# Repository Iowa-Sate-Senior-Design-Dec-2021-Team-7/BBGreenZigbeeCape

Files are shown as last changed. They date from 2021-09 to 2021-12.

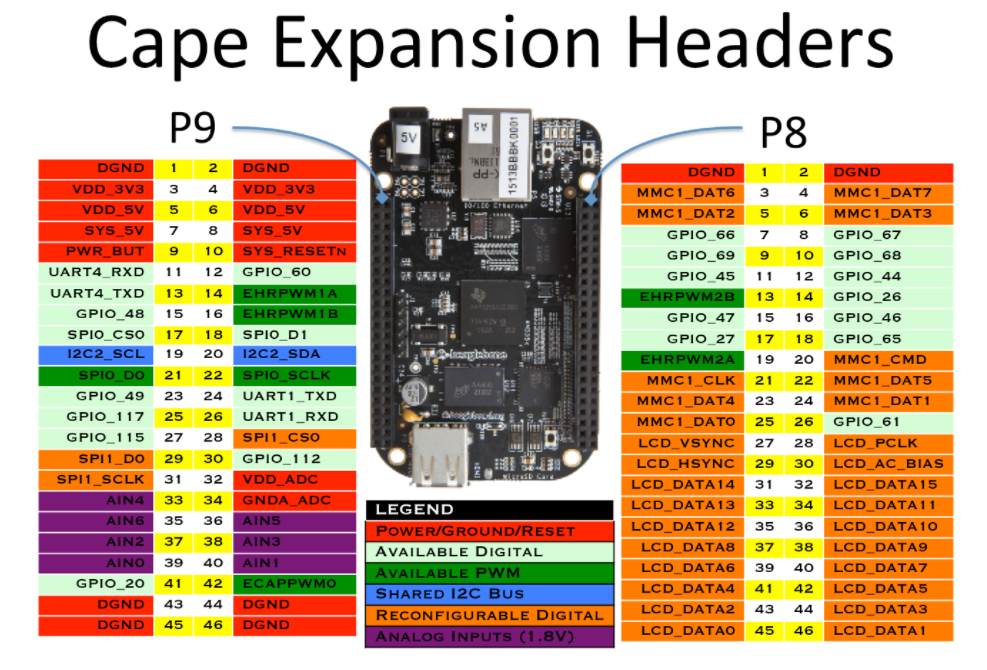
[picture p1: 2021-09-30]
hardware/datasheets/Pictures/Cape_Headers.PNG

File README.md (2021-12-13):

# Iowa State Senior Design December 2021 -- BeagleBone Green Gateway IoT Hub

---

## Website
[Iowa State Senior Design December 2021: Group 7](https://sddec21-07.sd.ece.iastate.edu)

## Hackster.io page
[Hackster.io: BeagleBone Green Wireless Zigbee Cape](https://www.hackster.io/iowa-state-senior-design-dec-2021-proj7/BeagleBone-green-wireless-zigbee-cape-c2da61)

## Project email
sddec21-07@iastate.edu

## Devs:
	- Parker Larsen (pjlarsen)
	- Taylor Weil (tcweil)
	- Sean Griffen (griffens)
	- Sterling Hulling (shulling)

---

See CHANGELOG.md for official release updates/changes

---

### For a description of devices and code used, go to the Wiki:
[Wiki: Home](https://github.com/iowa-state-senior-design-dec-2021-proj7/BBGreenZigbeeCape/wiki)

### To get started, go to the `Getting Started` Wiki:
[Wiki: Getting Started](https://github.com/iowa-state-senior-design-dec-2021-proj7/BBGreenZigbeeCape/wiki/Getting-Started)

---

### Directory Roles:
	- `hardware/`: for pcb designs created and other hardware-specific resources
	- `firmware/`: for code being deployed on the BeagleBone Green Gateway, IoT cape, or other created daughter boards
	- `software/`: for code not being deployed on a hardware module. i.e. web-servers, apps, and other non-controller code
	- `docs/`: for project documents

---

### Scope:
	Research a new or existing wireless technology and add it to the BeagleBone Green and build an IoT network to demonstrate its new capabilities.

### Stretch scope:
	1. Create a system of printed circuit boards to connect to the Zigbee network to show the capabilities and use cases of the Zigbee network.
	2. Program and debug the CC1352 microcontroller Using UART.
	3. Create a data-collection demo to demonstrate basic interactions between the Cape's Zigbee network and the BeagleBone's capabilities
	4. Extend the demo to demonstrate the BeagleBone controlling/commanding Zigbee network devices
	5. Extend the demo to demonstrate devices on the Zigbee network controlling/commanding other Zigbee network devices

---

### Requirements:
	1. Create printed circuit board to allow the BeagleBone to connect to a Zigbee network.
	2. Establish communication between the Cape and the BeagleBone using UART
	3. Create a data-collection demo to demonstrate basic interactions between the Cape's Zigbee network and the BeagleBone's capabilities

### Stretch Requirements:
	1. Create a system of printed circuit boards to connect to the Zigbee network to show the capabilities and use cases of the Zigbee network.
	2. Program and the CC1352 microcontroller using UART.
	3. Extend the communication between the Cape and the BeagleBone to SPI and I2C
	4. Create a demo to show the uses of the BeagleBone's new capabilities
		1. Show that data can be collected from devices on the Cape's Zigbee network
		2. Show that the BeagleBone can see devices on the Cape's Zigbee network and what each device does
		3. Show that the BeagleBone can send commands to devices on the Cape's Zigbee network
		4. Show that devices on the Cape's Zigbee network can send commands to other devices on the same network
	5. Build in support for IFTT using the BeagleBone as an interface for devices on the Cape's Zigbee network
	6. Build in support for MQTT using the BeagleBone as an interface for devices on the Cape's Zigbee network
	7. Build in support for home automation software (HomeAssistant and/or OpenHAB) using the BeagleBone as an interface for devices on the Cape's Zigbee network

---

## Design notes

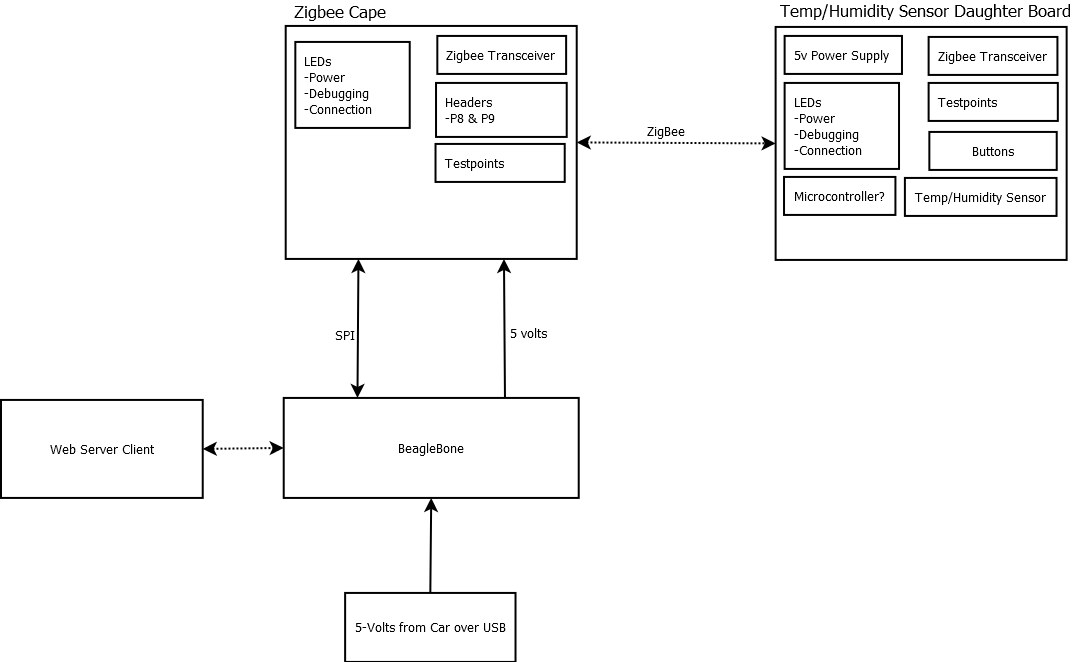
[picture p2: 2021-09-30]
docs/concepts/BlockDiagram.png

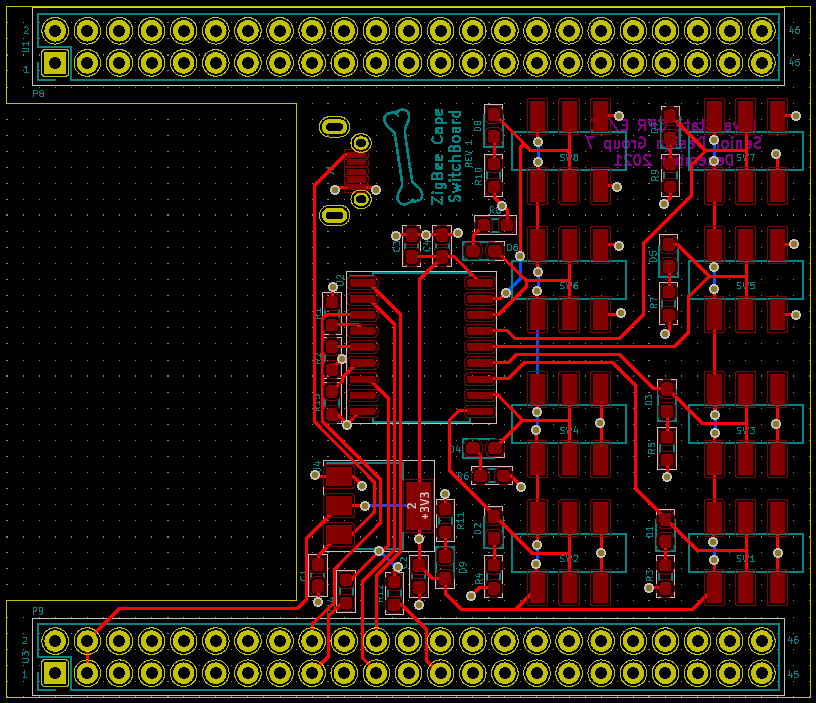
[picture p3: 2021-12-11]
hardware/datasheets/Pictures/SwitchBoard Layout.PNG

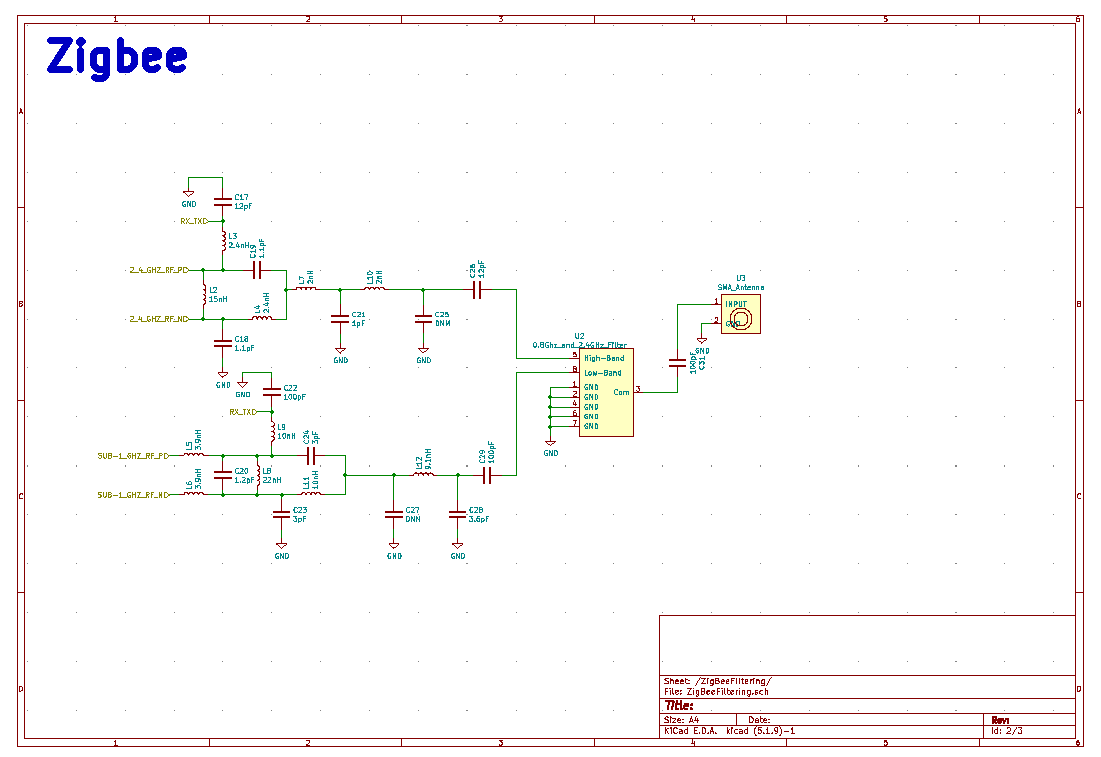
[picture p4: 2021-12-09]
hardware/datasheets/Pictures/SchematicZigBee.PNG

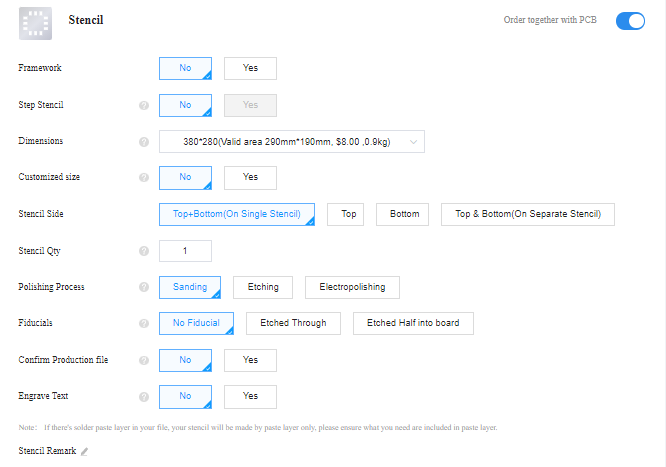
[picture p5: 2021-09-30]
hardware/datasheets/Pictures/JLCStencil.PNG

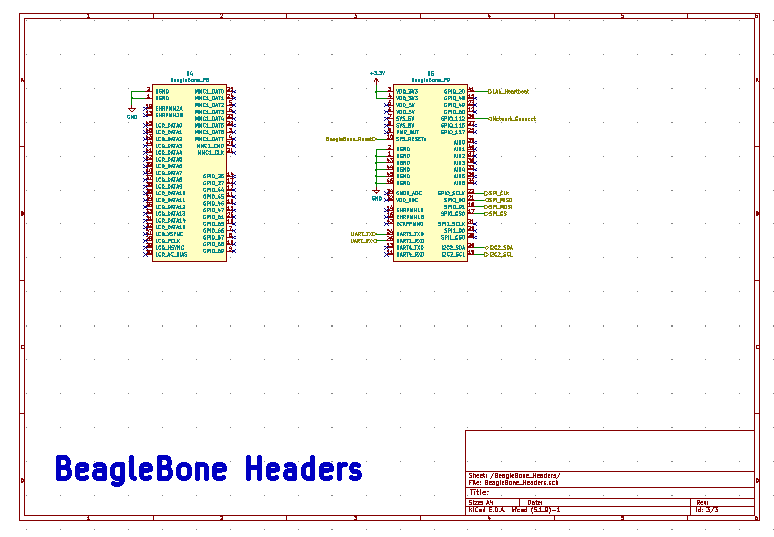
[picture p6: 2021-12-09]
hardware/datasheets/Pictures/SchematicBeagleBoneHeaders.PNG

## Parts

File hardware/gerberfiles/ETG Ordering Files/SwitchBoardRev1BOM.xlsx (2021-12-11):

REF | Value | Footpring |  | Digikey Part number | Quantity per board | Total Quantity
> C1, C2, C4 | 10uF | Capacitor_SMD:C_0603_1608Metric_Pad1.08x0.95mm_HandSolder | ~ | 1276-1038-1-ND | 3 | 7
C3 | 1uF | Capacitor_SMD:C_0603_1608Metric_Pad1.08x0.95mm_HandSolder | ~ | 311-1372-1-ND | 1 | 3
> D1-D9 | RED | Diode_SMD:D_0603_1608Metric_Pad1.05x0.95mm_HandSolder | ~ | 732-4978-1-ND | 9 | 19
J1 | USB_B_Micro | microusb:UJ2-MIBH2-4-SMT-TR | ~ | 102-4007-1-ND | 1 | 3
> R1, R2, R15 | 10k | Resistor_SMD:R_0603_1608Metric_Pad0.98x0.95mm_HandSolder | ~ | RMCF0603FT10K0CT-ND | 3 | 7
> R3-R11 | 100 | Resistor_SMD:R_0603_1608Metric_Pad0.98x0.95mm_HandSolder | ~ | 118-CR0603AFX-1000ELFCT-ND | 9 | 19
R12 | DNP | Resistor_SMD:R_0603_1608Metric_Pad0.98x0.95mm_HandSolder | ~ |  | 1 | 3
R14 | 0 | Resistor_SMD:R_0603_1608Metric_Pad0.98x0.95mm_HandSolder | ~ | 541-0.0GCT-ND | 1 | 3
> SW1-SW8 | SW_SPDT | DPDT_Switch:DPDT | ~ | 401-2002-1-ND | 8 | 17
U1 | BeagleBone_P8 | Connector_PinHeader_2.54mm:PinHeader_2x23_P2.54mm_Vertical |  | 1528-1365-ND | 1 | 3
U2 | MCP23S08 | Package_SO:SOIC-18W_7.5x11.6mm_P1.27mm |  | MCP23S08-E/SO-ND | 1 | 3
U3 | BeagleBone_P9 | Connector_PinHeader_2.54mm:PinHeader_2x23_P2.54mm_Vertical |  | NA | 1 | 3
U4 | NCP1117-3.3_SOT223 | Package_TO_SOT_SMD:SOT-223-3_TabPin2 | http://www.onsemi.com/pub_link/Collateral/NCP1117-D.PDF | NCP1117ST33T3GOSCT-ND | 1 | 3

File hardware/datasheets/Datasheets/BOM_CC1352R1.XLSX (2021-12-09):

Design Modify Date = Tuesday, November 06, 2018
RevCode = B
Title = LAUNCHXL-CC1352R1
Part Number | Quantity | Part Reference | Value | Description | Vendor | Vendor Part Number
02-07617 | 8 | C1 C9 C11 C15 C81 C88 C89 C91 | 12pF | CAPACITOR, CERAMIC C0G/NP0, 12pF, 50V, -5%/+5%, -55DEGC/+125DEGC, 0402, SMD | MURATA | GRM1555C1H120JA01D
02-07775 | 8 | C2 C3 C4 C7 C50 C109 C166 C484 | 10nF | CAPACITOR, CERAMIC X7R, 10nF, 25V, -10%/+10%, -55DEGC/+125DEGC, 0402, SMD | MURATA | GRM155R71E103KA01D
02-06085 | 7 | C6 C78 C79 C80 C83 C84 C87 | 100nF | CAPACITOR, CERAMIC X5R, 100nF, 10V, -10%/+10%, -55DEGC/+85DEGC, 0201, SMD | MURATA | GRM033R61A104KE84D
02-07861 | 40 | C8 C30 C38 C39 C43 C46 C70 C71 C72 C73 C74 C75 C110 C114 C115 C116 C118 C119 C120 C125 C126 C127 C139 C140 C141 C152 C154 C158 C161 C162 C164 C175 C220 C221 C342 C351 C441 C451 C481 C485 | 0.1uF | CAPACITOR, CERAMIC X7R, 0.1uF, 25V, -10%/+10%, -55DEGC/+125DEGC, 0402, SMD | MURATA | GRM155R71E104KE14D
02-07926 | 2 | C12 C21 | 1.1pF | CAPACITOR, CERAMIC C0G/NP0, 1.1pF, 50V, -0.1pF/+0.1pF, -55DEGC/+125DEGC, 0402, SMD | MURATA | GRM1555C1H1R1BA01D
02-07927 | 1 | C13 | 1pF | CAPACITOR, CERAMIC C0G/NP0, 1pF, 50V, -0.1pF/+0.1pF, -55DEGC/+125DEGC, 0402, SMD | MURATA | GRM1555C1H1R0BA01D
DNM | 0 | C14 | DNM | DNM | DNM | DNM
DNM | 0 | C24 | DNM | DNM | DNM | DNM
02-07940 | 1 | C31 | 1.2pF | CAPACITOR, CERAMIC C0G/NP0, 1.2pF, 50V, -0.1pF/ +0.1pF, -55DEGC/+125DEGC, 0402, SMD | MURATA | GRM1555C1H1R2BA01D
02-07619 | 3 | C32 C36 C482 | 100pF | CAPACITOR, CERAMIC C0G/NP0, 100pF, 50V, -5%/+5%, -55DEGC/+125DEGC, 0402, SMD | MURATA | GRM1555C1H101JA01D
02-07625 | 2 | C33 C41 | 3pF | CAPACITOR, CERAMIC C0G/NP0, 3pF, 50V, -0.25pF/+0.25pF, -55DEGC/+125DEGC, 0402, SMD | MURATA | GRM1555C1H3R0CA01D
DNM | 0 | C34 | DNM | DNM | DNM | DNM
02-07631 | 1 | C35 | 3.6pF | CAPACITOR, CERAMIC C0G/NP0, 3.6pF, 50V, -0.25pF/+0.25pF, -55DEGC/+125DEGC, 0402, SMD | MURATA | GRM1555C1H3R6CA01D
DNM | 0 | C37 C483 | DNM | DNM | DNM | DNM
02-07863 | 10 | C40 C42 C44 C128 C133 C136 C137 C138 C145 C231 | 1uF | CAPACITOR, CERAMIC X5R, 1uF, 16V, -10%/+10%, -55DEGC/+85DEGC, 0402, SMD | MURATA | GRM155R61C105KA12D
02-06058 | 12 | C45 C48 C49 C143 C144 C149 C151 C155 C157 C159 C160 C163 | 2.2uF | CAPACITOR, CERAMIC X5R, 2.2uF, 25V, -10%/+10%, -55DEGC/+85DEGC, 0402, SMD | MURATA | GRM155R61E225KE11D
02-07776 | 3 | C47 C153 C172 | 15pF | CAPACITOR, CERAMIC C0G/NP0, 15pF, 50V, -5%/+5%, -55DEGC/+125DEGC, 0402, SMD | MURATA | GRM1555C1H150JA01D
02-07629 | 2 | C85 C86 | 4.7uF | CAPACITOR, CERAMIC X5R, 4.7uF, 6.3V, -20%/+20%, -55DEGC/+85DEGC, 0402, SMD | MURATA | GRM155R60J475ME87D
02-04479 | 1 | C108 | 33nF | CAPACITOR, CERAMIC X7R, 33nF, 25V, -10%/+10%, -55DEGC/+125DEGC, 0402, SMD | MURATA | GRM155R71E333KA88D
02-05897 | 1 | C111 | 3.3uF | CAPACITOR, CERAMIC X5R, 3.3uF, 10V, -10%/+10%, -55DEGC/+85DEGC, 0603, SMD | MURATA | GRM188R61A335KE15D
02-04936 | 1 | C112 | 220uF | CAPACITOR, TANTALUM, 220uF, 10V, -10%/+10%, -55DEGC/+125DEGC, 7343-20, SMD | AVX | TPSY227K010R0100
02-07053 | 7 | C113 C156 C165 C171 C174 C331 C341 | 22uF | CAPACITOR, CERAMIC, X5R, 22uF, 6.3V, -20%/+20%, -55DEGC/+85DEGC, 0603, SMD | MURATA | GRM188R60J226MEA0D
02-05775 | 6 | C117 C121 C122 C142 C147 C168 | 10uF | CAPACITOR, CERAMIC X7R, 10uF, 16V, -10%/+10%, -55DEGC/+125DEGC, 0805, SMD | SAMSUNG ELECTRO-MECHANICS | CL21B106KOQNNNE
02-08708 | 2 | C123 C135 | 270pF | CAPACITOR, CERAMIC C0G/NP0, 270pF, 50V, -1%/+1%, -55DEGC/+125DEGC, 0402, SMD | MURATA | GRM1555C1H271FA01D
DNM | 0 | C124 C132 C134 C170 | DNM | DNM | DNM | DNM
02-00613 | 1 | C129 | 470pF | CAPACITOR, CERAMIC X7R, 470pF, 50V, -10%/+10%, -55DEGC/+125DEGC, 0402, SMD | MURATA | GRM155R71H471KA01D
02-02070 | 1 | C130 | 1nF | CAPACITOR, CERAMIC X7R, 1nF, 50V, -10%/+10%, -55DEGC/+125DEGC, 0402, SMD | MURATA | GRM155R71H102KA01D
02-05294 | 1 | C131 | 22nF | CAPACITOR, CERAMIC X7R, 22nF, 25V, -10%/+10%, -55DEGC/+125DEGC, 0402, SMD | MURATA | GRM155R71E223KA61D
02-07728 | 1 | C146 | 47uF | CAPACITOR, CERAMIC X5R, 47uF, 10V, -20%/+20%, -55DEGC/+85DEGC, 0805, SMD | MURATA | GRM21BR61A476ME15L
DNM | 0 | C169 | DNM | DNM | DNM | DNM
02-08923 | 1 | C486 | 220uF | CAPACITOR, CERAMIC X5R, 220uF, 6.3V, -20%/+20%, -55DEGC/+85DEGC, 1210, SMD | MURATA | GRM32ER60J227ME05L
15-01023 | 2 | CR1 CR5 | LPL296-J2L2-25 | OPTO, LED, GREEN COLOR, 562nm, 0.02A, 0.08W, 0603, SMD | OSRAM | LP L296-J2L2-25
15-01169 | 2 | CR2 CR4 | LS L296-P2Q2-1 | OPTO, LED, SUPER RED COLOR, 630nm, 1.8V TO 2.3V, 0.06A, 0603, SMD | OSRAM | LS L296-P2Q2-1
14-06172 | 1 | CR6 | TPD4E004DRY | DIODE, PROTECTION, ESD ARRAY, 4 CHANNEL, 6V TO 8V, -40DEGC/+85DEGC, SON6, SMD | TEXAS INSTRUMENTS | TPD4E004DRYR
14-05493 | 2 | CR7 CR8 | TPD6E004RSER | DIODE, PROTECTION, ESD ARRAY - 6 CHANNELS, 7V, -40DEGC/+85DEGC, QFN8, SMD | TEXAS INSTRUMENTS | TPD6E004RSER
DNM | 0 | CR14 | DNM | DNM | DNM | DNM
14-03076 | 1 | CR15 | MBR130T1 | DIODE, SCHOTTKY, 1A, 30V, -65DEGC/+125DEGC, SOD-123, SMD | ON SEMICONDUCTOR | MBR130T1G
04-00470 | 4 | FL1 FL2 FL4 FL5 | BLM18HE152SN1 | FILTER, EMI, 1500@100MHz, -55DEGC/+125DEGC, 0603, SMD | MURATA | BLM18HE152SN1D
04-00869 | 1 | FL3 | LFD21829MDKED859 | FILTER, OTHER, 698MHz TO 960MHz / 1710MHz TO 2690MHz, -40DEGC/+85DEGC, SMD | MURATA | LFD21829MDKED859
06-04997 | 2 | J1 J2 | SSQ-110-23-L-D | CONNECTOR, HEADER, FEMALE, STRAIGHT, 2 ROWS, 20 ROWS, 2.54mm, PTH | SAMTEC | SSQ-110-23-L-D
06-04998 | 1 | J6 | 105164-0001 | CONNECTOR, USB, FEMALE, RIGHT ANGLE, 1 ROW, 5 PINS, PITCH 0.65mm, SMD | MOLEX | 105164-0001
06-02188 | 1 | J7 | SMA-10V21-TGG | CONNECTOR, COAX, RF, FEMALE, STRAIGHT, 1 PIN, SMD | HUS-TSAN | SMA-10V21-TGG
03-06637 | 1 | L11 | 15nH | INDUCTOR, RF, CHIP, NON-MAGNETIC CORE, 15nH, -5%/+5%, 0.3A, -55DEGC/+125DEGC, 0402, SMD | MURATA | LQG15HS15NJ02D
03-07526 | 2 | L12 L21 | 2.4nH | INDUCTOR, RF, CHIP, NON-MAGNETIC CORE, 2.4nH, -0.3nH/+0.3nH, 0.3A, -55DEGC/+125DEGC, 0402, SMD | MURATA | LQG15HS2N4S02D
03-07527 | 2 | L13 L14 | 2nH | INDUCTOR, RF, CHIP, NON-MAGNETIC CORE, 2nH, -0.3nH/+0.3nH, 0.3A, -55DEGC/+125DEGC, 0402, SMD | MURATA | LQG15HS2N0S02D
03-06630 | 2 | L31 L41 | 3.9nH | INDUCTOR, RF, CHIP, NON-MAGNETIC CORE, 3.9nH, -0.3nH/+0.3nH, 0.3A, -55DEGC/+125DEGC, 0402, SMD | MURATA | LQG15HS3N9S02D
03-07529 | 1 | L32 | 22nH | INDUCTOR, RF, CHIP, NON-MAGNETIC CORE, 22nH, -5%/+5%, 0.3A, -55DEGC/+125DEGC, 0402, SMD | MURATA | LQG15HS22NJ02D
03-06635 | 2 | L33 L42 | 10nH | INDUCTOR, RF, CHIP, NON-MAGNETIC CORE, 10nH, -5%/+5%, 0.3A, -55DEGC/+125DEGC, 0402, SMD | MURATA | LQG15HS10NJ02D
03-07976 | 1 | L34 | 9.1nH | INDUCTOR, RF, CHIP, 0402, NON-MAGNETIC CORE, 9.1nH, -5%/+5%, 0.5A, -55DEGC/+125DEGC, 0402, SMD | MURATA | LQG15HS9N1J02D
03-07266 | 1 | L331 | 6.8uH | INDUCTOR, STANDARD, CHIP, FERRITE CORE, SHIELDED, 6.8uH, -20%/+20%, 1.1A, -55DEGC/+125DEGC, 0805, SMD | TDK | MLZ2012N6R8LT000
04-00050 | 3 | L332 L333 L334 | BLM21PG221SN1 | FILTER, EMI, FERRITE BEAD, 220@100MHz, -25%/+25%, -55DEGC/+125DEGC, 0805, SMD | MURATA | BLM21PG221SN1D
19-00498 | 11 | M1 M2 M3 M4 M5 M6 M7 M8 M9 M10 M14 | SNT-100-BK-G | MECHANIC, SHUNT, CURRENT RATING 4.3A PER PIN, 2.54 X 5.08 X 6.1mm, BLACK | SAMTEC | SNT-100-BK-G
DNM | 0 | M11 M12 M13 | DNM | DNM | DNM | DNM
13-04664 | 4 | M15 M16 M17 M18 | DCB-10 | MECHANIC, ACCESSORY, SPACER SUPPORT, PCB DIA. 3mm, NYLON 66, PTH | SUZHOU SOLY ELECTRICIAN | DCB-10
06-05038 | 3 | P1 P2 P10 | BB02-HC031-KB1-603000 | CONNECTOR, HEADER, MALE, STRAIGHT, 1 ROW, 3 PINS, PITCH 2.54mm, PTH | GRADCONN | BB02-HC031-KB1-603000
06-05049 | 1 | P4 | BB02-HJ221-KB1-603000 | CONNECTOR, HEADER, MALE, STRAIGHT, 2 ROWS, 22 PINS, PITCH 2.54mm, PTH | GRADCONN | BB02-HJ221-KB1-603000
06-00166 | 2 | P5 P7 | FTSH-105-01-F-DV-K | CONNECTOR, HEADER, MALE, STRAIGHT, 2 ROWS, 10 PINS, PITCH 1.27mm, SMD | SAMTEC | FTSH-105-01-F-DV-K
06-04999 | 1 | P6 | BB02-HJ041-KB1-603000 | CONNECTOR, HEADER, MALE, STRAIGHT, 2 ROWS, 4 PINS, PITCH 2.54mm, PTH | GRADCONN | BB02-HJ041-KB1-603000
DNM | 0 | P8 | DNM | DNM | DNM | DNM
06-05051 | 2 | P11 P12 | MM5829-2700 | CONNECTOR, COAX, MALE, UP TO 12GHz, 30V, SMD | MURATA | MM5829-2700RJ4
19-00925 | 1 | PCB1 | WCS038 | NON COMPONENT, PCB, TEXAS INSTRUMENTS | TEXAS INSTRUMENTS | PCB
01-20043 | 4 | R1 R48 R49 R51 | 0 | RESISTOR, THICK FILM, 0, 0R/+0.02R, 0.1W, 75V, -55DEGC/+155DEGC, 0603, SMD | VISHAY | CRCW06030000Z0EC
01-22488 | 3 | R2 R3 R58 | 3.3k | RESISTOR, THICK FILM, 3.3k, -5%/+5%, 0.063W, 50V, -55DEGC/+155DEGC, 0402, SMD | VISHAY | CRCW04023K30JNED
01-22487 | 1 | R11 | 2.2k | RESISTOR, THICK FILM, 2.2k, -5%/+5%, 0.063W, 50V, -55DEGC/+155DEGC, 0402, SMD | VISHAY | CRCW04022K20JNED
01-22345 | 2 | R14 R23 | 180 | RESISTOR, THICK FILM, 180, -5%/+5%, 0.063W, 50V, -55DEGC/+155DEGC, 0402, SMD | VISHAY | CRCW0402180RJNED
01-22346 | 2 | R15 R25 | 220 | RESISTOR, THICK FILM, 220, -5%/+5%, 0.063W, 50V, -55DEGC/+155DEGC, 0402, SMD | VISHAY | CRCW0402220RJNED
01-22353 | 1 | R17 | 10k | RESISTOR, THICK FILM, 10k, -5%/+5%, 0.063W, 50V, -55DEGC/+155DEGC, 0402, SMD | VISHAY | CRCW040210K0JNED
01-22489 | 3 | R18 R126 R353 | 4.7k | RESISTOR, THICK FILM, 4.7k, -5%/+5%, 0.063W, 50V, -55DEGC/+155DEGC, 0402, SMD | VISHAY | CRCW04024K70JNED
01-22482 | 4 | R20 R55 R56 R57 | 100 | RESISTOR, THICK FILM, 100, -5%/+5%, 0.063W, 50V, -55DEGC/+155DEGC, 0402, SMD | VISHAY | CRCW0402100RJNED
DNM | 0 | R21 | DNM | DNM | DNM | DNM
01-22486 | 4 | R27 R29 R30 R39 | 1k | RESISTOR, THICK FILM, 1k, -5%/+5%, 0.063W, 50V, -55DEGC/+155DEGC, 0402, SMD | VISHAY | CRCW04021K00JNED
01-22494 | 1 | R28 | 4.87k | RESISTOR, THICK FILM, 4.87k, -1%/+1%, 0.063W, 50V, -55DEGC/+155DEGC, 0402, SMD | VISHAY | CRCW04024K87FKED
01-22481 | 1 | R31 | 51 | RESISTOR, THICK FILM, 51, -5%/+5%, 0.063W, 50V, -55DEGC/+155DEGC, 0402, SMD | VISHAY | CRCW040251R0JNED
01-22477 | 1 | R32 | 33k | RESISTOR, THICK FILM, 33k, -1%/+1%, 0.063W, 50V, -55DEGC/+155DEGC, 0402, SMD | VISHAY | CRCW040233K0FKED
01-22491 | 3 | R33 R132 R151 | 51k | RESISTOR, THICK FILM, 51k, -5%/+5%, 0.063W, 50V, -55DEGC/+155DEGC, 0402, SMD | VISHAY | CRCW040251K0JNED
01-22490 | 4 | R34 R133 R135 R152 | 30k | RESISTOR, THICK FILM, 30k, -5%/+5%, 0.063W, 50V, -55DEGC/+155DEGC, 0402, SMD | VISHAY | CRCW040230K0JNED
DNM | 0 | R46 R47 R52 | DNM | DNM | DNM | DNM
DNM | 0 | R59 R60 | DNM | DNM | DNM | DNM
01-22536 | 5 | R61 R62 R63 R65 R114 | 100k | RESISTOR, THICK FILM, 100k, -1%/+1%, 0.063W, 50V, -55DEGC/+155DEGC, 0402, SMD | TT ELECTRONICS | WCR0402-100KFA
01-04196 | 3 | R82 R83 R92 | 10k | RESISTOR, THICK FILM, 10k, -5%/+5%, 0.05W, 30V, -55DEGC/+155DEGC, 0201, SMD | VISHAY | CRCW020110K0JNED
01-04087 | 1 | R84 | 12k | RESISTOR, THICK FILM, 12k, -1%/+1%, 0.05W, 30V, -55DEGC/+155DEGC, 0201, SMD | VISHAY | CRCW020112K0FKED
01-22476 | 1 | R87 | 1Meg | RESISTOR, THICK FILM, 1M, -1%/+1%, 0.063W, 50V, -55DEGC/+155DEGC, 0402, SMD | VISHAY | CRCW04021M00FKED
01-04172 | 2 | R90 R91 | 1k | RESISTOR, THICK FILM, 1k, -5%/+5%, 0.05W, 30V, -55DEGC/+155DEGC, 0201, SMD | VISHAY | CRCW02011K00JNED
01-04203 | 1 | R93 | 20k | RESISTOR, THICK FILM, 20k, -5%/+5%, 0.05W, 30V, -55DEGC/+155DEGC, 0201, SMD | VISHAY | CRCW020120K0JNED
01-01183 | 1 | R94 | 22 | RESISTOR, THICK FILM, 22, -5%/+5%, 0.063W, 50V, -55DEGC/+155DEGC, 0402, SMD | VISHAY | CRCW040222R0JNED
01-00128 | 4 | R95 R101 R109 R120 | 1.2k | RESISTOR, THICK FILM, 1.2k, -1%/+1%, 0.063W, 50V, -55DEGC/+155DEGC, 0402, SMD | VISHAY | CRCW04021K20FKED
01-22492 | 9 | R96 R97 R98 R105 R117 R118 R119 R136 R351 | 100k | RESISTOR, THICK FILM, 100k, -5%/+5%, 0.063W, 50V, -55DEGC/+155DEGC, 0402, SMD | VISHAY | CRCW0402100KJNED
01-22495 | 4 | R99 R100 R108 R131 | 0 | RESISTOR, THICK FILM, 0, 0.063W, 50V, -55DEGC/+155DEGC, 0402, SMD | VISHAY | CRCW04020000Z0ED
01-00195 | 2 | R102 R110 | 330 | RESISTOR, THICK FILM, 330, -1%/+1%, 0.063W, 50V, -55DEGC/+155DEGC, 0402, SMD | VISHAY | CRCW0402330RFKED
01-04307 | 2 | R103 R112 | 4.99 | RESISTOR, THICK FILM, 4.99, -1%/+1%, 0.063W, 50V, -55DEGC/+155DEGC, 0402, SMD | VISHAY | CRCW04024R99FKED
01-00234 | 3 | R104 R113 R354 | 10 | RESISTOR, THICK FILM, 10, -1%/+1%, 0.063W, 50V, -55DEGC/+155DEGC, 0402, SMD | VISHAY | CRCW040210R0FKED
DNM | 0 | R106 R111 | DNM | DNM | DNM | DNM
01-03527 | 1 | R107 | 1 | RESISTOR, THICK FILM, 1, -1%/+1%, 1W, 200V, -55DEGC/+155DEGC, 1218, SMD | VISHAY | CRCW12181R00FNEK
DNM | 0 | R115 | DNM | DNM | DNM | DNM
01-04658 | 2 | R116 R134 | 60.4k | RESISTOR, THICK FILM, 60.4k, -1%/+1%, 0.063W, 50V, -55DEGC/+155DEGC, 0402, SMD | VISHAY | CRCW040260K4FKED
01-01252 | 1 | R121 | 22k | RESISTOR, THICK FILM, 22k, -5%/+5%, 0.063W, 50V, -55DEGC/+155DEGC, 0402, SMD | VISHAY | CRCW040222K0JNED
01-20687 | 1 | R122 | 0.22 | RESISTOR, THICK FILM, 0.22, -1%/+1%, 0.125W, -55DEGC/+155DEGC, 0402, SMD | VISHAY | RCWE0402R220FKEA
01-06917 | 1 | R123 | 82 | RESISTOR, THICK FILM, 82, -1%/+1%, 0.25W, 200V, -55DEGC/+155DEGC, 1206, SMD | VISHAY | CRCW120682R0FKEA
01-07315 | 1 | R125 | 36.5 | RESISTOR, THICK FILM, 36.5, -1%/+1%, 0.5W, 200V, -55DEGC/+155DEGC, 1210, SMD | VISHAY | CRCW121036R5FKEA
01-01260 | 3 | R127 R128 R129 | 47k | RESISTOR, THICK FILM, 47k, -5%/+5%, 0.063W, 50V, -55DEGC/+155DEGC, 0402, SMD | VISHAY | CRCW040247K0JNED
01-00239 | 1 | R130 | 2.2k | RESISTOR, THICK FILM, 2.2k, -1%/+1%, 0.063W, 50V, -55DEGC/+155DEGC, 0402, SMD | VISHAY | CRCW04022K20FKED
01-04542 | 1 | R137 | 2.61k | RESISTOR, THICK FILM, 2.61k, -1%/+1%, 0.063W, 50V, -55DEGC/+155DEGC, 0402, SMD | VISHAY | CRCW04022K61FKED
DNM | 0 | R138 | DNM | DNM | DNM | DNM
01-04141 | 9 | R140 R141 R142 R143 R144 R145 R146 R147 R148 | 51 | RESISTOR, THICK FILM, 51, -5%/+5%, 0.05W, 30V, -55DEGC/+155DEGC, 0201, SMD | VISHAY | CRCW020151R0JNED
08-00293 | 3 | SW1 SW2 SW3 | 1188E-1K2-V | SWITCH, TACT, 0.05A@250VAC, 0.05A@12VDC, 0.05A, 250V, SMD | DIPTRONICS | 1188E-1K2-V-TR
18-33499 | 1 | U1 | CC1352R1F3RGZ | IC, DIGITAL, WIRELESS, QFN48, SMD | TEXAS INSTRUMENTS | CC1352R1F3RGZT
18-31726 | 1 | U4 | MX25R8035FZUIL0 | IC, MEMORY, FLASH, SERIAL, 8Mbit, 1.65V TO 3.6V, USON8, SMD | MACRONIX | MX25R8035FZUIL0
18-29558 | 1 | U6 | LM4040B25IDCK | IC, ANALOG, PRECISION MICROPOWER SHUNT VOLTAGE REFERENCE, 2.5V, SC70-5, SMD | TEXAS INSTRUMENTS | LM4040B25IDCKR
18-29530 | 3 | U7 U42 U46 | TPS79601DR | IC, ANALOG, ULTRALOW-NOISE, HIGH PSRR, FAST, RF, 1A LOW-DROPOUT LINEAR REGULATORS, VIN:2.7V TO 5.5V, VOUT:1.2V TO 5.5V, SON8, SMD | TEXAS INSTRUMENTS | TPS79601DRBR
18-29288 | 3 | U8 U9 U10 | SN74AVC4T245RSV | IC, DIGITAL, LOGIC, 4bit DUAL-SUPPLY BUS TRANSCEIVER 3 STATE OUTPUT, 1.2V TO 3.6V, UQFN16, SMD | TEXAS INSTRUMENTS | SN74AVC4T245RSVR
18-26311 | 1 | U15 | USB3300-EZK | IC, DIGITAL, INTERFACE, HI-SPEED USB HOST, 3.3V, QFN32-EP, SMD | MICROCHIP | USB3300-EZK
18-30805 | 2 | U33 U38 | TS3A24159DRC | IC, ANALOG, 0.3R DUAL SPDT ANALOG SWITCH DUAL-CHANNEL 2:1 MULTIPLEXER/DEMULTIPLEXER, 1.65V TO 3.6V, SON10-EP, SMD | TEXAS INSTRUMENTS | TS3A24159DRCR
18-27150 | 1 | U34 | SN74LVC2G74DCU | IC, DIGITAL, LOGIC, D-TYPE FLIP-FLOP WITH CLEAR AND PRESET, 1.65V TO 5.5V, VSSOP8, SMD | TEXAS INSTRUMENTS | SN74LVC2G74DCUR
18-33431 | 1 | U35 | ADS127L01IPBS | IC, MIXED, 24-BIT WIDE-BANDWIDTH ANALOG TO DIGITAL CONVERTER, 2.7V TO 3.6V/1.7V TO 3.6V, TQFP32, SMD | TEXAS INSTRUMENTS | ADS127L01IPBS
18-34413 | 1 | U36 | INA118UB | IC, ANALOG, INSTRUMENTATION AMPLIFIER, -/+15V, SO8, SMD | TEXAS INSTRUMENTS | INA118UB
18-34391 | 1 | U37 | THS4551IRUN | IC, ANALOG, LOW NOISE, PRECISION, 150MHz, FULLY DIFFERENTIAL AMPLIFIER, 2.7V TO 5.4V, QFN10-EP, SMD | TEXAS INSTRUMENTS | THS4551IRUNR
18-30809 | 1 | U39 | TS3A4751RUCR | IC, ANALOG, 0.9R LOW-VOLTAGE SINGLE-SUPPLY QUAD SPST ANALOG SWITCH, 1.6V TO 3.6V, QFN14, SMD | TEXAS INSTRUMENTS | TS3A4751RUCR
18-34390 | 1 | U40 | REF6025IDGK | IC, ANALOG, HIGH PRECISION VOLTAGE REFERENCE, VIN:3V TO 5.5V, VOUT:2.5V, VSSOP8, SMD | TEXAS INSTRUMENTS | REF6025IDGKR
18-32984 | 1 | U41 | OPA320AIDBV | IC, ANALOG, RAIL-TO-RAIL I/O CMOS OPERATIONAL AMPLIFIER, -/+0.9V TO 5.5V, SOT23-5, SMD | TEXAS INSTRUMENTS | OPA320AIDBVT
18-32950 | 1 | U43 | LP5907MFX-1.8 | IC, ANALOG, 0.25A LINEAR REGULATOR FOR RF AND ANALOG CIRCUITS-REQUIRES NO BYPASS CAPACITOR, VIN:2.2V TO 5.5V, VOUT: 1.8V, SOT23-5, SMD | TEXAS INSTRUMENTS | LP5907MFX-1.8/NOPB
18-33642 | 1 | U44 | TPS73101DBV | IC, ANALOG, 0.15A LOW DROPOUT REGULATOR WITH REVERSE CURRENT PROTECTION, VIN:1.7V TO 5.5V, VOUT:1.2V TO 5.5V, SOT23-5, SMD | TEXAS INSTRUMENTS | TPS73101DBVR
DNM | 0 | U45 | DNM | DNM | DNM | DNM
18-34886 | 1 | U47 | TPS259530DSG | IC, ANALOG, EFUSE WITH FAST OVERVOLTAGE PROTECTION, 2.7V TO 18V, WSON8-EP, SMD | TEXAS INSTRUMENTS | TPS259530DSGR
18-29511 | 1 | U5 | TM4C1294NCPDTT3R | IC, MICROCONTROLLER, TIVA C SERIES, ARM CRTEX-M4, 2.97V TO 3.63V, TQFP128, SMD | TEXAS INSTRUMENTS | TM4C1294NCPDTT3R
12-00546 | 1 | Y1 | 32.768kHz | CRYSTAL, RESONATOR, 32.768kHz, -20PPM/+20PPM, -40DEGC/+85DEGC, SMD | EPSON | FC-135 32.7680KA-AG0
12-01233 | 1 | Y2 | 48MHz | CRYSTAL, RESONATOR, 48MHz, -20PPM/+20PPM, -40DEGC/+85DEGC, SMD | KYOCERA | CX2016DB48000C0FPLC1
12-00745 | 1 | Y3 | 16MHz | CRYSTAL, RESONATOR, 16MHz, -30PPM/+30PPM, -40DEGC/+85DEGC, SMD | NIHON DEMPA KOGYO | NX3225GA-16.000M-STD-CRG-1
12-00730 | 1 | Y4 | 24MHz | CRYSTAL, RESONATOR, 24MHz, -50PPM/+50PPM, -40DEGC/+85DEGC, SMD | EPSON | FA-238 24.0000MB50X-W0
12-01320 | 1 | Y5 | 16.384MHz | CRYSTAL, OSCILLATOR, XO, 16.384MHz, -50PPM/+50PPM, 3.3V, -20DEGC/+70DEGC, SMD | CTS COMPONENTS | 636L3C016M38400
03-07708 | 1 | Z60 | 3.3nH | INDUCTOR, RF, CHIP, 0402, NON-MAGNETIC CORE, 3.3nH, -0.5nH/+0.5nH, 0.9A, -55DEGC/+125DEGC, 0402, SMD | MURATA | LQW15AN3N3D10D
DNM | 0 | Z61 | DNM | DNM | DNM | DNM
DNM | 0 | Z62 | DNM | DNM | DNM | DNM
02-07850 | 1 | Z63 | 5.6pF | CAPACITOR, CERAMIC C0G, 5.6pF, 50V, -0.25pF/+0.25pF, -55DEGC/+125DEGC, 0402, SMD | MURATA | GRM1555C1H5R6CA01D

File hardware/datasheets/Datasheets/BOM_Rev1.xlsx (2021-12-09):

Reference | Quantity | Value | Footprint | Datasheet | Description | Manufacturer | Digi-Key Part Number | Digi-Key Listing
AE1 | 1 | Antenna |  |  | PCB printed antenna
C1 C2 C3 | 3 | DNM_1uF | 0603 | http://www.calchipelectronics.com/pdf/gmc_series.pdf | ±10% 16V Ceramic Capacitor X5R 0603 (1608 Metric | Cal-Chip Electronics | 2571-GMC10X5R105K16NTTR-ND | GMC10X5R105K16NT CAL-CHIP ELECTRONICS, INC. | Capacitors | DigiKey Marketplace (https://www.digikey.com/en/products/detail/cal-chip-electronics-inc/GMC10X5R105K16NT/13909090)
C10 C11 | 2 | 22uF | 0603 | http://www.calchipelectronics.com/pdf/gmc_series.pdf | ±20% 6.3V Ceramic Capacitor X5R 0603 (1608 Metric) | Cal-Chip Electronics | 2571-GMC10X5R226M6R3NTTR-ND | GMC10X5R226M6R3NT CAL-CHIP ELECTRONICS, INC. | Capacitors | DigiKey Marketplace (https://www.digikey.com/en/products/detail/cal-chip-electronics-inc/GMC10X5R226M6R3NT/13909373)
C12 C14 C17 C26 | 4 | 12pF | 0603 | https://www.murata.com/~/media/webrenewal/support/library/catalog/products/capacitor/mlcc/c02e.ashx?la=en-us | ±5% 50V Ceramic Capacitor C0G, NP0 0603 (1608 Metric) | Murata Electronics | 490-1405-1-ND | GRM1885C1H120JA01D Murata Electronics | Capacitors | DigiKey
C15 | 1 | 1uF | 0603 | https://ds.yuden.co.jp/TYCOMPAS/ut/detail?pn=EMK107BJ105KAHT%20%20&u=M | ±10% 16V Ceramic Capacitor X5R 0603 (1608 Metric) | Taiyo Yuden | 587-3309-1-ND | EMK107BJ105KAHT Taiyo Yuden | Capacitors | DigiKey (https://www.digikey.com/en/products/detail/taiyo-yuden/EMK107BJ105KAHT/4157319)
C18 C19 | 2 | 1.1pF | 0603 | https://api.kemet.com/component-edge/download/datasheet/CBR06C119B5GAC.pdf | ±0.1pF 50V Ceramic Capacitor C0G, NP0 0603 (1608 Metric) | KEMET | 399-16141-1-ND | CBR06C119B5GAC KEMET | Capacitors | DigiKey (https://www.digikey.com/en/products/detail/kemet/CBR06C119B5GAC/7649447)
C20 | 1 | 1.2pF | 0805 | https://www.yageo.com/upload/media/product/productsearch/datasheet/mlcc/UPY-GP_NP0_16V-to-50V_18.pdf | ±0.1pF 50V Ceramic Capacitor C0G, NP0 0805 (2012 Metric) | Yageo | 311-4125-1-ND | CC0805BRNPO9BN1R2 Yageo | Capacitors | DigiKey (https://www.digikey.com/en/products/detail/yageo/CC0805BRNPO9BN1R2/5883872)
C21 | 1 | 1pF | 0603 | http://www.samsungsem.com/kr/support/product-search/mlcc/CL10C010BB8NNNC.jsp | ±0.1pF 50V Ceramic Capacitor C0G, NP0 0603 (1608 Metric) | Samsung Electro-Mechanics | 1276-1095-2-ND | CL10C010BB8NNNC Samsung Electro-Mechanics | Capacitors | DigiKey (https://www.digikey.com/en/products/detail/samsung-electro-mechanics/CL10C010BB8NNNC/3886753)
C22 C29 C31 | 3 | 100pF | 0603 | https://www.murata.com/-/media/webrenewal/support/library/catalog/products/capacitor/ceramiccapacitor/c02e.ashx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 | ±5% 50V Ceramic Capacitor C0G, NP0 0603 (1608 Metric) | Murata Electronics | 490-1427-1-ND | GRM1885C1H101JA01D Murata Electronics | Capacitors | DigiKey (https://www.digikey.com/en/products/detail/murata-electronics/GRM1885C1H101JA01D/586921)
C23 C24 | 2 | 3pF | 0603 | https://www.yageo.com/upload/media/product/productsearch/datasheet/mlcc/UPY-GP_NP0_16V-to-50V_18.pdf | ±0.25pF 50V Ceramic Capacitor C0G, NP0 0603 (1608 Metric) | Yageo | 311-1052-1-ND | CC0603CRNPO9BN3R0 Yageo | Capacitors | DigiKey (https://www.digikey.com/en/products/detail/yageo/CC0603CRNPO9BN3R0/302786)
L14 C25 C27 C30 C32 | 5 | DNM | 0603 | ~ | Parts not mounted
C28 | 1 | 3.6pF | 0603 | https://datasheets.avx.com/C0GNP0-Dielectric.pdf | ±0.25pF 50V Ceramic Capacitor C0G, NP0 0603 (1608 Metric) | AVX Corporation | 478-10318-1-ND | 06035A3R6CAT2A AVX Corporation | Capacitors | DigiKey (https://www.digikey.com/en/products/detail/avx-corporation/06035A3R6CAT2A/1599842)
C33 | 1 | 5.6pF | 0603 | http://www.seielect.com/Catalog/SEI-CML.PDF | ±0.25pF 50V Ceramic Capacitor C0G, NP0 0603 (1608 Metric) | Stackpole Electronics Inc | 738-CML0603C0G5R6CT50VCT-ND | CML0603C0G5R6CT50V Stackpole Electronics Inc | Capacitors | DigiKey (https://www.digikey.com/en/products/detail/stackpole-electronics-inc/CML0603C0G5R6CT50V/10660015)
C4 | 1 | DNM_2.2uF | 0603 | https://search.murata.co.jp/Ceramy/image/img/A01X/G101/ENG/GRM188R61E225KA12-01.pdf | ±10% 25V Ceramic Capacitor X5R 0603 (1608 Metric) | Murata Electronics | 490-GRM188R61E225KA12JCT-ND | GRM188R61E225KA12J Murata Electronics | Capacitors | DigiKey (https://www.digikey.com/en/products/detail/murata-electronics/GRM188R61E225KA12J/4905350)
C7 | 1 | 2.2uF | 0603 | https://search.murata.co.jp/Ceramy/image/img/A01X/G101/ENG/GRM188R61E225KA12-01.pdf | ±10% 25V Ceramic Capacitor X5R 0603 (1608 Metric) | Murata Electronics | 490-GRM188R61E225KA12JCT-ND | GRM188R61E225KA12J Murata Electronics | Capacitors | DigiKey (https://www.digikey.com/en/products/detail/murata-electronics/GRM188R61E225KA12J/4905350)
C5 C6 C8 C9 C13 C16 | 6 | 0.1uF | 0603 | https://katalog.we-online.de/pbs/datasheet/885012206071.pdf | ±10% 25V Ceramic Capacitor X7R 0603 (1608 Metric) | Würth Elektronik | 732-7989-1-ND | 885012206071 Würth Elektronik | Capacitors | DigiKey (https://www.digikey.com/en/products/detail/w%C3%BCrth-elektronik/885012206071/5453844)
D1 D2 D3 D4 D5 | 5 | Blue | 0603 | N/A on Digikey | Blue 470nm LED Indication - Discrete 2.85V 0603 (1608 Metric) | OSRAM | LB Q39E-N1OO-35-1 | LB Q39E-N1OO-35-1 OSRAM Opto Semiconductors Inc. | Optoelectronics | DigiKey (https://www.digikey.com/en/products/detail/osram-opto-semiconductors-inc/LB-Q39E-N1OO-35-1/2176321)
D6 | 1 | Green | 0603 | LP L296_EN.pdf | OPTO, LED, GREEN COLOR, 562nm, 0.02A, 0.08W, 0603, SMD | OSRAM | LP L296-J2L2-25 | LP L296-J2L2-25-0-20-R18-Z OSRAM Opto Semiconductors Inc. | Optoelectronics | DigiKey (https://www.digikey.com/en/products/detail/osram-opto-semiconductors-inc/LP-L296-J2L2-25-0-20-R18-Z/2205580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)
J1 | 1 | Conn_ARM_JTAG_SWD_10 |  | http://infocenter.arm.com/help/topic/com.arm.doc.ddi0314h/DDI0314H_coresight_components_trm.pdf
 | 1 | JTAG | 10pin | http://suddendocs.samtec.com/catalog_english/ftsh_smt.pdf | CONNECTOR, HEADER, MALE, STRAIGHT, 2 ROWS, 10 PINS, PITCH 1.27mm, SMD | SAMTEC | FTSH-105-01-F-DV-K | FTSH-105-01-F-DV-K Samtec Inc. | Connectors, Interconnects | DigiKey (https://www.digikey.com/en/products/detail/samtec-inc/FTSH-105-01-F-DV-K/2649974)
L1 | 1 | 6.8uH | 0805 | https://product.tdk.com/info/en/catalog/datasheets/inductor_commercial_decoupling_mlz2012_en.pdf | FIXED IND 6.8UH 350MA 400MOHM SM | TDK Corporation | 445-6402-1-ND | MLZ2012M6R8WT000 TDK Corporation | Inductors, Coils, Chokes | DigiKey (https://www.digikey.com/en/products/detail/tdk-corporation/MLZ2012M6R8WT000/2465159)
L12 | 1 | 9.1nH | 0603 | https://www.coilcraft.com/getmedia/f3d98f97-cbe2-41fa-b3a9-518f674e881e/0603dc.pdf | 9.1 nH Unshielded Wirewound Inductor 2.26 A 60mOhm Max 0603 (1608 Metric) - | COILCRAFT | 2457-0603DC-9N1XJRW-ND | 0603DC-9N1XJRW COILCRAFT | Inductors, Coils, Chokes | DigiKey Marketplace (https://www.digikey.com/en/products/detail/coilcraft/0603DC-9N1XJRW/12714823)
L13 | 1 | 3.3nH | 0402 | https://search.murata.co.jp/Ceramy/image/img/P02/JELF243A-9138.pdf | 3.3 nH Unshielded Wirewound Inductor 2 A 30mOhm Max 0402 (1005 Metric) | Murata Electronics | 490-15421-1-ND | LQW15AN3N3D8ZD Murata Electronics | Inductors, Coils, Chokes | DigiKey (https://www.digikey.com/en/products/detail/murata-electronics/LQW15AN3N3D8ZD/6798846)
L2 | 1 | 15nH | 0805 | https://abracon.com/Magnetics/new/AIMC-0805.pdf | Unshielded Multilayer Inductor 400mOhm Max 0805 (2012 Metric) | Abracon LLC | 535-11556-1-ND | AIMC-0805-15NJ-T Abracon LLC | Inductors, Coils, Chokes | DigiKey (https://www.digikey.com/en/products/detail/abracon-llc/AIMC-0805-15NJ-T/2662926)
L3 L4 | 2 | 2.4nH | 0402 | https://search.murata.co.jp/Ceramy/image/img/P02/JELF243B-0010.pdf | INDUCTOR, RF, CHIP, NON-MAGNETIC CORE, 2.4nH, -0.3nH/+0.3nH, 0.3A, -55DEGC/+125DEGC, 0402, SMD | MURATA | LQG15HS2N4S02D | LQG15HS2N4S02D Murata Electronics | Inductors, Coils, Chokes | DigiKey (https://www.digikey.com/en/products/detail/murata-electronics/LQG15HS2N4S02D/2594219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)
L5 L6 | 2 | 3.9nH | 0603 | https://abracon.com/Magnetics/new/AIMC-0603.pdf | 3.9 nH Unshielded Multilayer Inductor 500 mA 140mOhm Max 0603 (1608 Metric) | Abracon LLC | 535-11540-1-ND | AIMC-0603-3N9S-T Abracon LLC | Inductors, Coils, Chokes | DigiKey (https://www.digikey.com/en/products/detail/abracon-llc/AIMC-0603-3N9S-T/2662892)
L7 L10 | 2 | 2nH | 0402 | https://search.murata.co.jp/Ceramy/image/img/P02/JELF243B-0010.pdf | INDUCTOR, RF, CHIP, NON-MAGNETIC CORE, 2nH, -0.3nH/+0.3nH, 0.3A, -55DEGC/+125DEGC, 0402, SMD | MURATA | LQG15HS2N0S02D | LQG15HS2N0S02D Murata Electronics | Inductors, Coils, Chokes | DigiKey (https://www.digikey.com/en/products/detail/murata-electronics/LQG15HS2N0S02D/1795312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)
L8 | 1 | 22nH | 0603 | https://www.we-online.com/catalog/datasheet/7447860122.pdf | 22 nH Unshielded Multilayer Inductor 300 mA 400mOhm Max 0603 (1608 Metric) - | Würth Elektronik | 732-7447860122CT-ND | 7447860122 Würth Elektronik | Inductors, Coils, Chokes | DigiKey (https://www.digikey.com/en/products/detail/w%C3%BCrth-elektronik/7447860122/12726579)
L9 L11 | 2 | 10nH | 0603 | ~ | 10 nH Unshielded Multilayer Inductor 300 mA 260mOhm Max 0603 (1608 Metric) - | Würth Elektronik | 732-7447860110CT-ND | 7447860110 Würth Elektronik | Inductors, Coils, Chokes | DigiKey (https://www.digikey.com/en/products/detail/w%C3%BCrth-elektronik/7447860110/12726561)
R17 R19 | 2 | 4.7k | 0603 | https://www.nteinc.com/resistor_web/pdf/0625W.pdf | 4.7 kOhms ±5% 0.063W, 1/16W Chip Resistor 0603 (1608 Metric) - Thick Film | NTE Electronics, Inc | 2368-SR1-0603-247-ND | SR1-0603-247 NTE Electronics, Inc | Resistors | DigiKey Marketplace (https://www.digikey.com/en/products/detail/nte-electronics-inc/SR1-0603-247/11649452)
R2 R4 R5 R7 | 4 | 10K | 0603 | https://www.nteinc.com/resistor_web/pdf/0625W.pdf | 10 kOhms ±5% 0.063W, 1/16W Chip Resistor 0603 (1608 Metric) - Thick Film | NTE Electronics, Inc | 2368-SR1-0603-610-ND | SR1-0603-610 NTE Electronics, Inc | Resistors | DigiKey Marketplace (https://www.digikey.com/en/products/detail/nte-electronics-inc/SR1-0603-610/11655708)
R1 R3 | 1 | DNM_10K | 0603 | https://www.nteinc.com/resistor_web/pdf/0625W.pdf | 10 kOhms ±5% 0.063W, 1/16W Chip Resistor 0603 (1608 Metric) - Thick Film | NTE Electronics, Inc | 2368-SR1-0603-610-ND | SR1-0603-610 NTE Electronics, Inc | Resistors | DigiKey Marketplace (https://www.digikey.com/en/products/detail/nte-electronics-inc/SR1-0603-610/11655708)
R6 R8 R9 R10 R11 R12 | 6 | 1k | 0603 | https://www.nteinc.com/resistor_web/pdf/0625W.pdf | 1 kOhms ±5% 0.063W, 1/16W Chip Resistor 0603 (1608 Metric) - Thick Film | NTE Electronics, Inc | 2368-SR1-0603-210-ND | SR1-0603-210 NTE Electronics, Inc | Resistors | DigiKey Marketplace (https://www.digikey.com/en/products/detail/nte-electronics-inc/SR1-0603-210/11648254)
SW1 SW2 SW3 SW4 SW5 | 5 | SW_MEC_5E |  | https://media.digikey.com/pdf/Data%20Sheets/APEM%20Components%20PDFs/MJTP%20Series-6MM.pdf | Tactile Switch SPST-NO Top Actuated Through Hole | APEM Inc. | 679-2428-ND | MJTP1230 APEM Inc. | Switches | DigiKey (https://www.digikey.com/en/products/detail/apem-inc/MJTP1230/1798037)
U1 | 1 | CC1352R
U2 | 1 | 0.8Ghz_and_2.4GHz_Filter |  | https://product.tdk.com/info/en/documents/data_sheet/rf_dpx_dpx252690dt-5032b1_en.pdf | RF Diplexor pval (183) 699MHz ~ 960MHz / 1.71GHz ~ 2.69GHz 0402 (1005 Metric), 8 PC Pad | TDK Corporation | 445-174204-1-ND | DPX252690DT-5032B1 TDK Corporation | RF/IF and RFID | DigiKey (https://www.digikey.com/en/products/detail/tdk-corporation/DPX252690DT-5032B1/5819342)
U3 | 1 | SMA_Antenna |  | https://s3-us-west-2.amazonaws.com/catsy.582/C132134.pdf | SMA Connector Jack, Female Socket 50Ohm Through Hole Solder | Amphenol RF | ACX1230-ND | 132134 Amphenol RF | Connectors, Interconnects | DigiKey (https://www.digikey.com/en/products/detail/amphenol-rf/132134/1011907)
U4 | 1 | BeagleBone_P8 |  | https://cdn-shop.adafruit.com/datasheets/20218.pdf | HEADER STACK BEAGLE BONE 1=2PC | Adafruit Industries LLC | 1528-1365-ND | 706 Adafruit Industries LLC | Development Boards, Kits, Programmers | DigiKey (https://www.digikey.com/en/products/detail/adafruit-industries-llc/706/5629413)
U5 | 1 | BeagleBone_P9 |  | https://cdn-shop.adafruit.com/datasheets/20218.pdf | HEADER STACK BEAGLE BONE 1=2PC | Adafruit Industries LLC | 1528-1365-ND | 706 Adafruit Industries LLC | Development Boards, Kits, Programmers | DigiKey (https://www.digikey.com/en/products/detail/adafruit-industries-llc/706/5629413)
Y1 | 1 | 32.768kHz |  | https://support.epson.biz/td/api/doc_check.php?dl=brief_FC-135&lang=en | 32.768 kHz ±20ppm Crystal 7pF 70 kOhms 2-SMD, No Lead | EPSON | SER4089CT-ND | FC-135 32.768KA-AG0 EPSON | Crystals, Oscillators, Resonators | DigiKey (https://www.digikey.com/en/products/detail/epson/FC-135-32-768KA-AG0/3829773)
Y2 | 1 | 48MHz |  | https://suntsu.com/wp-content/uploads/2020/07/SXT324-Series-1.pdf | 48 MHz ±10ppm Crystal 18pF 40 Ohms 4-SMD, No Lead | Suntsu Electronics, Inc. | 2388-SXT32418FD16-48.000M-ND | SXT32418FD16-48.000MT Suntsu Electronics, Inc. | Crystals, Oscillators, Resonators | DigiKey Marketplace (https://www.digikey.com/en/products/detail/suntsu-electronics-inc/SXT32418FD16-48-000MT/12249197)
Parker's SPST Switch |  |  |  | http://www.apem.com/int/index.php?controller=attachment&id_attachment=1371
 |  |  |  | https://www.digikey.com/en/products/detail/e-switch/TL3305CF160QG/5816183

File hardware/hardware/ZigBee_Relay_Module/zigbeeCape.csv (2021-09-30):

Reference | Quantity | Value | Footprint | Datasheet
C1 C2 C3 | 3 | DNM_1uF | Capacitor_SMD:C_0603_1608Metric_Pad1.08x0.95mm_HandSolder | https://www.digikey.com/en/products/detail/samsung-electro-mechanics/CL10B105KA8NNNC/3886842
C10 C11 | 2 | 22uF | Capacitor_SMD:C_0603_1608Metric_Pad1.08x0.95mm_HandSolder | https://www.digikey.com/en/products/detail/murata-electronics/GRM188R60J226MEA0D/4280542
C12 C14 C17 C26 | 4 | 12pF | Capacitor_SMD:C_0402_1005Metric_Pad0.74x0.62mm_HandSolder | https://www.digikey.com/en/products/detail/murata-electronics/GRM1555C1H120JA01D/3693831
C15 | 1 | 1uF | Capacitor_SMD:C_0603_1608Metric_Pad1.08x0.95mm_HandSolder | https://www.digikey.com/en/products/detail/samsung-electro-mechanics/CL10B105KA8NNNC/3886842
C18 C19 | 2 | 1.1pF | Capacitor_SMD:C_0402_1005Metric_Pad0.74x0.62mm_HandSolder | https://www.digikey.com/en/products/detail/murata-electronics/GRM1555C1H1R1BA01D/3693932
C20 | 1 | 1.2pF | Capacitor_SMD:C_0402_1005Metric_Pad0.74x0.62mm_HandSolder | https://www.digikey.com/en/products/detail/murata-electronics/GRM1555C1H1R2BA01D/3693934
C21 | 1 | 1pF | Capacitor_SMD:C_0402_1005Metric_Pad0.74x0.62mm_HandSolder | https://www.digikey.com/en/products/detail/avx-corporation/04025A1R0BAT2A/1116357
C22 C29 C31 | 3 | 100pF | Capacitor_SMD:C_0402_1005Metric_Pad0.74x0.62mm_HandSolder | https://www.digikey.com/en/products/detail/murata-electronics/GRM1555C1H101JA01D/3693829
C23 C24 | 2 | 3pF | Capacitor_SMD:C_0402_1005Metric_Pad0.74x0.62mm_HandSolder | https://www.digikey.com/en/products/detail/murata-electronics/GRM1555C1H3R0CA01D/3175191
C25 C27 | 2 | DNM | Capacitor_SMD:C_0402_1005Metric_Pad0.74x0.62mm_HandSolder | ~
C28 | 1 | 3.6pF | Capacitor_SMD:C_0402_1005Metric_Pad0.74x0.62mm_HandSolder | https://www.digikey.com/en/products/detail/murata-electronics/GRM1555C1H3R6CA01D/3693850
C4 | 1 | DNM_2.2uF | Capacitor_SMD:C_0603_1608Metric_Pad1.08x0.95mm_HandSolder | https://www.digikey.com/en/products/detail/samsung-electro-mechanics/CL10A225KP8NNNC/3886743
C7 | 1 | 2.2uF | Capacitor_SMD:C_0603_1608Metric_Pad1.08x0.95mm_HandSolder | https://www.digikey.com/en/products/detail/samsung-electro-mechanics/CL10A225KP8NNNC/3886743
C5 C6 C8 C9 C13 C16 | 6 | 0.1uF | Capacitor_SMD:C_0603_1608Metric_Pad1.08x0.95mm_HandSolder | https://www.digikey.com/en/products/detail/w%C3%BCrth-elektronik/885012206071/5453844
D1 D2 D3 D4 D5 | 5 | Blue | LED_SMD:LED_0603_1608Metric_Pad1.05x0.95mm_HandSolder | https://www.digikey.com/en/products/detail/osram-opto-semiconductors-inc/LB-Q39E-N1OO-35-1/2176321
D6 | 1 | Green | LED_SMD:LED_0603_1608Metric_Pad1.05x0.95mm_HandSolder | https://www.digikey.com/en/products/detail/lumex-opto-components-inc/SML-LXFM0603SUGCTR/7364547
J1 | 1 | Conn_ARM_JTAG_SWD_10 | zigbeeCape:Conn_ARM_JTAG_SWD_10 | http://infocenter.arm.com/help/topic/com.arm.doc.ddi0314h/DDI0314H_coresight_components_trm.pdf
L1 | 1 | 6.8uH | Inductor_SMD:L_0805_2012Metric_Pad1.15x1.40mm_HandSolder | https://www.digikey.com/en/products/detail/taiyo-yuden/CB2012T6R8M/2230244
L12 | 1 | 9.1nH | Inductor_SMD:L_0402_1005Metric_Pad0.77x0.64mm_HandSolder | https://www.digikey.com/en/products/detail/murata-electronics/LQG15HS9N1J02D/2594223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
L2 | 1 | 15nH | Inductor_SMD:L_0402_1005Metric_Pad0.77x0.64mm_HandSolder | https://www.digikey.com/en/products/detail/murata-electronics/LQG15HS15NJ02D/662874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
L3 L4 | 2 | 2.4nH | Inductor_SMD:L_0402_1005Metric_Pad0.77x0.64mm_HandSolder | https://www.digikey.com/en/products/detail/murata-electronics/LQG15HS2N4S02D/2594219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
L5 L6 | 2 | 3.9nH | Inductor_SMD:L_0402_1005Metric_Pad0.77x0.64mm_HandSolder | https://www.digikey.com/en/products/detail/murata-electronics/LQG15HS3N9S02D/662866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
L7 L10 | 2 | 2nH | Inductor_SMD:L_0402_1005Metric_Pad0.77x0.64mm_HandSolder | https://www.digikey.com/en/products/detail/murata-electronics/LQG15HS2N0S02D/1795312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
L8 | 1 | 22nH | Inductor_SMD:L_0402_1005Metric_Pad0.77x0.64mm_HandSolder | https://www.digikey.com/en/products/detail/murata-electronics/LQG15HS22NJ02D/662876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
L9 L11 | 2 | 10nH | Inductor_SMD:L_0402_1005Metric_Pad0.77x0.64mm_HandSolder | https://www.digikey.com/en/products/detail/murata-electronics/LQG15HS10NJ02D/662872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
R17 R19 | 2 | 4.7k | Resistor_SMD:R_0603_1608Metric_Pad0.98x0.95mm_HandSolder | https://www.digikey.com/en/products/detail/stackpole-electronics-inc/RMCF0603FT4K70/1760998
R2 R4 R5 R7 | 4 | 10K | Resistor_SMD:R_0603_1608Metric_Pad0.98x0.95mm_HandSolder | https://www.digikey.com/en/products/detail/yageo/RT0603FRE1310KL/13694209
R1 R3 | 2 | DNM_10k | Resistor_SMD:R_0603_1608Metric_Pad0.98x0.95mm_HandSolder | https://www.digikey.com/en/products/detail/yageo/RT0603FRE1310KL/13694209
R6 R8 R9 R10 R11 R12 | 6 | 1k | Resistor_SMD:R_0603_1608Metric_Pad0.98x0.95mm_HandSolder | https://www.digikey.com/en/products/detail/stackpole-electronics-inc/RMCF0603FT1K00/1761077
SW1 SW2 SW3 SW4 SW5 | 5 | SW_MEC_5E | zigbeeCape:SMD_PUSH_BUTTON | http://www.apem.com/int/index.php?controller=attachment&id_attachment=1371
U1 | 1 | CC1352R | zigbeeCape:CC1352R | https://www.digikey.com/en/products/detail/CC1352P1F3RGZT/296-53598-1-ND/10273328
U2 | 1 | 0.8Ghz_and_2.4GHz_Filter | zigbeeCape:DPX252690DT-5032B1 | https://www.digikey.com/en/products/detail/tdk-corporation/DPX252690DT-5032B1/5819342
U3 | 1 | SMA_Antenna | Connector_Coaxial:SMA_Amphenol_132134-16_Vertical | https://www.digikey.com/en/products/detail/amphenol-rf/132134/1011907
U4 | 1 | BeagleBone_P8 | Connector_PinHeader_2.54mm:PinHeader_2x23_P2.54mm_Vertical | https://www.digikey.com/en/products/detail/sullins-connector-solutions/PPTC102LFBN-RC/810216
U5 | 1 | BeagleBone_P9 | Connector_PinHeader_2.54mm:PinHeader_2x23_P2.54mm_Vertical | https://www.digikey.com/en/products/detail/sullins-connector-solutions/PPTC102LFBN-RC/810216
Y1 | 1 | 32.768kHz | zigbeeCape:FC-135_Crystal_Unit | https://www.digikey.com/en/products/detail/micro-crystal-ag/CC5V-T1A-32-768KHZ-7PF-20PPM-TA-QC/10499236
Y2 | 1 | 48MHz | zigbeeCape:SXT32418FD16-48MHZ_Crystal | https://www.digikey.com/en/products/detail/abracon-llc/ABM12W-48-0000MHZ-7-D1X-T3/7172767

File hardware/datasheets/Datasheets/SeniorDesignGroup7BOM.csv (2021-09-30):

Reference | Quantity | Value | Digikey Part Number
C1 C2 C3 | 7 | DNM_1uF | 1276-1184-1-ND
C10 C11 | 5 | 22uF | 490-7611-1-ND
C12 C14 C17 C26 | 9 | 12pF | 490-5924-1-ND
C15 | 3 | 1uF | 1276-1184-1-ND
C18 C19 | 5 | 1.1pF | 490-8189-1-ND
C20 | 3 | 1.2pF | 490-6209-1-ND
C21 | 3 | 1pF | 478-3659-1-ND
C22 C29 C31 | 7 | 100pF | 490-5922-1-ND
C23 C24 | 5 | 3pF | 490-5872-1-ND
C25 C27 | 5 | DNM | 490-5939-1-ND
C28 | 3 | 3.6pF | 490-5939-1-ND
C4 | 3 | DNM_2.2uF | 1276-1085-1-ND
C7 | 3 | 2.2uF | 1276-1085-1-ND
C5 C6 C8 C9 C13 C16 | 13 | 0.1uF | 311-1777-1-ND
D1 D2 D3 D4 D5 | 11 | Blue | 475-2815-1-ND
D6 | 3 | Green | 67-2320-1-ND
J1 | 3 | Conn_ARM_JTAG_SWD_10 | 1175-1621-ND
L1 | 3 | 6.8uH | 445-17082-1-ND
L12 | 3 | 9.1nH | 490-8390-1-ND
L2 | 3 | 15nH | 490-2625-1-ND
L3 L4 | 5 | 2.4nH | 490-8389-1-ND
L5 L6 | 5 | 3.9nH | 490-2617-1-ND
L7 L10 | 5 | 2nH | 490-6569-1-ND
L8 | 3 | 22nH | 490-2627-1-ND
L9 L11 | 5 | 10nH | 490-2623-1-ND
R17 R19 | 5 | 4.7k | RMCF0603FT4K70CT-ND
R2 R4 R5 R7 | 9 | 10K | 13-RT0603FRE1310KLCT-ND
R1 R3 | 5 | DNM_10k | 13-RT0603FRE1310KLCT-ND
R6 R8 R9 R10 R11 R12 | 13 | 1k | RMCF0603FT1K00CT-ND
SW1 SW2 SW3 SW4 SW5 | 11 | SW_MEC_5E | 679-2381-1-ND
U1 | 5 | CC1352R | 296-53598-1-ND
U2 | 3 | 0.8Ghz_and_2.4GHz_Filter | 445-174204-1-ND
U3 | 3 | SMA_Antenna | ACX1230-ND
U4 | 3 | BeagleBone_P8 | 1528-1365-ND
U5 | 1 | BeagleBone_P9
Y1 | 3 | 32.768kHz | 2195-CC5V-T1A-32.768KHZ-7PF-20PPM-TA-QCCT-ND
Y2 | 3 | 48MHz | 535-13996-1-ND

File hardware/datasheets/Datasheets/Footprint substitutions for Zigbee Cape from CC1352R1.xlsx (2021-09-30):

Original | Cc1352 | Cape | Substitution
402 | C351 | C7 | 603
402 | C481 | C8 | 603
402 | C451 | C9 | 603
402 | C81 | C12 | 603
402 | C91 | C14 | 603
 | C231 | C15
 | C11 | C17
 | C21 | C18
 | C12 | C19
 | C111

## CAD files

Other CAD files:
firmware/cape/CapeFirmware_P/src/sysbios/m3_Hwi_asm_switch.obj
firmware/daughterboard/SensorTagProject/src/sysbios/m3_TaskSupport_asm.obj
firmware/daughterboard/tests/zed_temperaturesensor_CC1352R1_LAUNCHXL_tirtos_ccs/default/Application/StartUp/main.obj
firmware/cape/CapeFirmware_P/src/sysbios/m3_IntrinsicsSupport_asm.obj
firmware/cape/CapeFirmware_P/src/sysbios/m3_Hwi_asm.obj
firmware/daughterboard/SensorTagProject/src/sysbios/m3_Hwi_asm_switch.obj
firmware/daughterboard/SensorTagProject/src/sysbios/m3_Hwi_asm.obj
firmware/cape/CapeFirmware_P/src/sysbios/m3_TaskSupport_asm.obj
firmware/daughterboard/SensorTagProject/src/sysbios/m3_IntrinsicsSupport_asm.obj
firmware/cape/tests/uartecho_CC1352R1_LAUNCHXL_tirtos_ccs/Debug/syscfg/ti_drivers_config.obj
firmware/daughterboard/tests/zed_temperaturesensor_CC1352R1_LAUNCHXL_tirtos_ccs/default/Application/Services/nvocmp.obj
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

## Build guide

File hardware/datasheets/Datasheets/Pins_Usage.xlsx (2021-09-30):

Component | Usage | Name | Pin | Notes
BeagleBone P9 | BeagleBone_Reset | SYS_RESETn | 10 | All pins are currently tentative
 | UART_TX | UART1_TXD | 24
 | UART_RX | UART1_RXD | 26
 | Lan_Heartbeat | GPIO_20 | 41 | LED
 | Network_Connect | GPIO_48 | 15 | Button
 | SPI_CLK | SPI0_SCLK | 22
 | SPI_MISO | SPI0_D0 | 21
 | SPI_MOSI | SPI0_D1 | 18
 | SPI_CS | SPI0_CS0 | 17
 | I2C2_SDA | I2C2_SDA | 20
 | I2C2_SCL | I2C2_SCL | 19
BeagleBone P8
CC1352 A | JTAG_.. | JTAG_.. | 35 | Programming
 | JTAG_.. | JTAG_.. | 25 | Programming
 | JTAG_.. | JTAG_.. | 24 | Programming
 | JTAG_.. | JTAG_.. | 26 | Programming
 | JTAG_.. | JTAG_.. | 27 | Programming
 | 2.4GHz P | 2_4_GHZ_RF_P | 1
 | 2.4GHz N | 2_4_GHZ_RF_N | 2
 | Sub-1GHz P | SUB-1_GHZ_RF_P | 3
 | Sub-1GHz N | SUB-1_GHZ_RF_N | 4
 | RX_TX | RX_TX | 5
 | DCDC_SW | DCDC_SW | 33
CC1352 B | UART_RX | DIO_3 | 8
 | UART_TX | DIO_4 | 9
 | SPI_MISO | DIO_5_HP | 10
 | SPIO_MOSI | DIO_6_HP | 11
 | SPI_CS | DIO_7_HP | 12
 | SPI_CLK | DIO_8 | 14
 | I2C2_SCL | DIO_14 | 20
 | I2C2_SDA | DIO_15 | 21
 | Zigbee_Connect | DIO_18 | 28 | Button
 | Check_Error | DIO_19 | 29 | Button
 | Zigbee_HeartBeat | DIO_20 | 30 | LED
 | Cape_HeartBeat | DIO_21 | 31 | LED
 | Aux_2 | DIO_22 | 32 | LED
 | Aux_1 | DIO_23_ANA | 36 | LED

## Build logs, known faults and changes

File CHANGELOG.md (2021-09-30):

- 03/15/2021 -- griffens:
	- Adding directories 'firmware/beaglebone', 'firmware/cape', and 'firmware/daughterboard' to segment code for each component
	- Updating README

- 02/22/2021 -- griffens:
	- Adding basic .gitignore for KiCAD projects and Beaglebone firmware projects
	- Adding directories for hardware, firmware, and software projects so different project structures/resources don't interfere with each other

- 02/09/2021 -- griffens:
	- Added Trello board link to README

- 02/05/2021 -- griffens:
	- Added scope and requirements sections to README
	- Added docs directory for documentation resources and other non-essential project items

- 02/04/2021 -- griffens:
	- Added README and CHANGELOG

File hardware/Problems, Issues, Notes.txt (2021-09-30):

CC1352R1 DataSheet- FL3 is not available, need to find replacement

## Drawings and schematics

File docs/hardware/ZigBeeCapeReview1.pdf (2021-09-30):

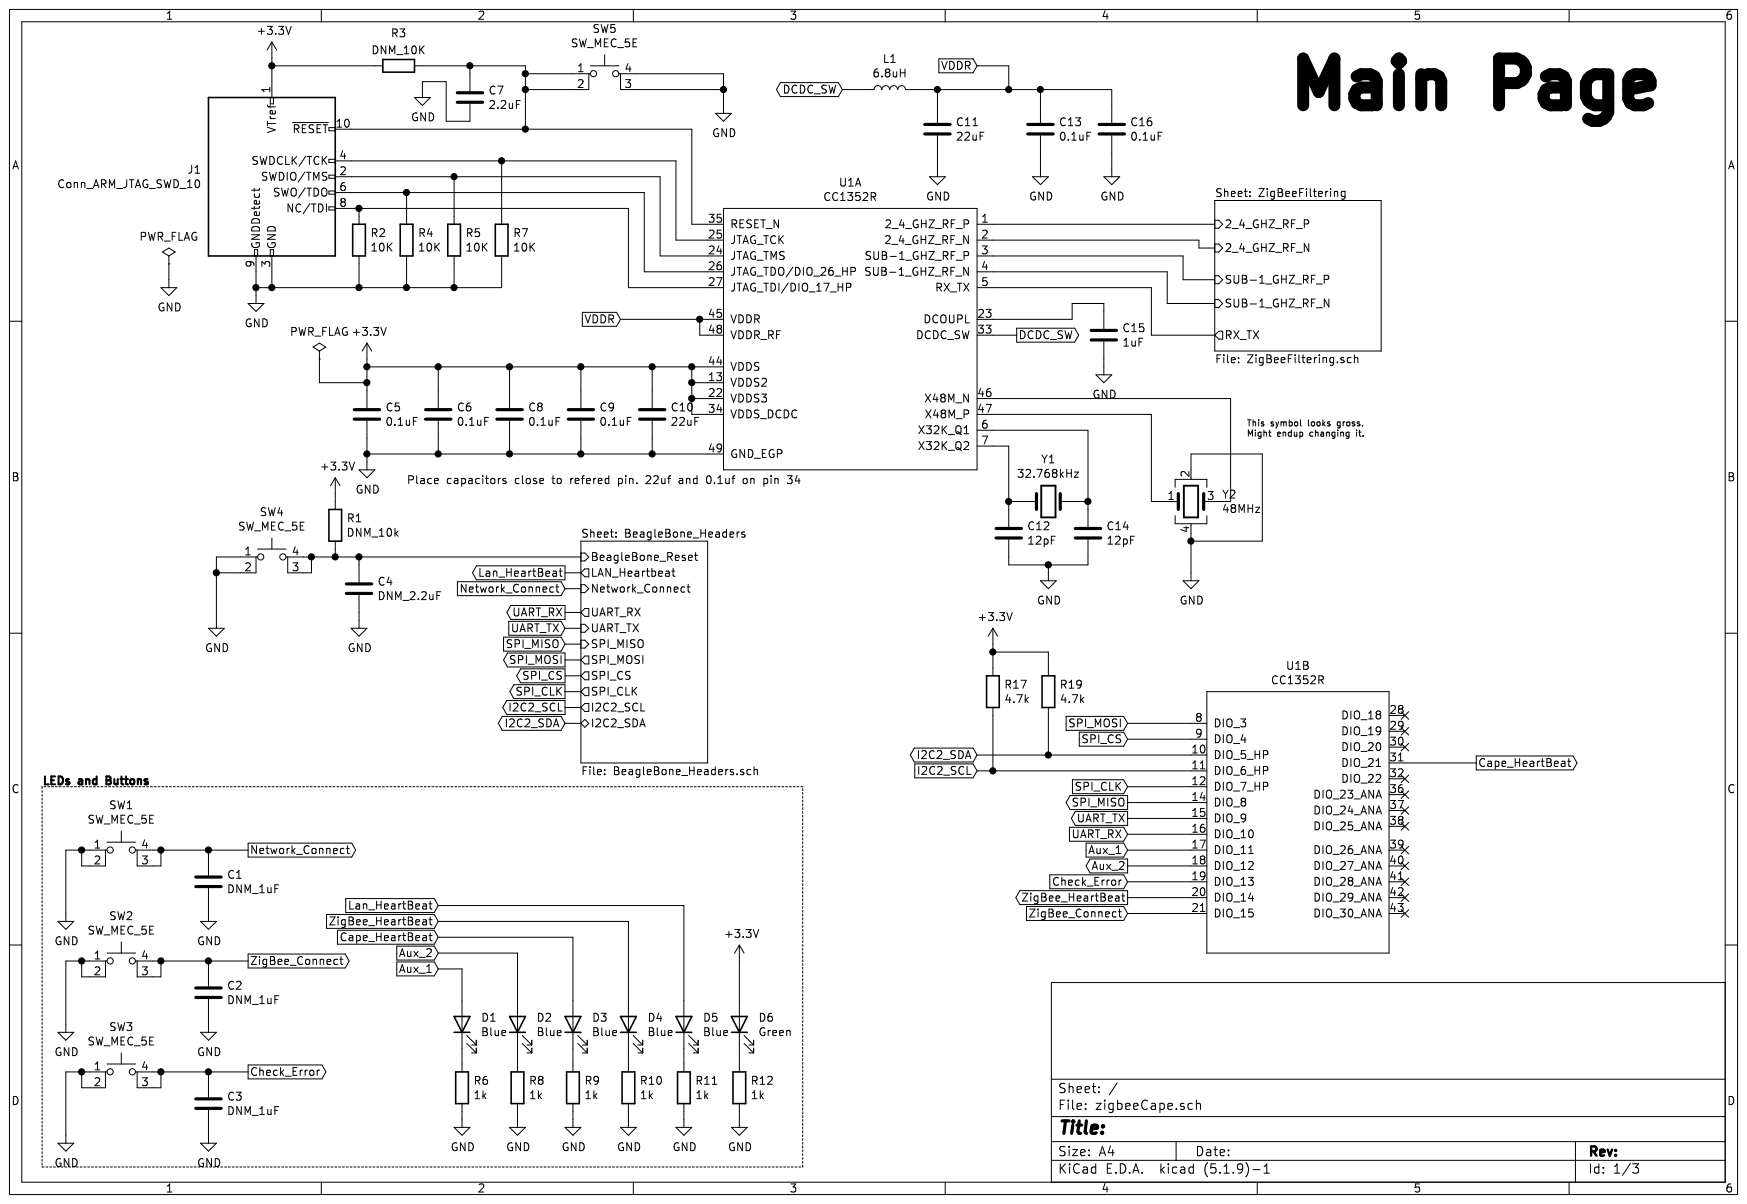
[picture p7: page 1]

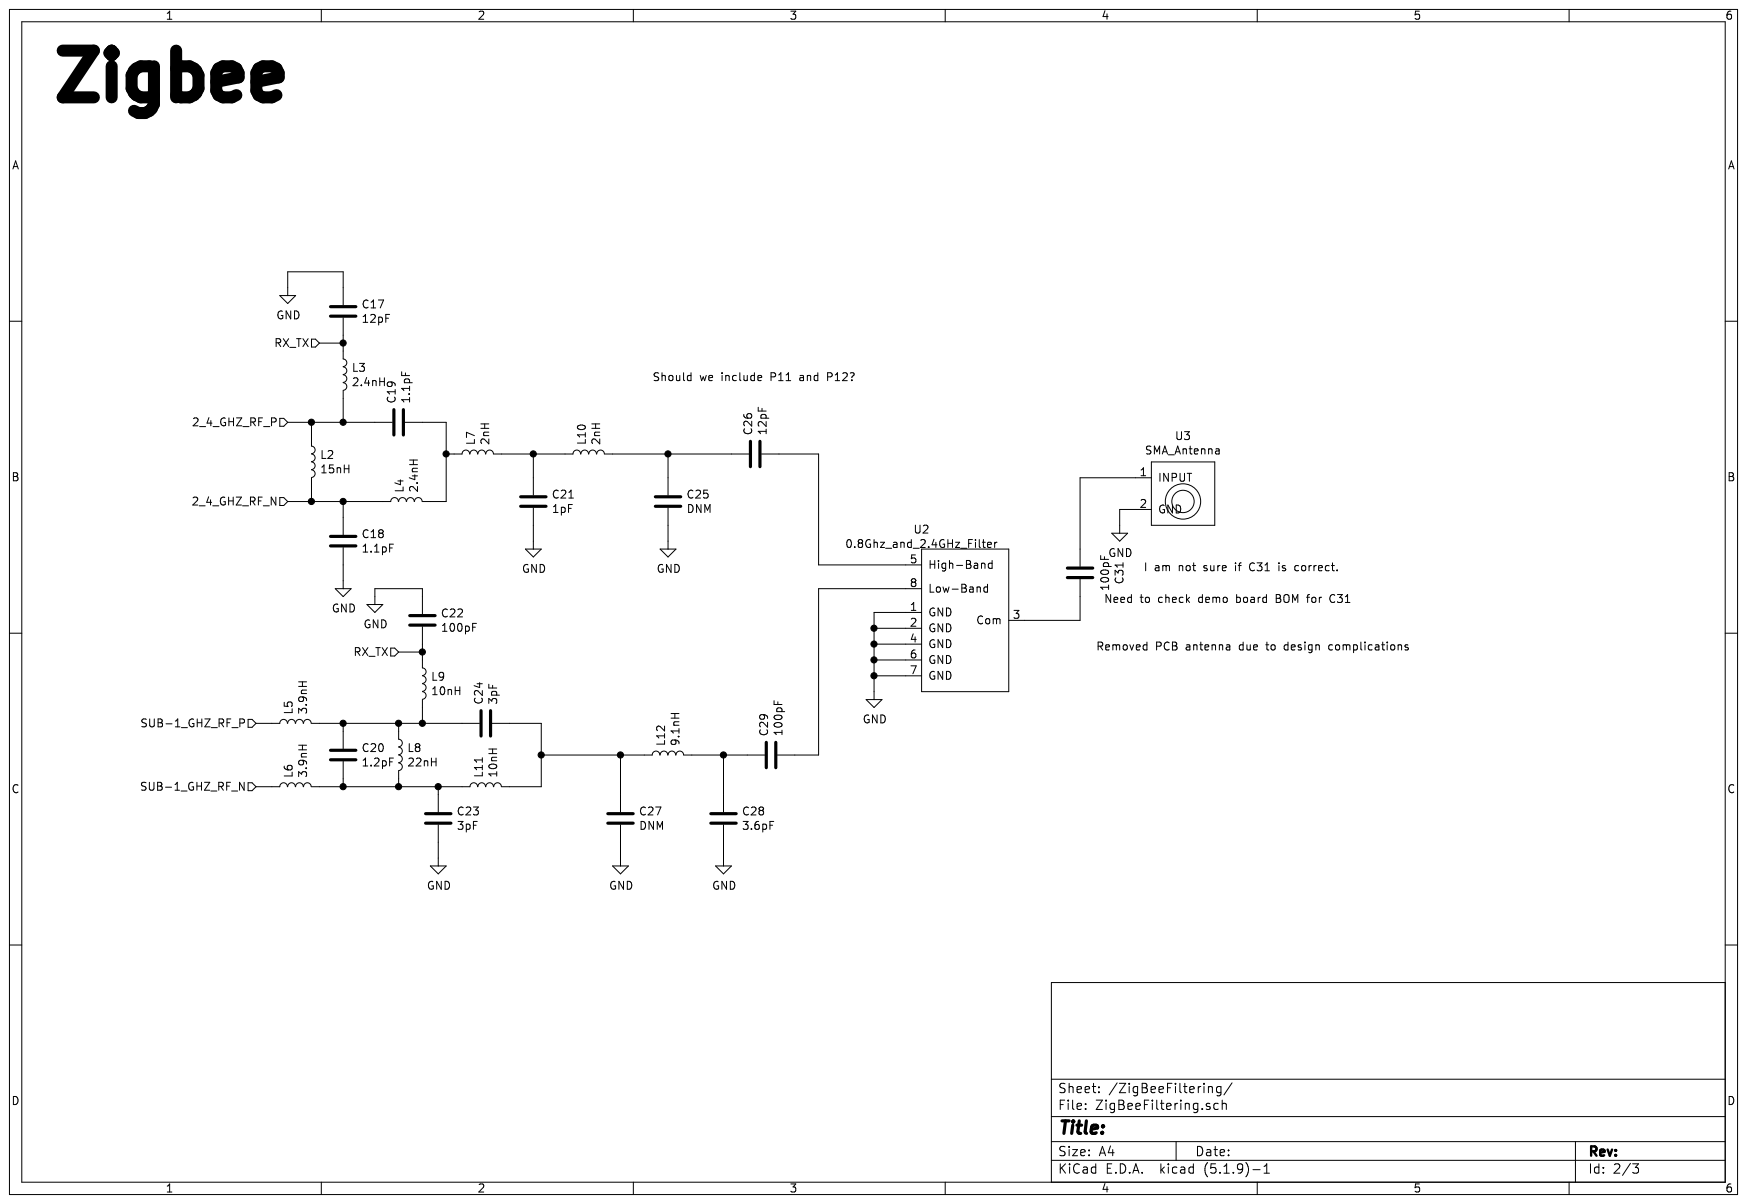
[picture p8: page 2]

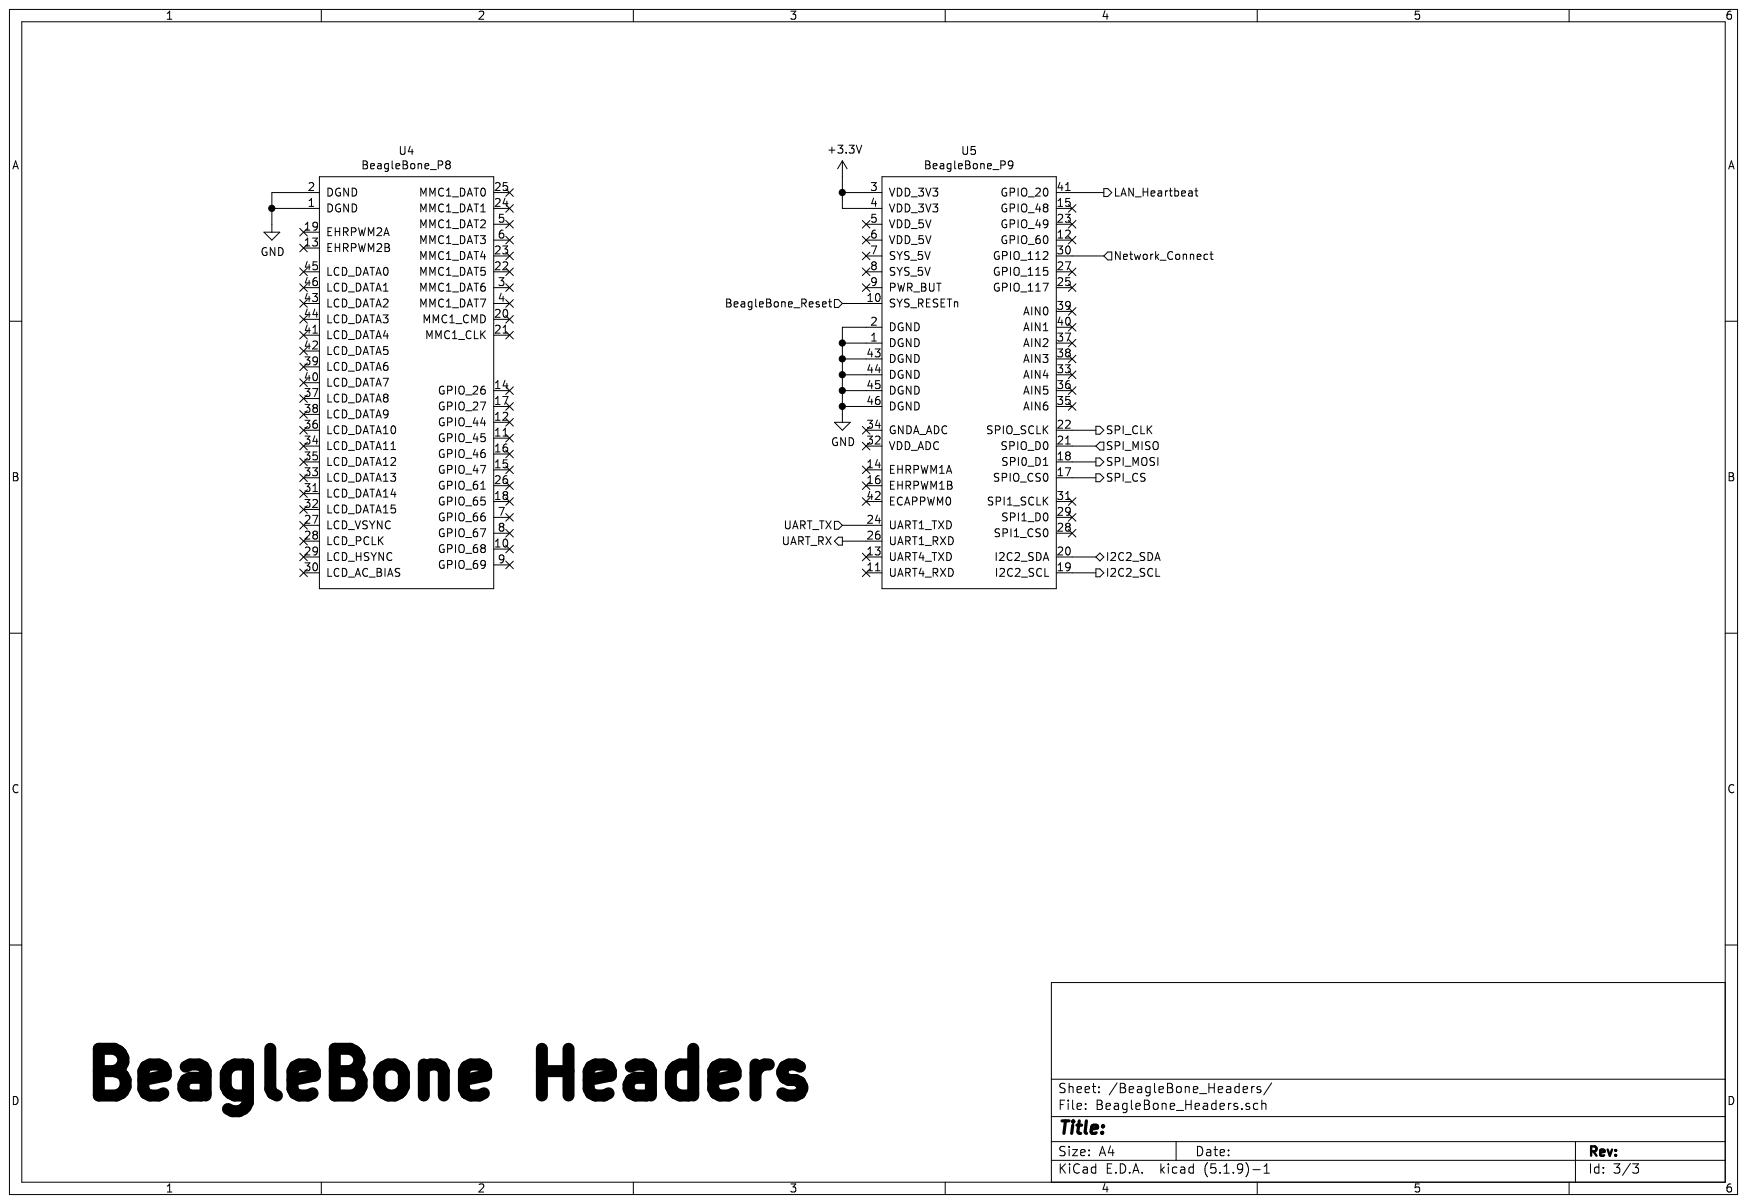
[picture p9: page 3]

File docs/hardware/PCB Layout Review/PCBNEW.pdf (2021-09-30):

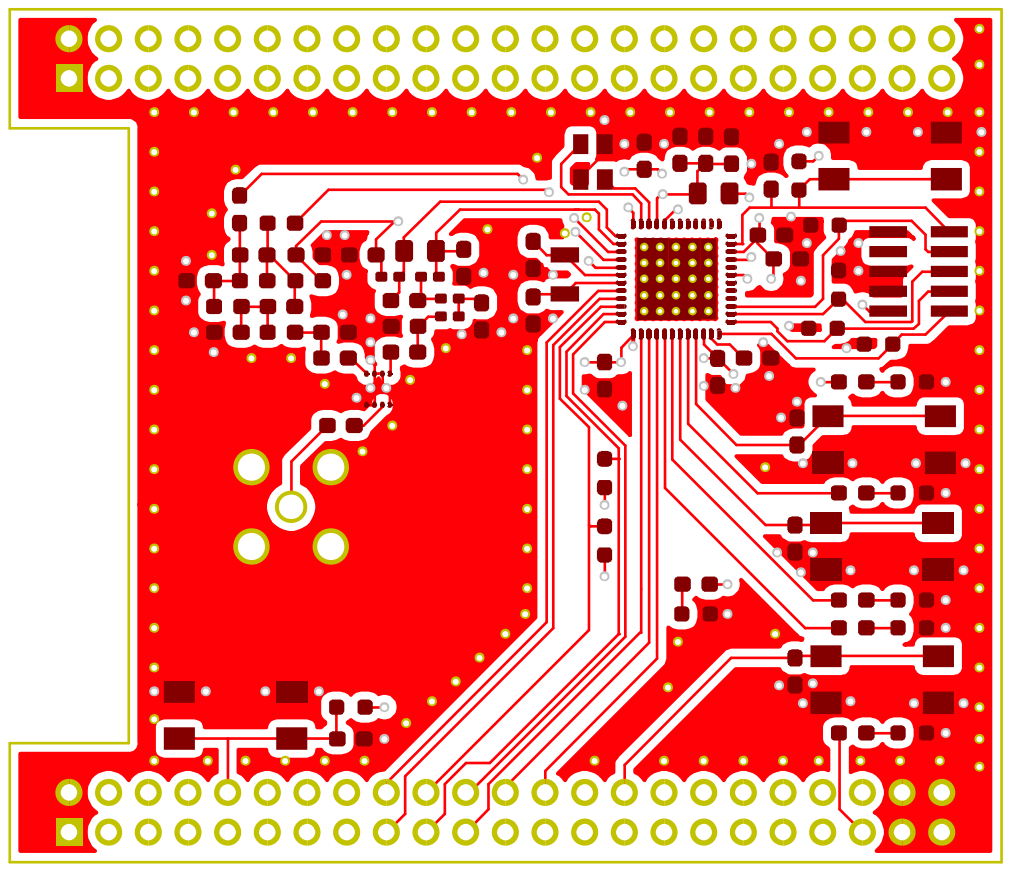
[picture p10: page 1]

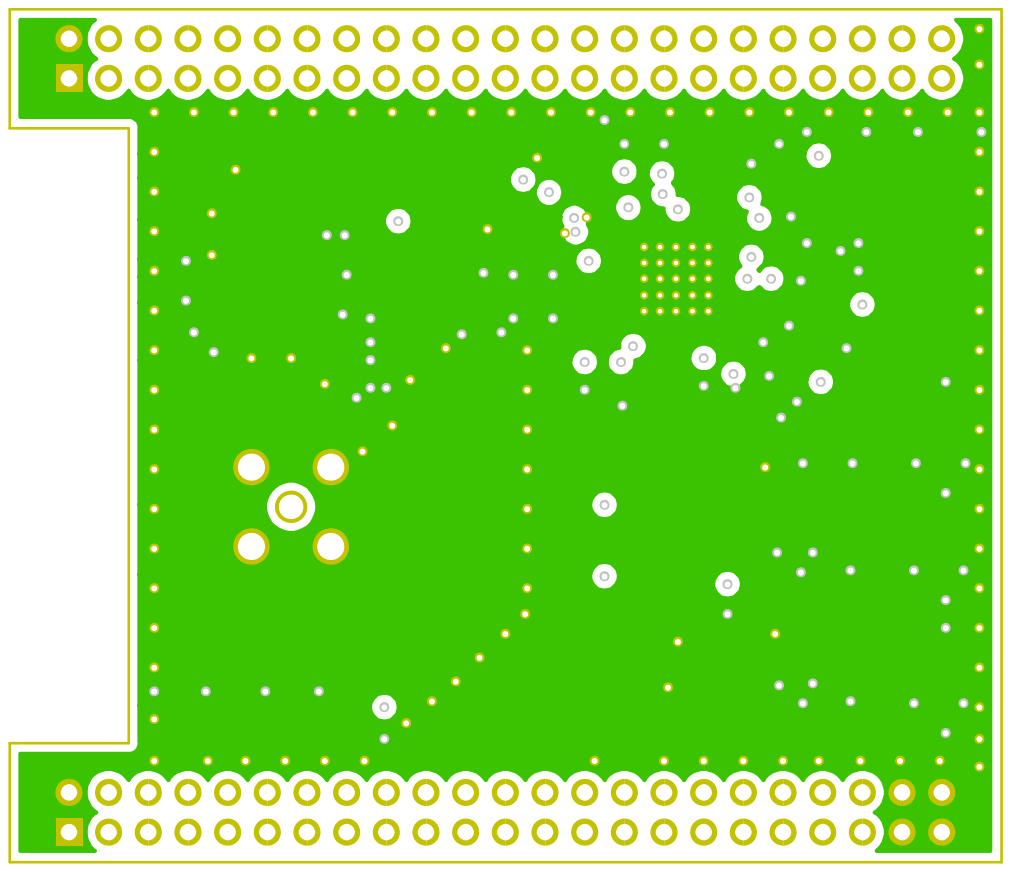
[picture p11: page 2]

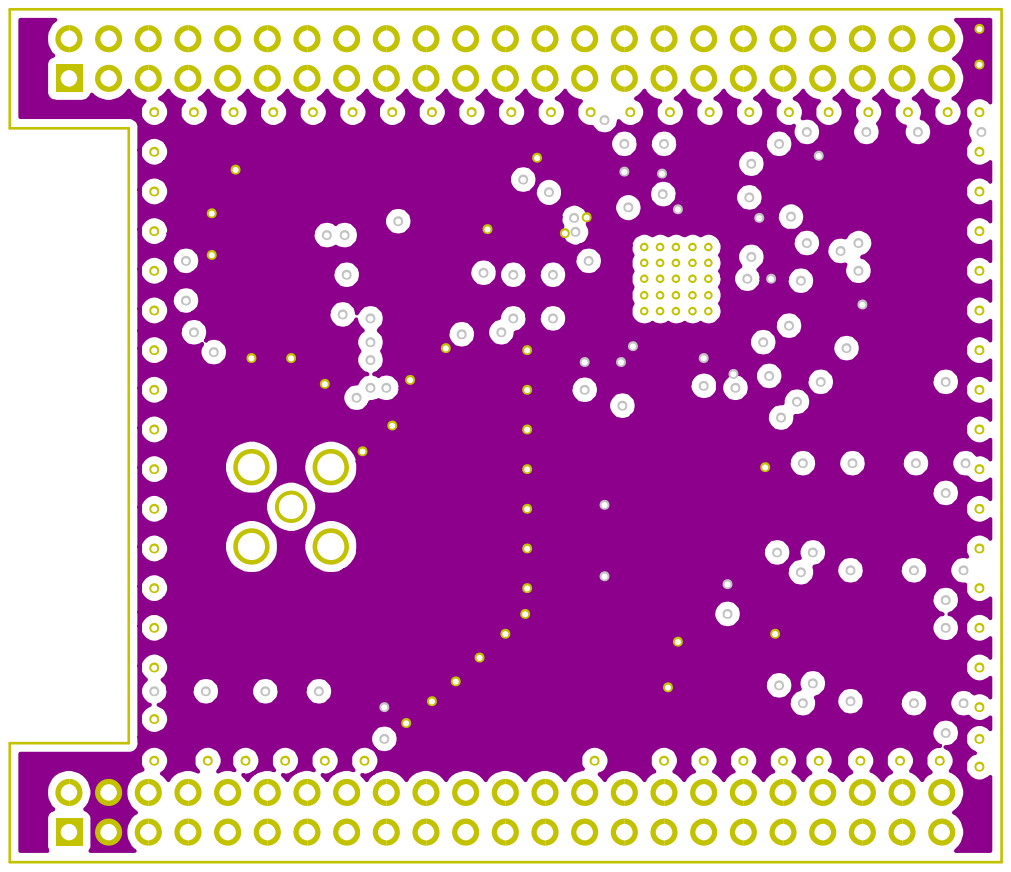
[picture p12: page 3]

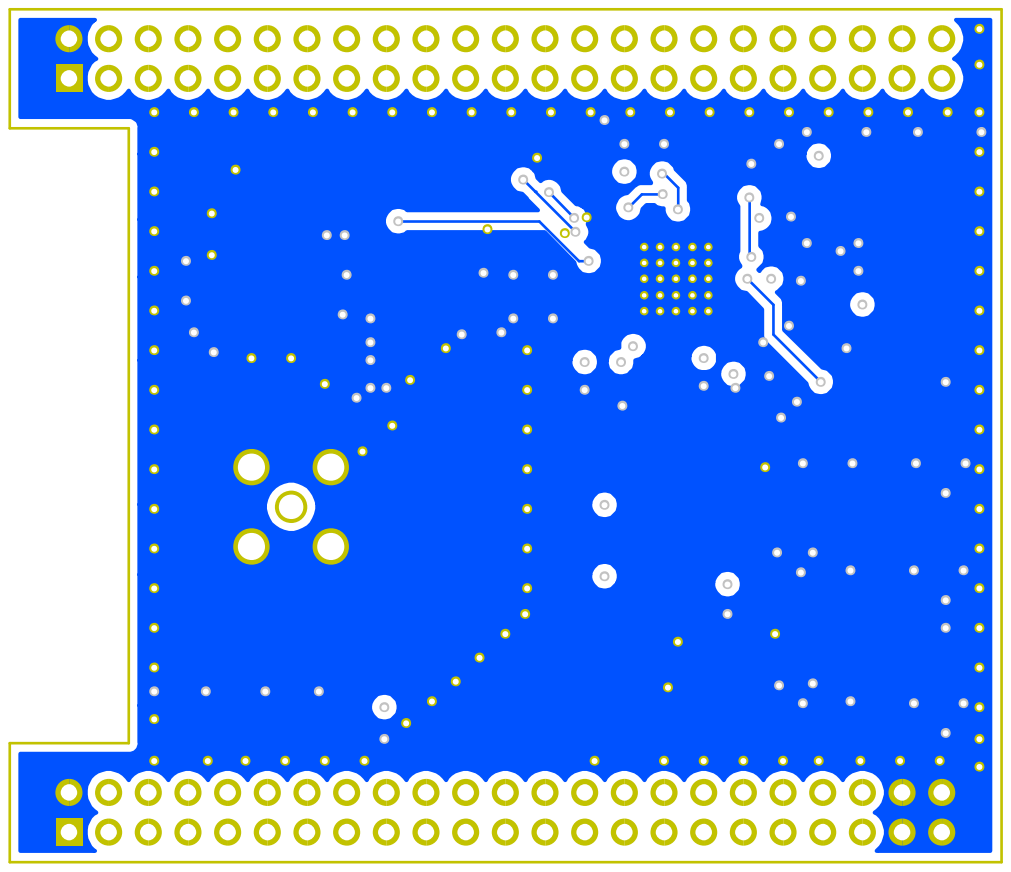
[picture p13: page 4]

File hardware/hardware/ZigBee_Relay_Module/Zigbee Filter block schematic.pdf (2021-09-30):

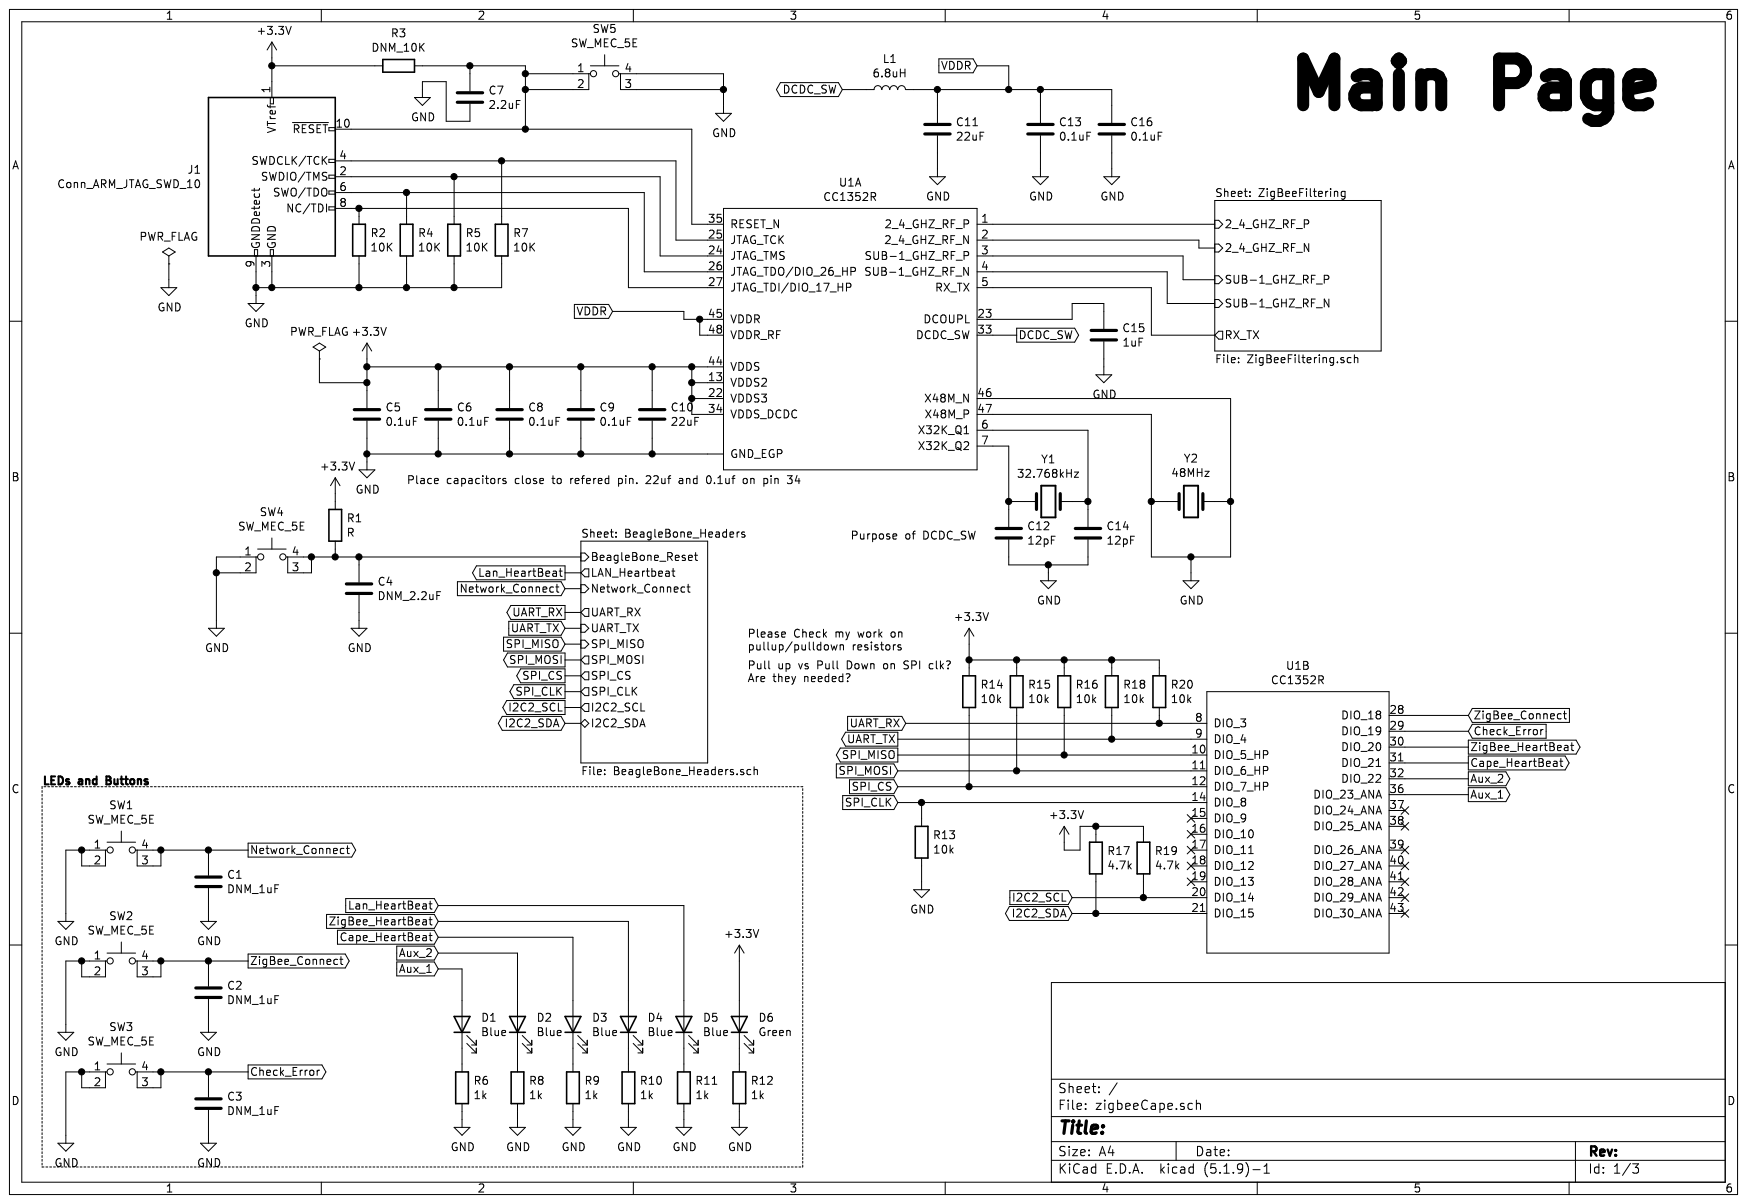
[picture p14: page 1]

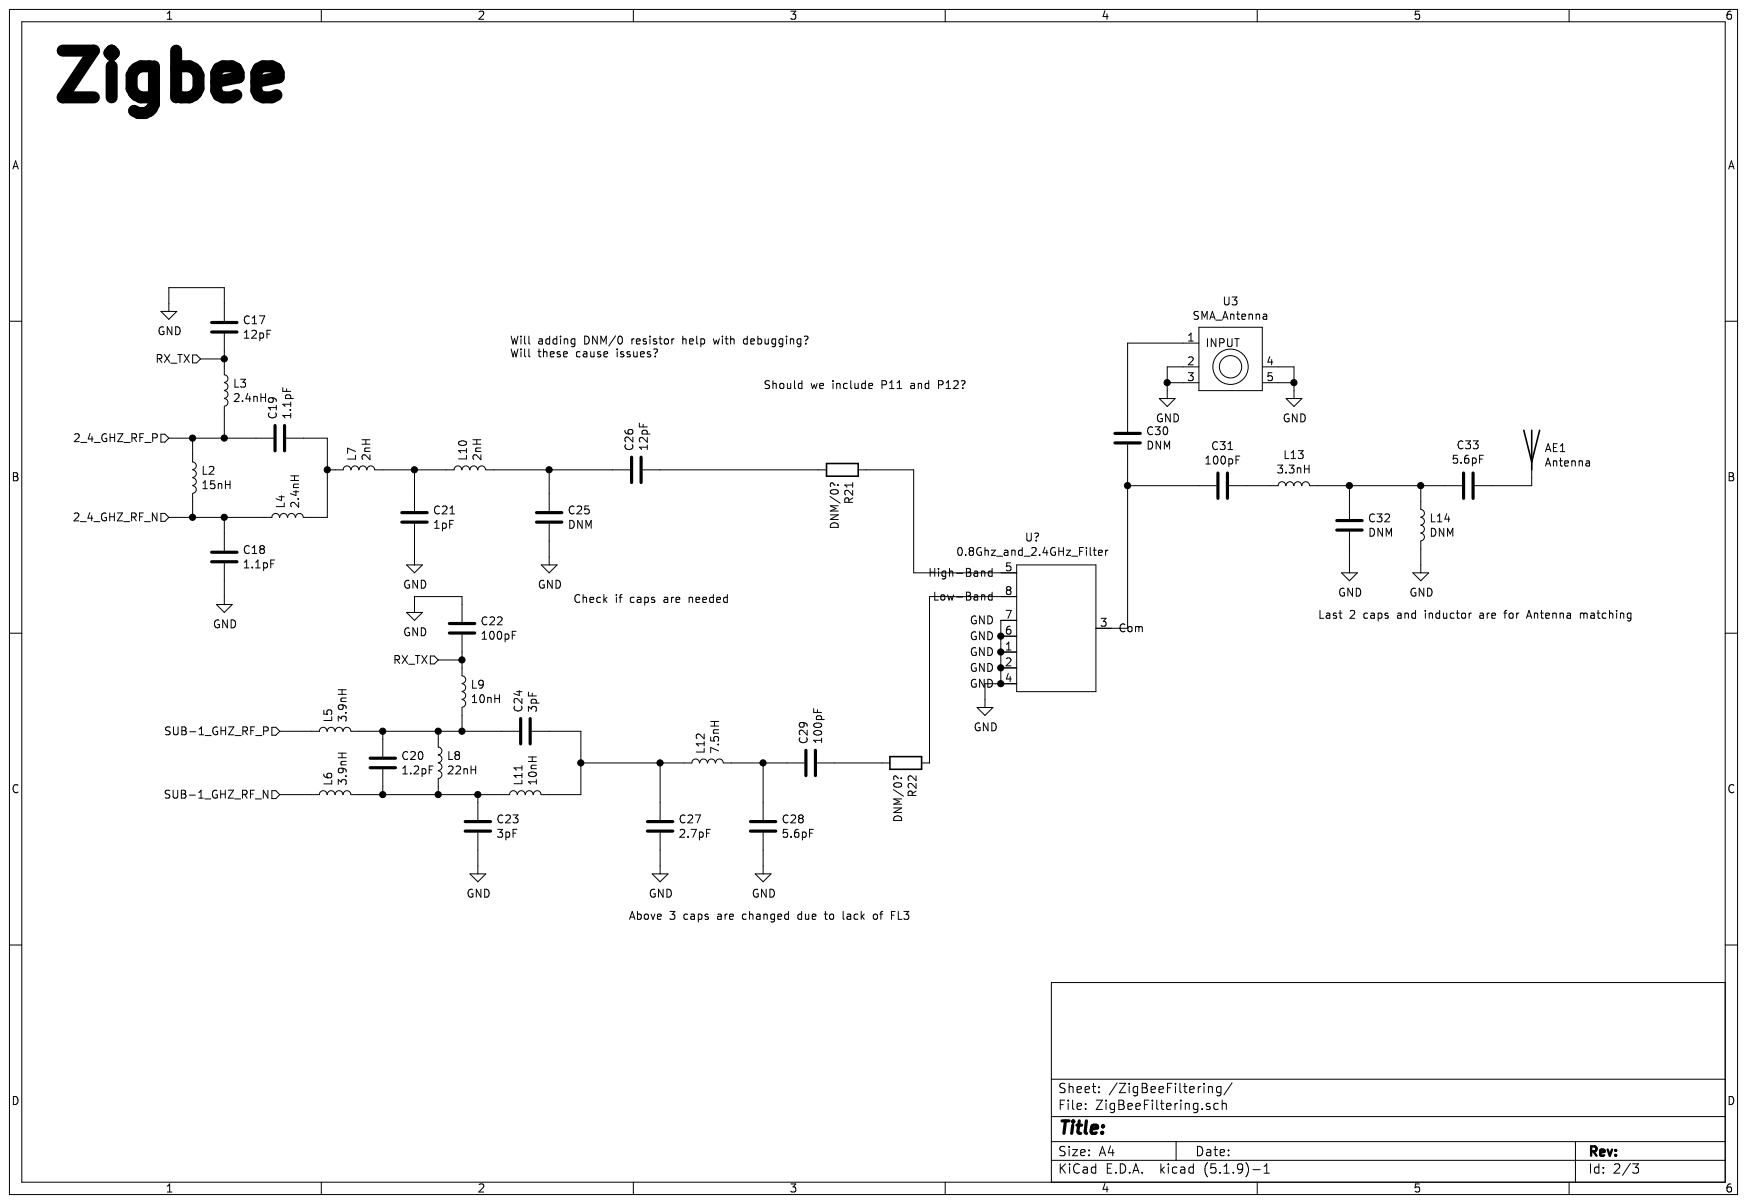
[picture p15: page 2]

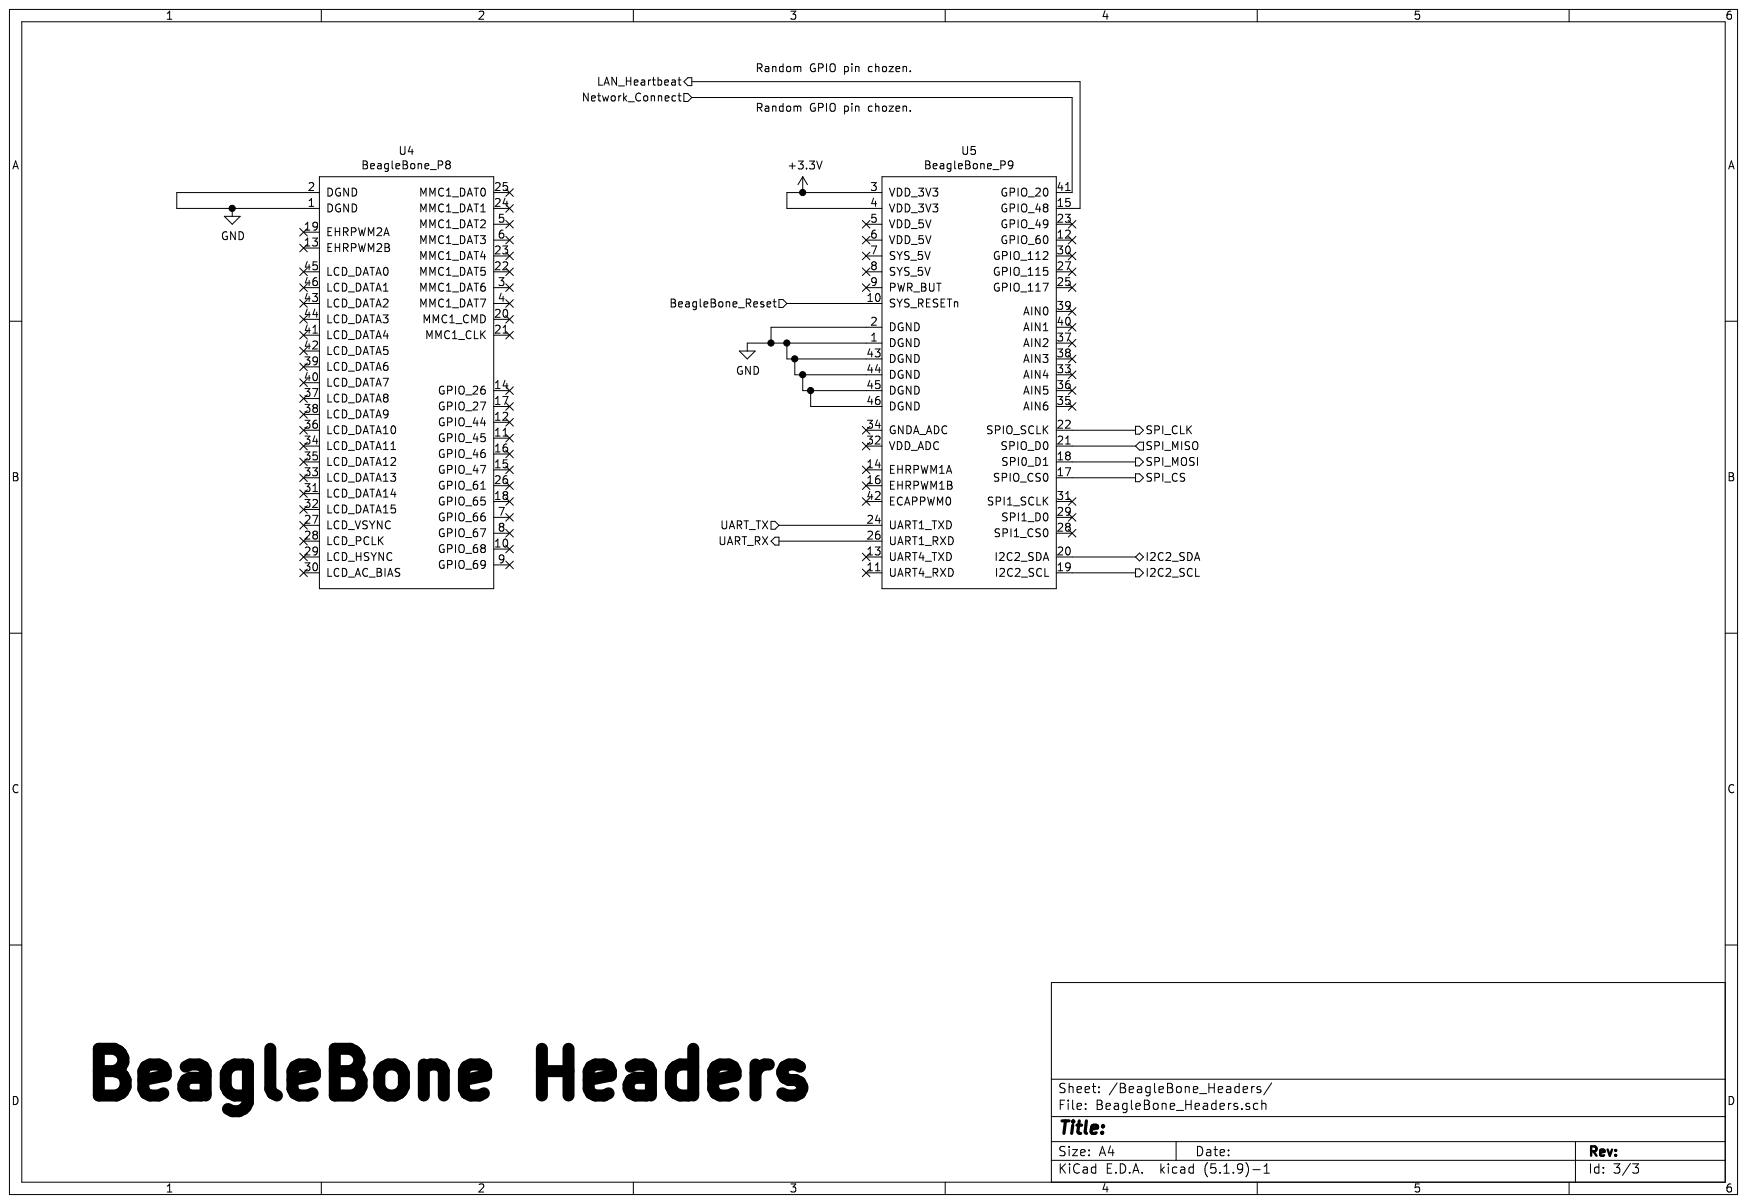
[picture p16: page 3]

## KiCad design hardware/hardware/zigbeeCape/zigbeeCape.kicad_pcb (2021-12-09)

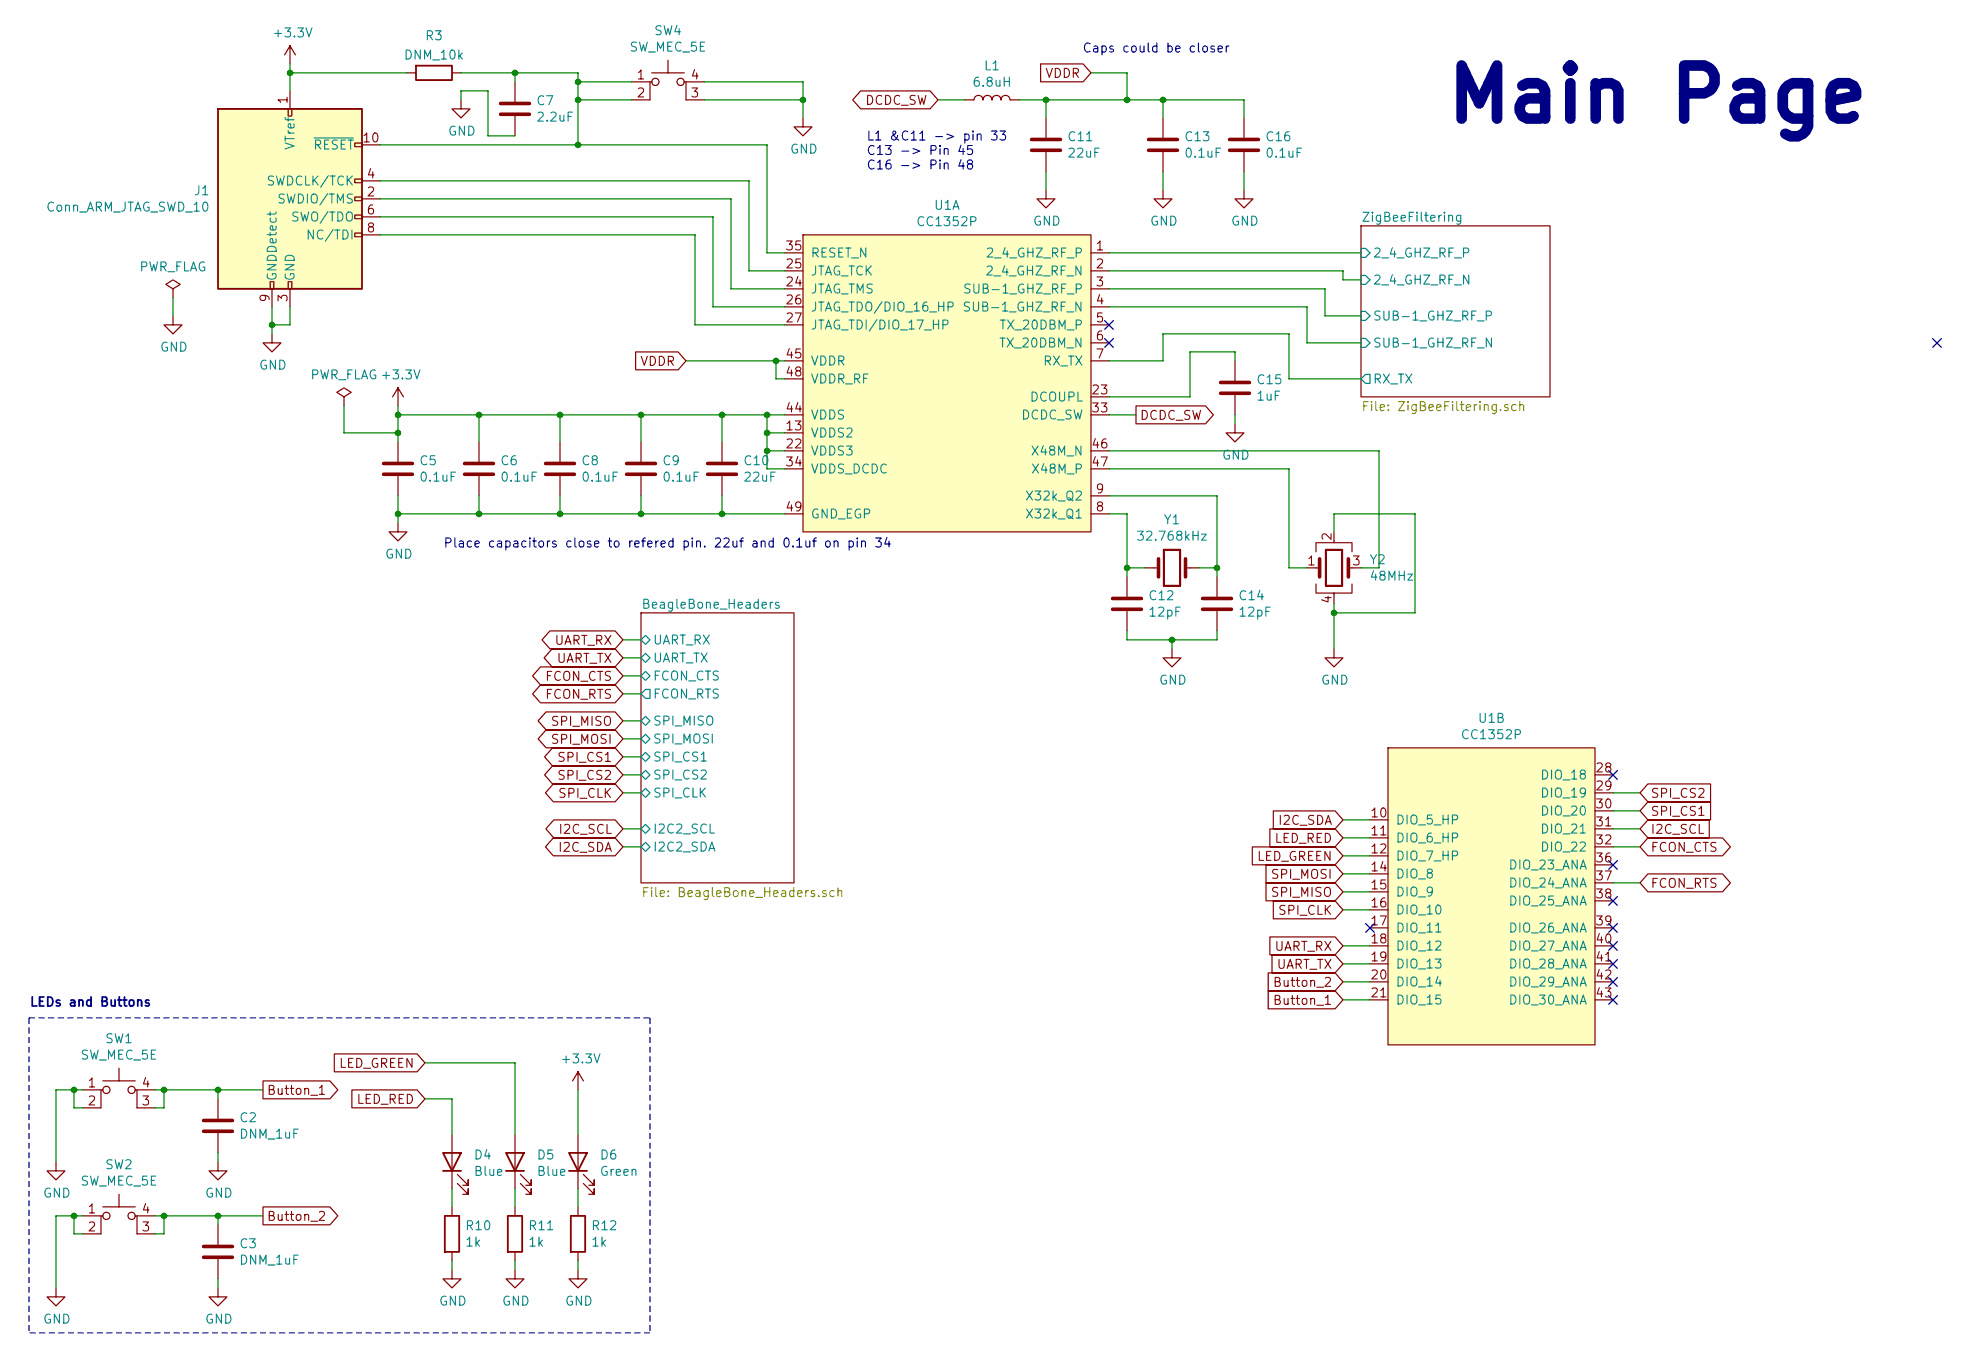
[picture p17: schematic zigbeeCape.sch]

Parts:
C2, C3: DNM_1uF; C_0603_1608Metric_Pad1.08x0.95mm_HandSolder; Digikey Part Number 1276-1184-1-ND
C5, C6, C8, C9, C13, C16: 0.1uF; C_0603_1608Metric_Pad1.08x0.95mm_HandSolder; Digikey Part Number 311-1777-1-ND
C7: 2.2uF; C_0603_1608Metric_Pad1.08x0.95mm_HandSolder; Digikey Part Number 1276-1085-1-ND
C10, C11: 22uF; C_0603_1608Metric_Pad1.08x0.95mm_HandSolder; Digikey Part Number 490-7611-1-ND
C12, C14: 12pF; C_0402_1005Metric_Pad0.74x0.62mm_HandSolder; Digikey Part Number 490-5924-1-ND
C15: 1uF; C_0603_1608Metric_Pad1.08x0.95mm_HandSolder; Digikey Part Number 1276-1184-1-ND
D4, D5: Blue; LED_0603_1608Metric_Pad1.05x0.95mm_HandSolder; Digikey Part Number 475-2815-1-ND
D6: Green; LED_0603_1608Metric_Pad1.05x0.95mm_HandSolder; Digikey Part Number 67-2320-1-ND
J1: Conn_ARM_JTAG_SWD_10; Digikey Part Number 1175-1621-ND
L1: 6.8uH; L_0805_2012Metric_Pad1.15x1.40mm_HandSolder; Digikey Part Number 445-17082-1-ND
R3: DNM_10k; R_0603_1608Metric_Pad0.98x0.95mm_HandSolder; Digikey Part Number 13-RT0603FRE1310KLCT-ND
R10, R11, R12: 1k; R_0603_1608Metric_Pad0.98x0.95mm_HandSolder; Digikey Part Number RMCF0603FT1K00CT-ND
SW1, SW2, SW4: SW_MEC_5E; SMD_PUSH_BUTTON; Digikey Part Number 679-2381-1-ND
U1: CC1352P; CC1352R
Y1: 32.768kHz; FC-135_Crystal_Unit; Digikey Part Number 2195-CC5V-T1A-32.768KHZ-7PF-20PPM-TA-QC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
Y2: 48MHz; SXT32418FD16-48MHZ_Crystal; Digikey Part Number 535-13996-1-ND

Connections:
+3V3: C5.1, C6.1, C8.1, C9.1, C10.1, D6.2 (A), J1.1 (VTref), R3.2, U1.13 (VDDS2), U1.22 (VDDS3), U1.34 (VDDS_DCDC), U1.44 (VDDS); also elsewhere on the board
/ZigBeeFiltering/2_4_GHZ_RF_N: U1.2 (2_4_GHZ_RF_N); also elsewhere on the board
/ZigBeeFiltering/2_4_GHZ_RF_P: U1.1 (2_4_GHZ_RF_P); also elsewhere on the board
/ZigBeeFiltering/RX_TX: U1.7 (RX_TX); also elsewhere on the board
/ZigBeeFiltering/SUB-1_GHZ_RF_N: U1.4 (SUB-1_GHZ_RF_N); also elsewhere on the board
/ZigBeeFiltering/SUB-1_GHZ_RF_P: U1.3 (SUB-1_GHZ_RF_P); also elsewhere on the board
Button_1: C2.1, SW1.3 (K), SW1.4 (A), U1.21 (DIO_15)
Button_2: C3.1, SW2.3 (K), SW2.4 (A), U1.20 (DIO_14)
DCDC_SW: L1.1, U1.33 (DCDC_SW)
FCON_CTS: U1.32 (DIO_22); also elsewhere on the board
FCON_RTS: U1.37 (DIO_24_ANA); also elsewhere on the board
GND: C2.2, C3.2, C5.2, C6.2, C7.2, C8.2, C9.2, C10.2, C11.2, C12.2, C13.2, C14.2, C15.2, C16.2, J1.3 (GND), J1.5 (GND), J1.9 (GNDDetect), R10.2, R11.2, R12.2, SW1.1, SW1.2, SW2.1, SW2.2, SW4.3 (K), SW4.4 (A), U1.49 (GND_EGP), Y2.2, Y2.4; also elsewhere on the board
I2C_SCL: U1.31 (DIO_21); also elsewhere on the board
I2C_SDA: U1.10 (DIO_5_HP); also elsewhere on the board
LED_GREEN: D5.2 (A), U1.12 (DIO_7_HP)
LED_RED: D4.2 (A), U1.11 (DIO_6_HP)
unnamed: C7.1, J1.10 (~RESET~), R3.1, SW4.1, SW4.2, U1.35 (RESET_N)
unnamed: C12.1, U1.8 (X32k_Q1), Y1.1
unnamed: C14.1, U1.9 (X32k_Q2), Y1.2
unnamed: C15.1, U1.23 (DCOUPL)
unnamed: D4.1 (K), R10.1
unnamed: D5.1 (K), R11.1
unnamed: D6.1 (K), R12.1
unnamed: J1.2 (SWDIO/TMS), U1.24 (JTAG_TMS)
unnamed: J1.4 (SWDCLK/TCK), U1.25 (JTAG_TCK)
unnamed: J1.6 (SWO/TDO), U1.26 (JTAG_TDO/DIO_16_HP)
unnamed: J1.8 (NC/TDI), U1.27 (JTAG_TDI/DIO_17_HP)
unnamed: U1.46 (X48M_N), Y2.3
unnamed: U1.47 (X48M_P), Y2.1
SPI_CLK: U1.16 (DIO_10); also elsewhere on the board
SPI_CS1: U1.30 (DIO_20); also elsewhere on the board
SPI_CS2: U1.29 (DIO_19); also elsewhere on the board
SPI_MISO: U1.15 (DIO_9); also elsewhere on the board
SPI_MOSI: U1.14 (DIO_8); also elsewhere on the board
UART_RX: U1.18 (DIO_12); also elsewhere on the board
UART_TX: U1.19 (DIO_13); also elsewhere on the board
VDDR: C11.1, C13.1, C16.1, L1.2, U1.45 (VDDR), U1.48 (VDDR_RF)

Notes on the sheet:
LEDs and Buttons
Place capacitors close to refered pin. 22uf and 0.1uf on pin 34
Main Page
Caps could be closer
L1 &C11 -> pin 33 C13 -> Pin 45 C16 -> Pin 48

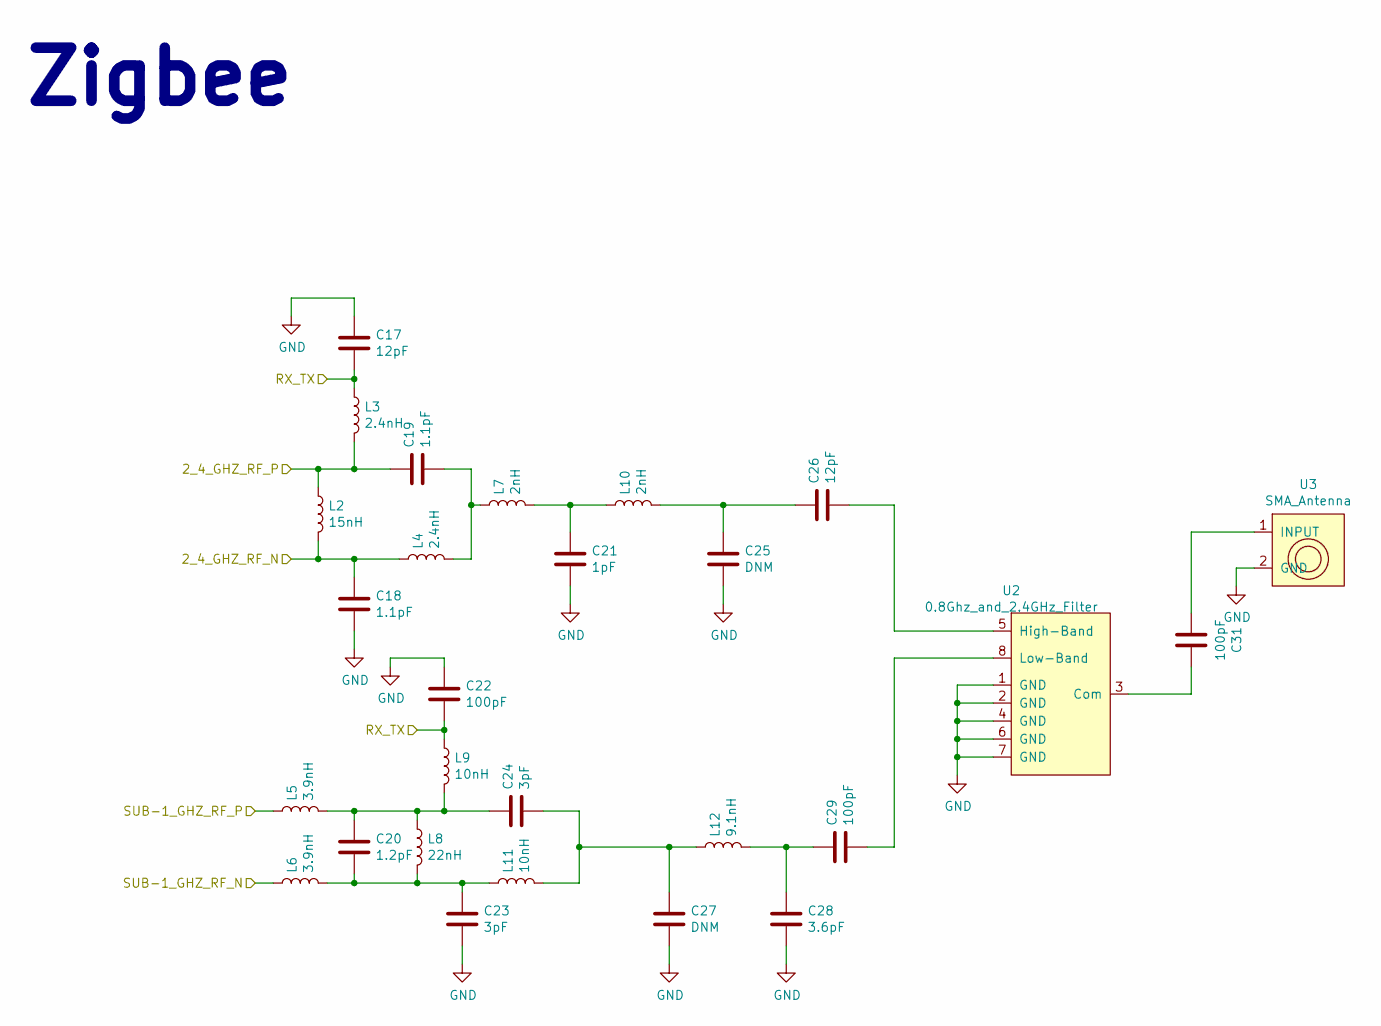
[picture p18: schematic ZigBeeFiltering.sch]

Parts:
C17, C26: 12pF; C_0402_1005Metric_Pad0.74x0.62mm_HandSolder; Digikey Part Number 490-5924-1-ND
C18, C19: 1.1pF; C_0402_1005Metric_Pad0.74x0.62mm_HandSolder; Digikey Part Number 490-8189-1-ND
C20: 1.2pF; C_0402_1005Metric_Pad0.74x0.62mm_HandSolder; Digikey Part Number 490-6209-1-ND
C21: 1pF; C_0402_1005Metric_Pad0.74x0.62mm_HandSolder; Digikey Part Number 478-3659-1-ND
C22, C29, C31: 100pF; C_0402_1005Metric_Pad0.74x0.62mm_HandSolder; Digikey Part Number 490-5922-1-ND
C23, C24: 3pF; C_0402_1005Metric_Pad0.74x0.62mm_HandSolder; Digikey Part Number 490-5872-1-ND
C25, C27: DNM; C_0402_1005Metric_Pad0.74x0.62mm_HandSolder; Digikey Part Number 490-5939-1-ND
C28: 3.6pF; C_0402_1005Metric_Pad0.74x0.62mm_HandSolder; Digikey Part Number 490-5939-1-ND
L2: 15nH; L_0402_1005Metric_Pad0.77x0.64mm_HandSolder; Digikey Part Number 490-2625-1-ND
L3, L4: 2.4nH; L_0402_1005Metric_Pad0.77x0.64mm_HandSolder; Digikey Part Number 490-8389-1-ND
L5, L6: 3.9nH; L_0402_1005Metric_Pad0.77x0.64mm_HandSolder; Digikey Part Number 490-2617-1-ND
L7, L10: 2nH; L_0402_1005Metric_Pad0.77x0.64mm_HandSolder; Digikey Part Number 490-6569-1-ND
L8: 22nH; L_0402_1005Metric_Pad0.77x0.64mm_HandSolder; Digikey Part Number 490-2627-1-ND
L9, L11: 10nH; L_0402_1005Metric_Pad0.77x0.64mm_HandSolder; Digikey Part Number 490-2623-1-ND
L12: 9.1nH; L_0402_1005Metric_Pad0.77x0.64mm_HandSolder; Digikey Part Number 490-8390-1-ND
U2: 0.8Ghz_and_2.4GHz_Filter; DPX252690DT-5032B1; Digikey Part Number 445-174204-1-ND
U3: SMA_Antenna; SMA_Amphenol_132134-16_Vertical; Digikey Part Number ACX1230-ND

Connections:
/ZigBeeFiltering/2_4_GHZ_RF_N: C18.1, L2.2, L4.1; also elsewhere on the board
/ZigBeeFiltering/2_4_GHZ_RF_P: C19.1, L2.1, L3.2; also elsewhere on the board
/ZigBeeFiltering/RX_TX: C17.2, C22.2, L3.1, L9.1; also elsewhere on the board
/ZigBeeFiltering/SUB-1_GHZ_RF_N: L6.1; also elsewhere on the board
/ZigBeeFiltering/SUB-1_GHZ_RF_P: L5.1; also elsewhere on the board
GND: C17.1, C18.2, C21.2, C22.1, C23.2, C25.2, C27.2, C28.2, U2.1 (GND), U2.2 (GND), U2.4 (GND), U2.6 (GND), U2.7 (GND), U3.2 (GND); also elsewhere on the board
unnamed: C19.2, L4.2, L7.1
unnamed: C20.1, C24.1, L5.2, L8.1, L9.2
unnamed: C20.2, C23.1, L6.2, L8.2, L11.1
unnamed: C21.1, L7.2, L10.1
unnamed: C24.2, C27.1, L11.2, L12.1
unnamed: C25.1, C26.1, L10.2
unnamed: C26.2, U2.5 (High-Band)
unnamed: C28.1, C29.1, L12.2
unnamed: C29.2, U2.8 (Low-Band)
unnamed: C31.1, U2.3 (Com)
unnamed: C31.2, U3.1 (INPUT)

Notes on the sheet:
Zigbee

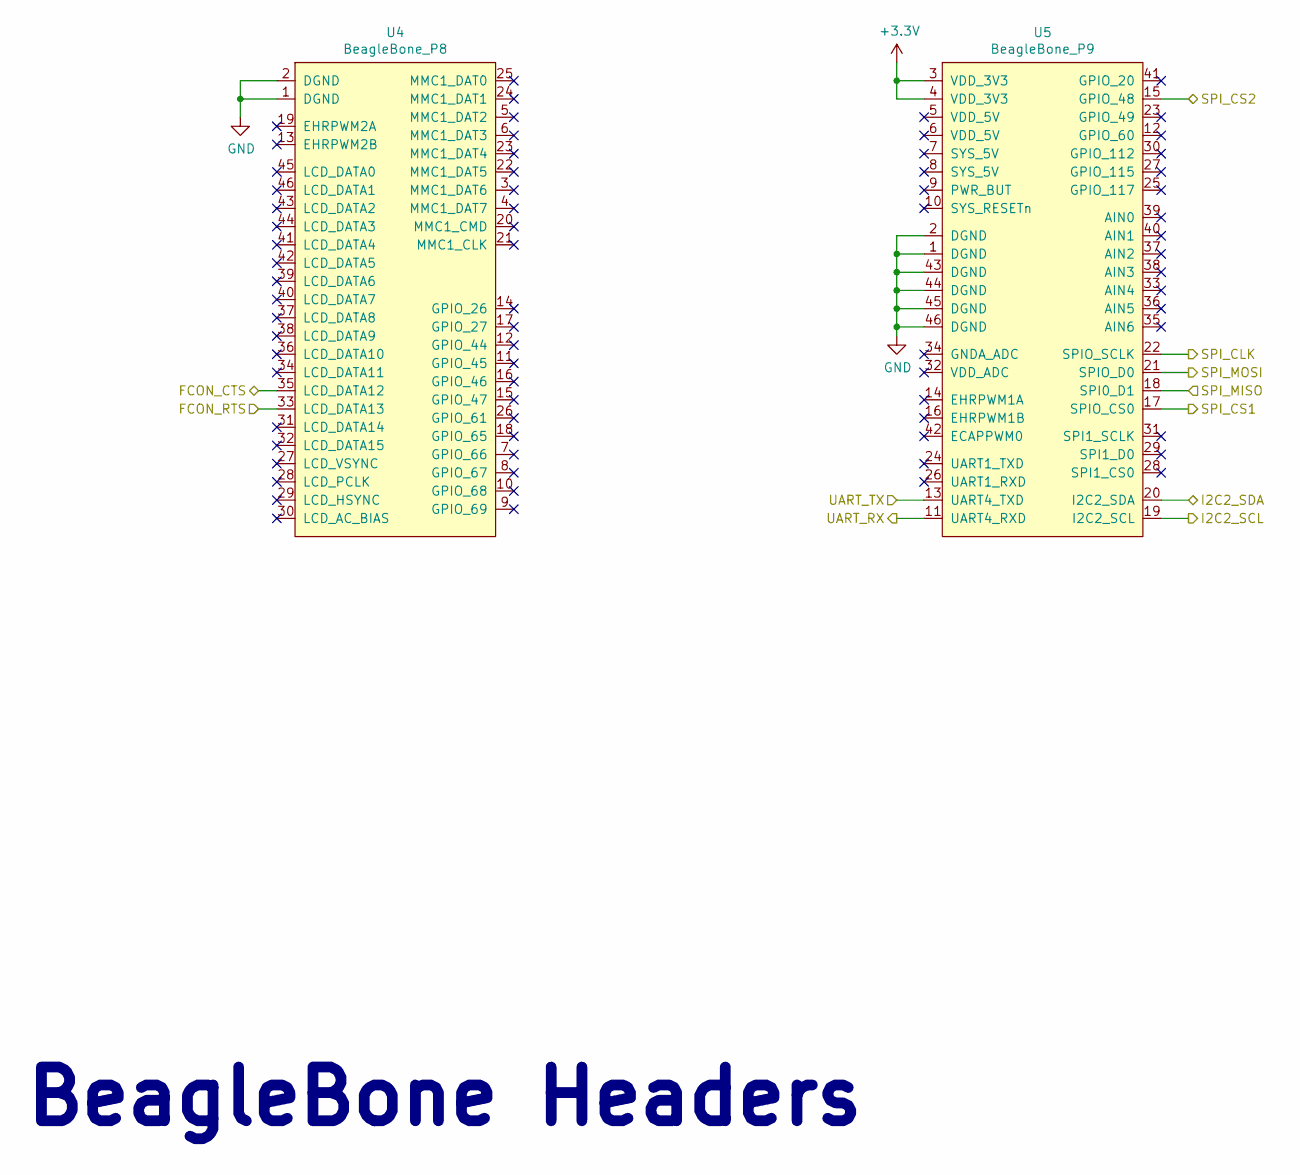
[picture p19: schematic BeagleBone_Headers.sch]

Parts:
U4: BeagleBone_P8; PinHeader_2x23_P2.54mm_Vertical; Digikey Part Number 1528-1365-ND
U5: BeagleBone_P9; PinHeader_2x23_P2.54mm_Vertical

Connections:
+3V3: U5.3 (VDD_3V3), U5.4 (VDD_3V3); also elsewhere on the board
FCON_CTS: U4.35 (LCD_DATA12); also elsewhere on the board
FCON_RTS: U4.33 (LCD_DATA13); also elsewhere on the board
GND: U4.1 (DGND), U4.2 (DGND), U5.1 (DGND), U5.2 (DGND), U5.43 (DGND), U5.44 (DGND), U5.45 (DGND), U5.46 (DGND); also elsewhere on the board
I2C_SCL: U5.19 (I2C2_SCL); also elsewhere on the board
I2C_SDA: U5.20 (I2C2_SDA); also elsewhere on the board
SPI_CLK: U5.22 (SPIO_SCLK); also elsewhere on the board
SPI_CS1: U5.17 (SPIO_CS0); also elsewhere on the board
SPI_CS2: U5.15 (GPIO_48); also elsewhere on the board
SPI_MISO: U5.18 (SPI0_D1); also elsewhere on the board
SPI_MOSI: U5.21 (SPIO_D0); also elsewhere on the board
UART_RX: U5.11 (UART4_RXD); also elsewhere on the board
UART_TX: U5.13 (UART4_TXD); also elsewhere on the board

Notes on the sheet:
BeagleBone Headers

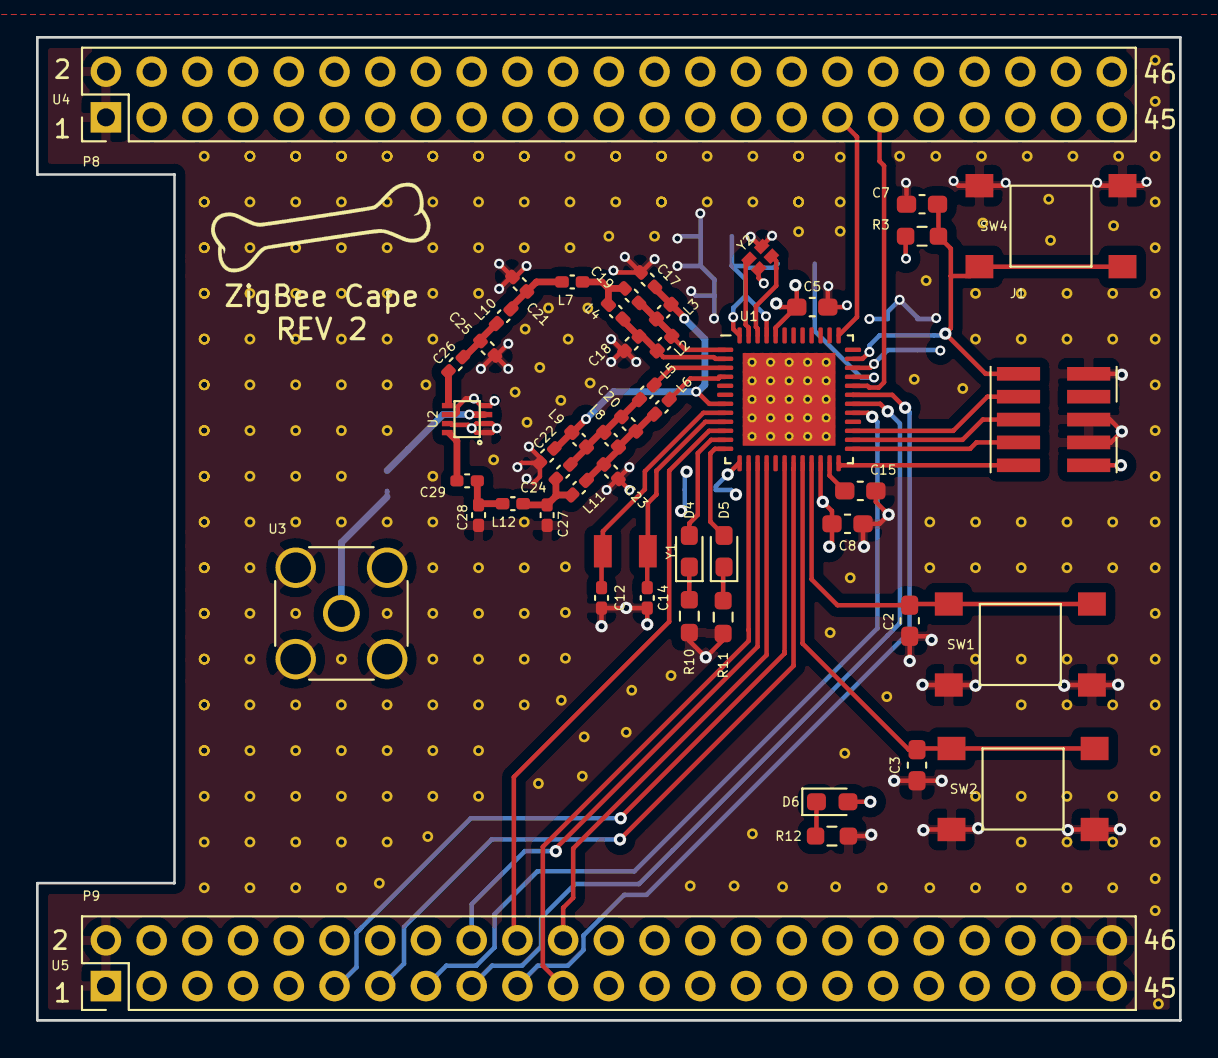
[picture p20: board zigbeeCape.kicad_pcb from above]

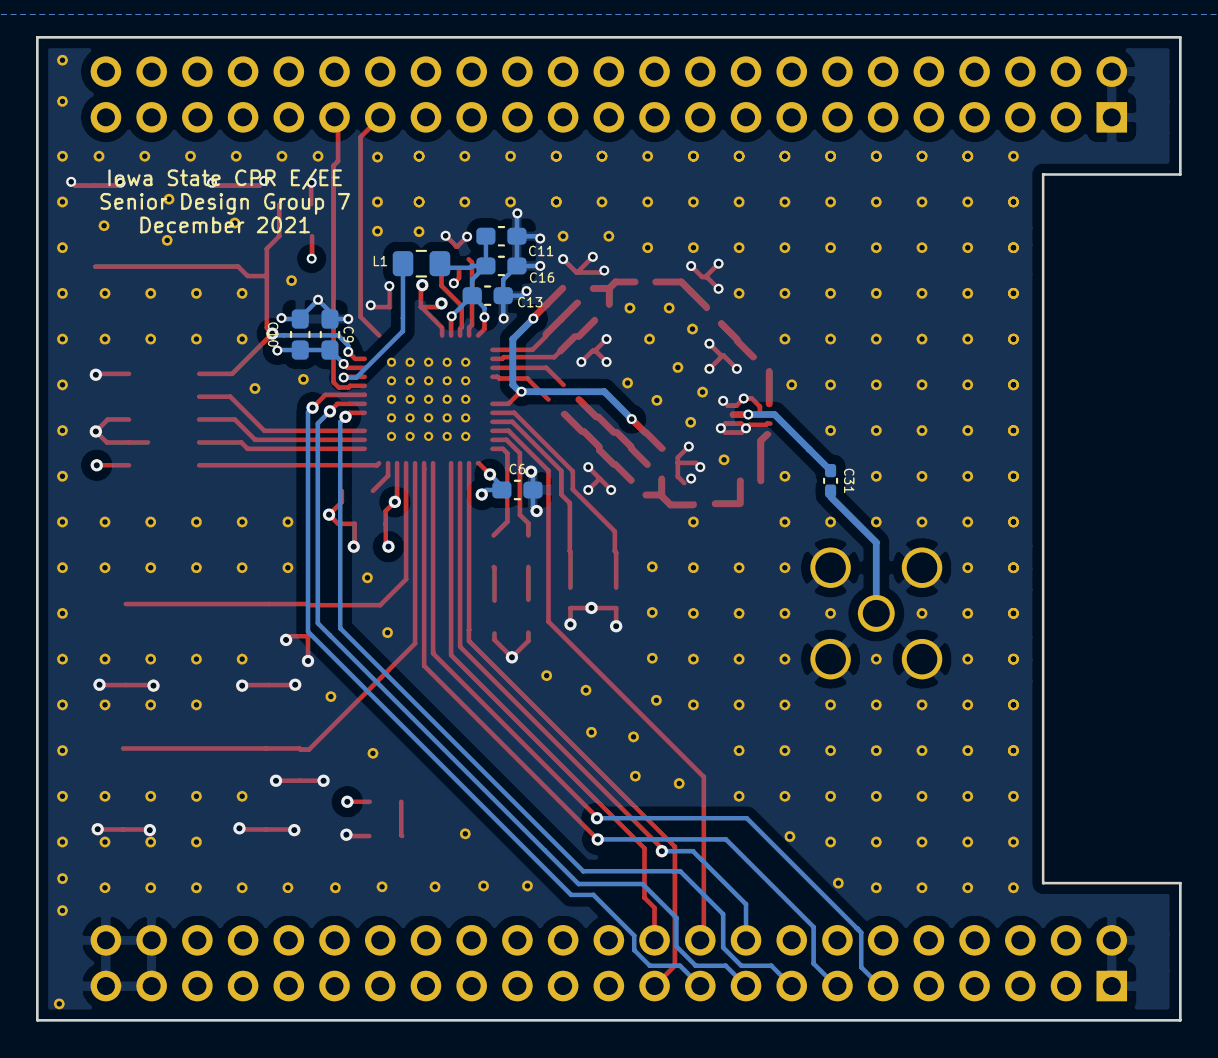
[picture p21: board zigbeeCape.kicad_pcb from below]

Board: 4 copper layers, 63.5 x 54.6 mm, 58 parts (8 on the bottom side), 48 nets.

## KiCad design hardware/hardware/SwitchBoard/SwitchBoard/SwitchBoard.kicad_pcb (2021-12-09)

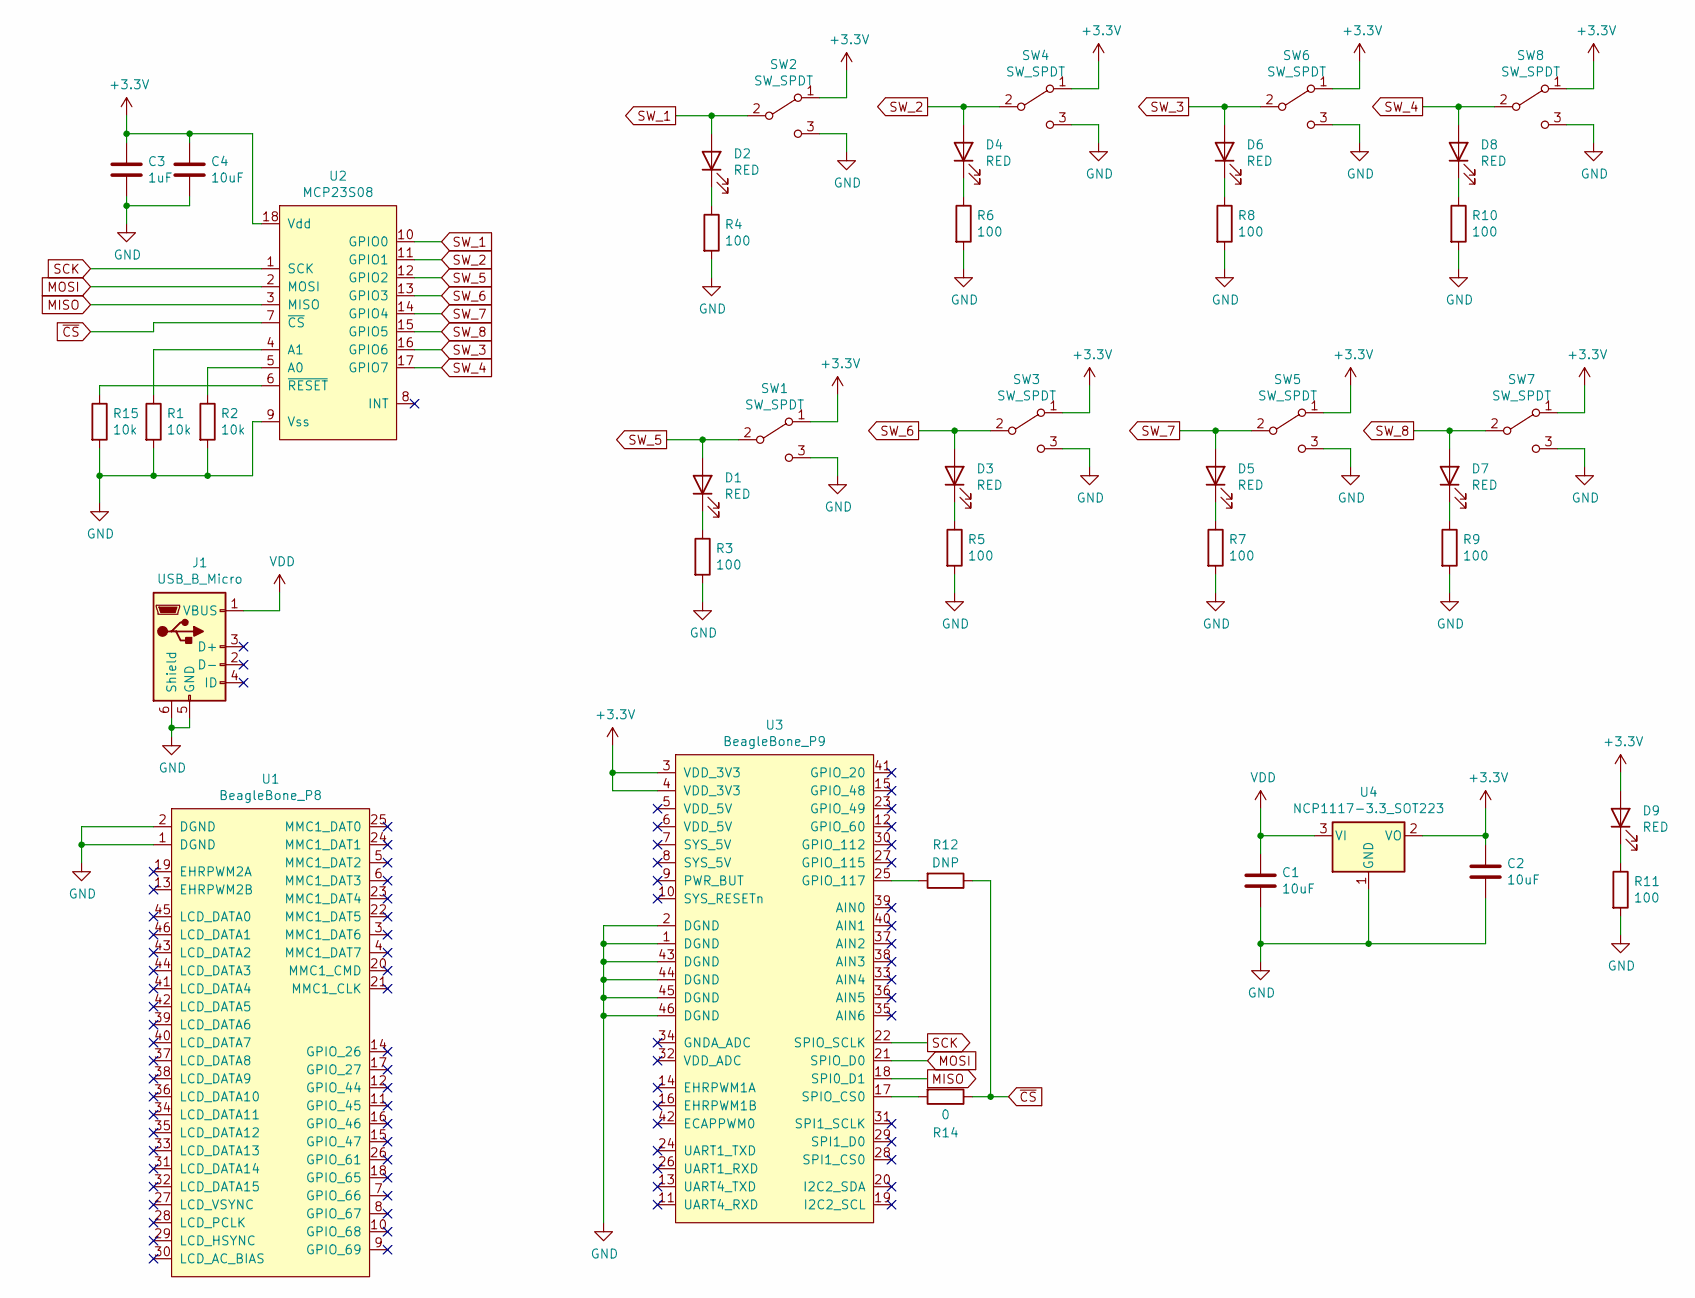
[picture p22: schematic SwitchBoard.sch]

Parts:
C1, C2, C4: 10uF; C_0603_1608Metric_Pad1.08x0.95mm_HandSolder; Digikey Part Number 1276-1038-1-ND
C3: 1uF; C_0603_1608Metric_Pad1.08x0.95mm_HandSolder; Digikey Part Number 311-1372-1-ND
D1, D2, D3, D4, D5, D6, D7, D8, D9: RED; D_0603_1608Metric_Pad1.05x0.95mm_HandSolder; Digikey Part Number 732-4978-1-ND
J1: USB_B_Micro; UJ2-MIBH2-4-SMT-TR; Digikey Part Number 102-4007-1-ND
R1, R2, R15: 10k; R_0603_1608Metric_Pad0.98x0.95mm_HandSolder; Digikey Part Number RMCF0603FT10K0CT-ND
R3, R4, R5, R6, R7, R8, R9, R10, R11: 100; R_0603_1608Metric_Pad0.98x0.95mm_HandSolder; Digikey Part Number 118-CR0603AFX-1000ELFCT-ND
R12: DNP; R_0603_1608Metric_Pad0.98x0.95mm_HandSolder
R14: 0; R_0603_1608Metric_Pad0.98x0.95mm_HandSolder; Digikey Part Number 541-0.0GCT-ND
SW1, SW2, SW3, SW4, SW5, SW6, SW7, SW8: SW_SPDT; DPDT; Digikey Part Number 401-2002-1-ND
U1: BeagleBone_P8; PinHeader_2x23_P2.54mm_Vertical; Digikey Part Number 1528-1365-ND
U2: MCP23S08; SOIC-18W_7.5x11.6mm_P1.27mm; Digikey Part Number MCP23S08-E/SO-ND
U3: BeagleBone_P9; PinHeader_2x23_P2.54mm_Vertical; Digikey Part Number NA
U4: NCP1117-3.3_SOT223; SOT-223-3_TabPin2; Digikey Part Number NCP1117ST33T3GOSCT-ND

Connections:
+3V3: C2.1, C3.1, C4.1, D9.2 (A), SW1.1 (A), SW2.1 (A), SW3.1 (A), SW4.1 (A), SW5.1 (A), SW6.1 (A), SW7.1 (A), SW8.1 (A), U2.18 (Vdd), U3.3 (VDD_3V3), U3.4 (VDD_3V3), U4.2 (VO)
GND: C1.2, C2.2, C3.2, C4.2, J1.5 (GND), J1.6 (Shield), R1.2, R2.2, R3.2, R4.2, R5.2, R6.2, R7.2, R8.2, R9.2, R10.2, R11.2, R15.2, SW1.3 (C), SW2.3 (C), SW3.3 (C), SW4.3 (C), SW5.3 (C), SW6.3 (C), SW7.3 (C), SW8.3 (C), U1.1 (DGND), U1.2 (DGND), U2.9 (Vss), U3.1 (DGND), U3.2 (DGND), U3.43 (DGND), U3.44 (DGND), U3.45 (DGND), U3.46 (DGND), U4.1 (GND)
MISO: U2.3 (MISO), U3.18 (SPI0_D1)
MOSI: U2.2 (MOSI), U3.21 (SPIO_D0)
unnamed: D1.1 (K), R3.1
unnamed: D2.1 (K), R4.1
unnamed: D3.1 (K), R5.1
unnamed: D4.1 (K), R6.1
unnamed: D5.1 (K), R7.1
unnamed: D6.1 (K), R8.1
unnamed: D7.1 (K), R9.1
unnamed: D8.1 (K), R10.1
unnamed: D9.1 (K), R11.1
unnamed: R1.1, U2.4 (A1)
unnamed: R2.1, U2.5 (A0)
unnamed: R12.2, U3.25 (GPIO_117)
unnamed: R14.2, U3.17 (SPIO_CS0)
unnamed: R15.1, U2.6 (~RESET)
SCK: U2.1 (SCK), U3.22 (SPIO_SCLK)
SW_1: D2.2 (A), SW2.2 (B), U2.10 (GPIO0)
SW_2: D4.2 (A), SW4.2 (B), U2.11 (GPIO1)
SW_3: D6.2 (A), SW6.2 (B), U2.16 (GPIO6)
SW_4: D8.2 (A), SW8.2 (B), U2.17 (GPIO7)
SW_5: D1.2 (A), SW1.2 (B), U2.12 (GPIO2)
SW_6: D3.2 (A), SW3.2 (B), U2.13 (GPIO3)
SW_7: D5.2 (A), SW5.2 (B), U2.14 (GPIO4)
SW_8: D7.2 (A), SW7.2 (B), U2.15 (GPIO5)
VDD: C1.1, J1.1 (VBUS), U4.3 (VI)
~CS: R12.1, R14.1, U2.7 (~CS)

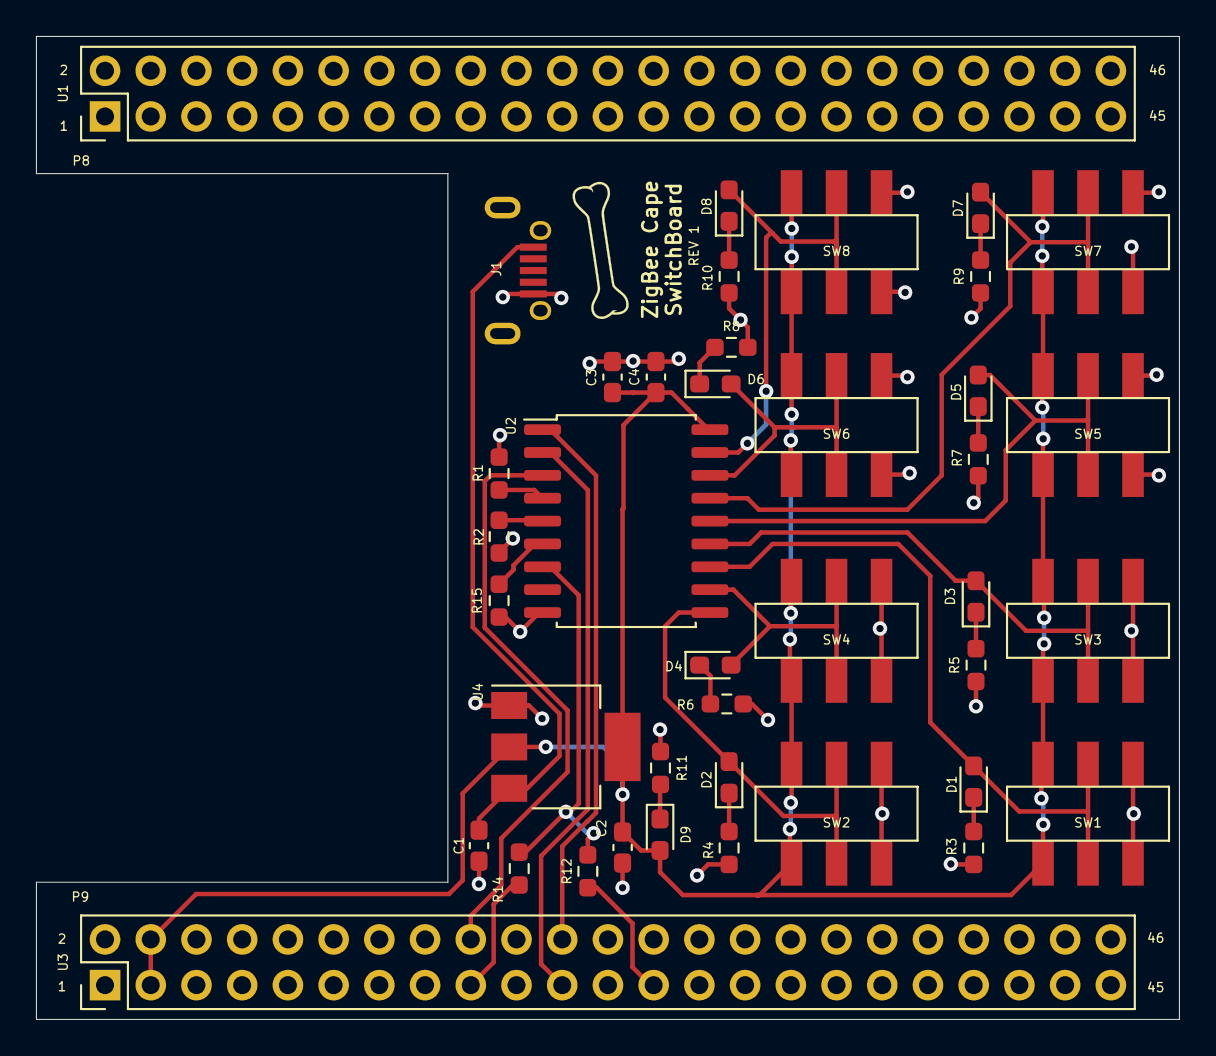
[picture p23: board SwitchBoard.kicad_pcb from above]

Board: 2 copper layers, 63.5 x 54.6 mm, 40 parts (0 on the bottom side), 29 nets.

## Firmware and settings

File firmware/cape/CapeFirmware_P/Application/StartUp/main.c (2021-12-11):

/******************************************************************************

 @file main.c

 @brief main entry of the example application

 Group: WCS LPC
 Target Device: CC2652

 ******************************************************************************

 Copyright (c) 2016-2017, Texas Instruments Incorporated
 All rights reserved.

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
 *  Neither the name of Texas Instruments Incorporated nor the names of
    its contributors may be used to endorse or promote products derived
    from this software without specific prior written permission.

 THIS SOFTWARE IS PROVIDED BY THE COPYRIGHT HOLDERS AND CONTRIBUTORS "AS IS"
 AND ANY EXPRESS OR IMPLIED WARRANTIES, INCLUDING, BUT NOT LIMITED TO,
 THE IMPLIED WARRANTIES OF MERCHANTABILITY AND FITNESS FOR A PARTICULAR
 PURPOSE ARE DISCLAIMED. IN NO EVENT SHALL THE COPYRIGHT OWNER OR
 CONTRIBUTORS BE LIABLE FOR ANY DIRECT, INDIRECT, INCIDENTAL, SPECIAL,
 EXEMPLARY, OR CONSEQUENTIAL DAMAGES (INCLUDING, BUT NOT LIMITED TO,
 PROCUREMENT OF SUBSTITUTE GOODS OR SERVICES; LOSS OF USE, DATA, OR PROFITS;
 OR BUSINESS INTERRUPTION) HOWEVER CAUSED AND ON ANY THEORY OF LIABILITY,
 WHETHER IN CONTRACT, STRICT LIABILITY, OR TORT (INCLUDING NEGLIGENCE OR
 OTHERWISE) ARISING IN ANY WAY OUT OF THE USE OF THIS SOFTWARE,
 EVEN IF ADVISED OF THE POSSIBILITY OF SUCH DAMAGE.

 ******************************************************************************
 Release Name: simplelink_zigbee_sdk_plugin_0_95_00_18_s
 Release Date: 2017-11-10 13:43:40
 *****************************************************************************/

/******************************************************************************
 Includes
 *****************************************************************************/

#include <stdint.h>
#include <string.h>
#include <unistd.h>
#include <xdc/std.h>

#include <xdc/runtime/Error.h>
#include <xdc/runtime/System.h>
#include <ti/sysbios/knl/Semaphore.h>
#include <ti/sysbios/BIOS.h>
#include <ti/sysbios/knl/Task.h>

#include <ioc.h>

#include "sys_ctrl.h"

#include "ti_drivers_config.h"
#include <inc/hw_ccfg.h>
#include <inc/hw_ccfg_simple_struct.h>

#include <ti/drivers/Board.h>
/* Header files required for the temporary idle task function */
#include <ti/drivers/Power.h>
#include <ti/drivers/power/PowerCC26XX.h>
#include <aon_rtc.h>
#include <prcm.h>

/* POSIX Header files */
#include <pthread.h>
#include <semaphore.h>

#ifndef TIMAC_ROM_IMAGE_BUILD
#include "crypto_mac_api.h"
#endif
#include <chipinfo.h>

/* Header files required to enable instruction fetch cache */
#include <vims.h>
#include <hw_memmap.h>

#include <ti/sysbios/hal/Hwi.h>

#include "cpu.h"

#include "nvocmp.h"

#include "zstackconfig.h"

#ifdef ZSTACK_GPD
#include "macTask.h"
#else
#include "zstackstartup.h"
#include "zstackapi.h"
#endif

#ifndef CUI_DISABLE
#include "cui.h"
#endif

#include "ti_zstack_config.h"

/******************************************************************************
 Constants
 *****************************************************************************/
#define CONFIG_PHY_ID 0

/* Assert Reasons */
#define MAIN_ASSERT_STACK        2
#define MAIN_ASSERT_MAC          3
#define MAIN_ASSERT_HWI_TIRTOS   4

#define RFC_MODE_BLE                 PRCM_RFCMODESEL_CURR_MODE1
#define RFC_MODE_IEEE                PRCM_RFCMODESEL_CURR_MODE2
#define RFC_MODE_ANT                 PRCM_RFCMODESEL_CURR_MODE4
#define RFC_MODE_EVERYTHING_BUT_ANT  PRCM_RFCMODESEL_CURR_MODE5
#define RFC_MODE_EVERYTHING          PRCM_RFCMODESEL_CURR_MODE6

/* Extended Address offset in FCFG (LSB..MSB) */
#define EXTADDR_OFFSET 0x2F0

#define THREADSTACKSIZE    1024
#define APP_TASK_STACK_SIZE 3000

#define SET_RFC_MODE(mode) HWREG( PRCM_BASE + PRCM_O_RFCMODESEL ) = (mode)

// Exented Address Length
#define EXTADDR_LEN 8

// Macro used to break a uint32_t into individual bytes
//#define BREAK_UINT32(var, ByteNum) \
//    (uint8_t)((uint32_t)(((var) >> ((ByteNum) * 8)) & 0x00FF))

/******************************************************************************
 External Variables
 *****************************************************************************/

#ifdef ZSTACK_GPD
extern ApiMac_sAddrExt_t ApiMac_extAddr;
#endif

/******************************************************************************
 Global Variables
 *****************************************************************************/

// ZNP does not need an application task
#ifndef ZNP_NPI
Task_Struct myTask;
Char myTaskStack[APP_TASK_STACK_SIZE];
#endif

#ifndef TIMAC_ROM_IMAGE_BUILD
/* Crypto driver function table */
uint32_t *macCryptoDrvTblPtr = (uint32_t*)macCryptoDriverTable;
#endif

/*
 When assert happens, this field will be filled with the reason:
       MAIN_ASSERT_HWI_TIRTOS,
       MAIN_ASSERT_STACK,
       MAIN_ASSERT_MAC
 */
uint8_t Main_assertReason = 0;

/******************************************************************************
 * ZStack Configuration Structure
 */
zstack_Config_t zstack_user0Cfg =
{
    {0, 0, 0, 0, 0, 0, 0, 0}, // Extended Address
    {0, 0, 0, 0, 0, 0, 0, 0}, // NV function pointers
    0,                        // Application thread ID
    0,                        // stack image init fail flag
    MAC_USER_CFG
};

/* Stack TIRTOS Task semaphore */
Semaphore_Struct npiInitializationMutex;
Semaphore_Handle npiInitializationMutexHandle;

/******************************************************************************
 Local Variables
 *****************************************************************************/

#ifdef ZSTACK_GPD
uint8_t _macTaskId;
#elif !defined (ZNP_NPI)
static uint8_t stackServiceTaskId;
#endif

/*!
 * @brief       Fill in your own assert function.
 *
 * @param       assertReason - reason: MAIN_ASSERT_HWI_TIRTOS,
 *                                     MAIN_ASSERT_STACK, or
 *                                     MAIN_ASSERT_MAC
 */
void Main_assertHandler(uint8_t assertReason)
{
    Main_assertReason = assertReason;

#if defined(RESET_ASSERT)
     /* Pull the plug and start over */
    SysCtrlSystemReset();
#else
    Hwi_disable();
    char assertLine[21] = {'\0'};
    System_snprintf(assertLine, 21, "[Assert Reason] 0x%02X", assertReason);
    while(1)
    {
        /* Put you code here to do something if in assert */
        #ifndef CUI_DISABLE
        CUI_assert(assertLine, TRUE);
        #endif
    }
#endif
}

/*!
 * @brief       Main task function
 *
 * @param       a0 -
 * @param       a1 -
 */
#ifndef ZNP_NPI
Void taskFxn(UArg a0, UArg a1)
{
#if defined(USE_CACHE_RAM)
    /* Retain the Cache RAM */
    Power_setConstraint(PowerCC26XX_SB_VIMS_CACHE_RETAIN);
#endif

#ifdef ZSTACK_GPD

#else
    /* get the service taskId of the Stack */
    stackServiceTaskId = stackTask_getStackServiceId();
    /* configure the message API the application will use to communicate with
       the stack */
    Zstackapi_init(stackServiceTaskId);
#endif

    /* Kick off application */
    extern void sampleApp_task(NVINTF_nvFuncts_t *pfnNV);
    sampleApp_task(&zstack_user0Cfg.nvFps);
}

#endif

/*!
 * @brief       TIRTOS HWI Handler.  The name of this function is set to
 *              M3Hwi.excHandlerFunc in app.cfg, you can disable this by
 *              setting it to null.
 *
 * @param       excStack - TIROS variable
 * @param       lr - TIROS variable
 */
xdc_Void Main_excHandler(UInt *excStack, UInt lr)
{
    /* User defined function */
    Main_assertHandler(MAIN_ASSERT_HWI_TIRTOS);
}

/*!
 * @brief       HAL assert handler required by OSAL memory module.
 */
void assertHandler(void)
{
    /* User defined function */
    Main_assertHandler(MAIN_ASSERT_MAC);
}

/*!
 * @brief       Callback function when voltage is lower than NVOCMP_MIN_VDD_FLASH_MV
 *              during an NV write operation
 *
 * @param       voltage - Measured device voltage
 */
#ifdef NVOCMP_MIN_VDD_FLASH_MV
void Main_lowVoltageCb(uint32_t voltage)
{
    /* Implement any safety precautions for application due to low voltage detected */
}
#endif

/*!
 * @brief       "main()" function - starting point
 */
int main()
{

#ifndef USE_DEFAULT_USER_CFG
    zstack_user0Cfg.macConfig.pAssertFP = assertHandler;
#endif

    /* enable iCache prefetching */
    VIMSConfigure(VIMS_BASE, TRUE, TRUE);

#if defined(USE_CACHE_RAM)
    /* Disable cache */
    VIMSModeSet( VIMS_BASE, VIMS_MODE_DISABLED);
#else
    /* Enable cache */
    VIMSModeSet( VIMS_BASE, VIMS_MODE_ENABLED);
#endif

    /*
     Initialization for board related stuff such as LEDs
     following TI-RTOS convention
     */
    //Board_init(); //replaced Board_initGeneral() with Board_init();
    Board_initGeneral();

// OTA client projects use BIM, so CCFG isn't present in this image
#if !((defined OTA_CLIENT_STANDALONE) || (defined OTA_CLIENT_INTEGRATED))
    /*
     * Copy the extended address from the CCFG area
     * Assumption: the memory in CCFG_IEEE_MAC_0 and CCFG_IEEE_MAC_1
     * is contiguous and LSB first.
     */
    /* Used to check for a valid extended address */
    static const uint8_t dummyExtAddr[] =
        { 0xFF, 0xFF, 0xFF, 0xFF, 0xFF, 0xFF, 0xFF, 0xFF };

    OsalPort_memcpy(zstack_user0Cfg.extendedAddress, (uint8_t *)&(__ccfg.CCFG_IEEE_MAC_0),
           (APIMAC_SADDR_EXT_LEN));
    /* Check to see if the CCFG IEEE is valid */
    if(memcmp(zstack_user0Cfg.extendedAddress, dummyExtAddr, APIMAC_SADDR_EXT_LEN) == 0)
#endif // (defined OTA_CLIENT_STANDALONE) || (defined OTA_CLIENT_INTEGRATED
    {
        /* No, it isn't valid.  Get the Primary IEEE Address */
        OsalPort_memcpy(zstack_user0Cfg.extendedAddress, (uint8_t *)(FCFG1_BASE + EXTADDR_OFFSET),
                       (APIMAC_SADDR_EXT_LEN));
    }

    /* Setup the NV driver */
    NVOCMP_loadApiPtrs(&zstack_user0Cfg.nvFps);
#ifdef NVOCMP_MIN_VDD_FLASH_MV
    NVOCMP_setLowVoltageCb(&Main_lowVoltageCb);
#endif
    if(zstack_user0Cfg.nvFps.initNV)
    {
        zstack_user0Cfg.nvFps.initNV(NULL);
    }

#ifdef ZSTACK_GPD
    OsalPort_memcpy(ApiMac_extAddr, zstack_user0Cfg.extendedAddress,
           (APIMAC_SADDR_EXT_LEN));
    _macTaskId = macTaskInit(&zstack_user0Cfg.macConfig);
#else
    /* configure stack task */
    stackTask_init(&zstack_user0Cfg);
#endif // ZSTACK_GPD

#ifdef NPI
    extern void NPITask_createTask(void);
    NPITask_createTask();

    Semaphore_Params semParam;
    Semaphore_Params_init(&semParam);
    semParam.mode = ti_sysbios_knl_Semaphore_Mode_COUNTING;
    Semaphore_construct(&npiInitializationMutex, 0, &semParam);
    npiInitializationMutexHandle = Semaphore_handle(&npiInitializationMutex);
#endif

// ZNP does not need an application task
#ifndef ZNP_NPI

#ifndef CUI_DISABLE
    CUI_params_t cuiParams;

    CUI_paramsInit(&cuiParams);
    CUI_init(&cuiParams);
#endif
    Task_Params taskParams;

    /* Configure app task. */
    Task_Params_init(&taskParams);
    taskParams.stack = myTaskStack;
    taskParams.stackSize = APP_TASK_STACK_SIZE;
    taskParams.priority = 2;
    Task_construct(&myTask, taskFxn, &taskParams, NULL);

#endif

#ifdef DEBUG_SW_TRACE
    IOCPortConfigureSet(IOID_8, IOC_PORT_RFC_TRC, IOC_STD_OUTPUT
                    | IOC_CURRENT_4MA | IOC_SLEW_ENABLE);
#endif /* DEBUG_SW_TRACE */

    BIOS_start(); /* enable interrupts and start SYS/BIOS */

    return 0; // never executed
}

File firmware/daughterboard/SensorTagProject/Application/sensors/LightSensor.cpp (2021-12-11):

#include <unistd.h>
#include <stdio.h>
#include <string.h>

/* Driver Header files */
#include <ti/drivers/GPIO.h>
#include <ti/drivers/I2C.h>
#include <ti/display/Display.h>

/* Threading header files */
#include <pthread.h>
#include <semaphore.h>

/* Include OPT3001 driver file */
#include "OPT3001.h"

/* Include Common sensor file */
#include "SensorStructure.h"

/* Driver Configuration */
#include "ti_drivers_config.h"


/* Thread function prototypes */
extern "C" {
    void  *mainThread(void *arg0);
}

extern uint16_t sensor_data;
extern char sensor_status[16];


static OPT3001 opt3001;

/*
 * These values narrow the limits of the sensor to
 * allow those running the example to test the interrupt feature
 */
#define TEMPORARY_LOWLIMIT   30
#define TEMPORARY_HIGHLIMIT  4000

/* Number of samples to read from the sensor */
#define NUM_SAMPLES 600000

/* Stack size in bytes */
#define ALARMTHREADSTACKSIZE  512

/* Range of possible I2C slave addresses */
#define MIN_ADDRESS         0x08
#define MAX_ADDRESS         0x78

/*
 * mainThread is the function that will run the sensor continuously. It used PThreads and depends on the OPT3001 sensor files
 */
void *mainThread(void *arg0)
{
    strcpy(sensor_status,"STARTING");
    uint16_t sample;
    int32_t luxValue;
    uint8_t data;
    uint8_t addr;

    /* I2C structures*/
    I2C_Handle      i2c;
    I2C_Params      i2cParams;
    I2C_Transaction i2cTransaction;

    /* Alarm pthread structures */
    pthread_attr_t      attrs;
    struct sched_param  priParam;
    int                 retc;

    /* Call driver init functions */
    GPIO_init();
    I2C_init();

    /* Initialize the alarm thread attributes structure with default values */
    pthread_attr_init(&attrs);

    /* Set priority, detach state, and stack size attributes for alarm thread */
    priParam.sched_priority = 2;
    retc = pthread_attr_setschedparam(&attrs, &priParam);
    retc |= pthread_attr_setdetachstate(&attrs, PTHREAD_CREATE_DETACHED);
    if (retc != 0) {
        /* Failed to set attributes */
        strcpy(sensor_status,"FAILED");
        while (1) {}
    }


    /*
     * Set OPT3001 Power pin to high (give device power) and then sleep briefly
     * to allow device to power up
     */
    GPIO_setConfig(CONFIG_GPIO_OPT3001_POWER,
        GPIO_CFG_OUT_STD | GPIO_CFG_OUT_HIGH);
    sleep(1);

    /* Create I2C for usage */
    I2C_Params_init(&i2cParams);
    i2cParams.bitRate = I2C_400kHz;
    i2c = I2C_open(CONFIG_I2C_OPT3001, &i2cParams);
    if (i2c == NULL) {
        strcpy(sensor_status,"FAILED");
        while (1);
    }

    /* Setup transaction to find slave devices */
    i2cTransaction.writeBuf = &data;
    i2cTransaction.writeCount = 1;
    i2cTransaction.readBuf = &data;
    i2cTransaction.readCount = 0;
    data = 0;

    /*
     * Attempt transaction with every possible slave address. If a transaction
     * returns successfully, then that slave address is valid and will be
     * printed to the console.
     */
    for (addr = MIN_ADDRESS; addr < MAX_ADDRESS; addr++) {
        i2cTransaction.slaveAddress = addr;
    }

    /* Make instance of OPT3001 and then enable the interrupt pin */
    if(!opt3001.init(i2c, OPT3001::SlaveAddress::ADDRPIN_GND))
    {
        strcpy(sensor_status,"FAILED");
        while (1);
    }
    GPIO_enableInt(CONFIG_GPIO_OPT3001_INTERRUPT);

    /* Configure the LED Pin and turn on user LED */
    GPIO_setConfig(CONFIG_GPIO_RLED, GPIO_CFG_OUT_STD | GPIO_CFG_OUT_LOW);
    GPIO_write(CONFIG_GPIO_RLED, CONFIG_GPIO_LED_ON);

    opt3001.resetConfiguration();

    /* Set low limit & high limits */
    if(opt3001.setLowLimit(TEMPORARY_LOWLIMIT) &&
        opt3001.setHighLimit(TEMPORARY_HIGHLIMIT))
    {
        strcpy(sensor_status,"INITIALIZED");
    }
    else
    {
        strcpy(sensor_status,"FAILED");
        while(1);
    }

    /* Read data in continuous conversions mode */
    if(!opt3001.setConversionMode(OPT3001::ConversionMode::CONTINUOUS_CONVERSIONS))
    {
        strcpy(sensor_status,"FAILED");
        while(1);
    }

    // Slight Pause for Dramatic Effect
    sleep(3);

    /*
     * Read the OPT3001 sensor NUM_SAMPLES times and display the values.
     * Sleep between readings
     */
    while(1) {
//    for (sample = 1; sample <= NUM_SAMPLES; sample++) {

        /* Sleep between every sample */
        sleep(1);
        luxValue = opt3001.getResult();

        /* If -1 is returned from getResult(), then the I2C transaction failed */
        if(luxValue != -1)
        {
            strcpy(sensor_status,"READING");
            sensor_data = luxValue;
        }
    }

//    strcpy(sensor_status,"DONE");

    return (NULL);
}

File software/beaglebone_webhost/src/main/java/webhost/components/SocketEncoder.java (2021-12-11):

package webhost.components;

import com.fasterxml.jackson.core.JsonProcessingException;
import com.fasterxml.jackson.databind.ObjectMapper;
import org.apache.commons.logging.Log;
import org.apache.commons.logging.LogFactory;
import webhost.WebHostApplication;
import webhost.socket_wrappers.SocketReturnWrapper;

import javax.websocket.EncodeException;
import javax.websocket.Encoder;
import javax.websocket.EndpointConfig;

public class SocketEncoder implements Encoder.Text<SocketReturnWrapper> {

    /**
     * {@code Log} for this controller
     */
    private Log log = LogFactory.getLog(WebHostApplication.class);

    /**
     * {@code ObjectMapper} for this {@code Encoder}
     */
    private static ObjectMapper mapper = new ObjectMapper();

    @Override
    public String encode(SocketReturnWrapper wrap) throws EncodeException {

        try { return mapper.writeValueAsString(wrap); }
        catch (JsonProcessingException e) { log.error("SOCKET: encode exception", e.getCause()); }

        return null;
    }

    @Override
    public void init(EndpointConfig endpointConfig) {
        //custom init
    }

    @Override
    public void destroy() {
        //close resources
    }
}

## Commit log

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2021-03-22 Adding Zigbee cape project, hardware folder structure
    [zigbeeCape.kicad_pcb, zigbeeCape.sch]
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2021-03-29 Created symbol for CC1352R
    [zigbeeCape.sch]
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2021-04-06 Fixed LED names
    [zigbeeCape.sch]
2021-04-13 Added Most of Sub-1 Circuitry and most of Zigbee POwer Circuitry
    [BeagleBone_Headers.sch, ZigBeeFiltering.sch, zigbeeCape.sch]
2021-04-15 added footprint of CC1352R and PCB pin headers
    [zigbeeCape.kicad_pcb]
2021-04-16 Checked Schematic is correct. Added PCB outline and verified Pin spacing.
    [zigbeeCape.kicad_pcb]
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2021-04-19 More coms lines are complete.
    [zigbeeCape.sch]
2021-04-24 Checked Parkers work on the schematic. Added commentary to indicate capacitor use for VDDS
    [zigbeeCape.sch]
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2021-04-27 Added I2C pins, added signal wires to zigbee micro, fixed reset pin error
    [BeagleBone_Headers.sch, zigbeeCape.sch]
2021-04-28 Added beaglebone header heiarcy pins
    [BeagleBone_Headers.sch, zigbeeCape.sch]
2021-04-29 Assigned Pin types, cleaned stuff up, Fixed most errors from the DRC (questions on the last few)
    [BeagleBone_Headers.sch, ZigBeeFiltering.sch, zigbeeCape.sch]
2021-04-30 Added FL3 2.4ghz filter DPX252690DT-5032B1
    [ZigBeeFiltering.sch]
2021-04-30 Fixed a few little things
    [BeagleBone_Headers.sch, ZigBeeFiltering.sch, zigbeeCape.sch]
2021-05-02 Added CC1352 and Sample BOM
    [BOM_CC1352R1.XLSX, BOM_Sample.xlsx]
2021-05-02 Made Corrections from Schematic Review
    [Pins_Usage.xlsx, ZigBeeFiltering.sch, zigbeeCape.sch]
2021-05-02 Added Pin Usage Chart
    [Pins_Usage.xlsx]
2021-05-02 Fixing Git issue
    [BOM_CC1352R1.XLSX, BOM_Sample.xlsx, BeagleBone_Headers.sch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]
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2021-05-13 Added excell file to document deviations from CC1352R1 footprint size. Started assigning Footprints for Zigbee cape
    [Footprint substitutions for Zigbee Cape from CC1352R1.xlsx, ZigBeeFiltering.sch, zigbeeCape.sch]
2021-05-13 Added items to BOM. Added footprints to GIT. Finished Capacitor footprint association. Finished LED footprint association.
    [BOM_CC1352R1.XLSX, BOM_Rev1.xlsx, Footprint substitutions for Zigbee Cape from CC1352R1.xlsx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]
2021-05-14 Added all Capacitors to BOM
    [BOM_CC1352R1.XLSX, BOM_Rev1.xlsx]
2021-05-21 Completed BOM except unlabled DNM parts, labled in red. Completed footprint association except onboard antenae
    [BOM_CC1352R1.XLSX, BOM_Rev1.xlsx, BeagleBone_Headers.sch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]
2021-06-10 Updated R1 on schematic, Updated R1 on BOM, add alt for button
    [BOM_Rev1.xlsx, zigbeeCape.sch]
2021-06-27 Changed push button, Started layout
    [zigbeeCape.kicad_pcb, zigbeeCape.sch]
2021-06-30 Layout Planning done, uC Done
    [zigbeeCape.kicad_pcb, zigbeeCape.sch]
2021-07-01 Buttons, most LEDs are done
    [zigbeeCape.kicad_pcb, zigbeeCape.sch]
2021-07-01 Setup DRC, completed coms lines
    [ZigBeeFiltering.sch, zigbeeCape.kicad_pcb, zigbeeCape.sch]
2021-07-01 Finished ZigBee circuit, Removed PCB antenna
    [ZigBeeFiltering.sch, zigbeeCape.kicad_pcb]
2021-07-07 Fixed a couple schematic symbols
    [zigbeeCape.kicad_pcb, zigbeeCape.sch]
2021-07-07 Changed min via size, rerouted lan/wifi, cleaned up traces
    [BeagleBone_Headers.sch, zigbeeCape.kicad_pcb]
2021-07-07 Added Layout title and adjusted part refs
    [zigbeeCape.kicad_pcb]
2021-07-09 Post layout review 1 changes
    [ZigBeeFiltering.sch, zigbeeCape.kicad_pcb, zigbeeCape.sch]
2021-07-09 Add ViaStitch-0.6 part, started stitching gnd planes
    [zigbeeCape.kicad_pcb]
2021-08-02 Added more ground vias and silkscreen pin labels for the headers
    [zigbeeCape.kicad_pcb]
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2021-08-08 Added Impedance Info and Calcuations
    [zigbeeCape.kicad_pcb]
2021-08-09 Rerouted main ZigBee Lines
    [ZigBeeFiltering.sch, zigbeeCape.kicad_pcb]
2021-08-09 Changed micro for soldering
    [zigbeeCape.kicad_pcb]
2021-08-11 Almost done with traces
    [zigbeeCape.kicad_pcb]
2021-08-23 Updated BOM, small changes to PCB and schematic
    [BeagleBone_Headers.sch, SeniorDesignGroup7BOM.csv, ZigBeeFiltering.sch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]
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2021-08-25 Updated properties for faster BOM generation
    [BeagleBone_Headers.sch, ZigBeeFiltering.sch, zigbeeCape.sch]
2021-09-02 Finished traces, a couple problems with the design rules
    [zigbeeCape.kicad_pcb]
2021-09-02 added example ccs code
    [app.cfg]
2021-09-16 Fixed some trace spacing things
    [zigbeeCape.kicad_pcb, zigbeeCape.sch]
2021-09-16 Finished up the stitching vias
    [zigbeeCape.kicad_pcb]
2021-09-16 Fix silk screen, fixed via stitching net
    [zigbeeCape.kicad_pcb]
2021-09-23 Fixed micro footprint, changed impedance to jlc, add thermal relief
    [zigbeeCape.kicad_pcb]
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2021-09-27 Fixed micro, filter, push button footprints and fixed layout
    [zigbeeCape.kicad_pcb]
2021-09-28 Finished layout, checking highspeed before turning it in
    [zigbeeCape.kicad_pcb]
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2021-09-30 - Adding uart test code for cape and beaglebone - beaglebone UART1 sends a random character, cape echos character - Updating .gitignore for firmware - Re-organizing beaglebone test directories
    [ti_devices_config.obj, ti_drivers_config.obj]
2021-10-10 Added KiCad Project for Relay module. Relay Module schematic v1 ready.
    [BOM_CC1352R1.XLSX, BOM_Rev1.xlsx, BeagleBone_Headers.sch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]
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2021-10-24 - Adding more in-depth uart test projects and the start of a uart json project
    [ti_devices_config.obj, ti_drivers_config.obj]
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2021-11-15 - Adding CapeFirmware_R project (cape firmware compiled for CC1352R launchpad) - Adding tirtos project dependency - And more
    [app.cfg, m3_Hwi_asm.obj, m3_Hwi_asm_switch.obj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]
2021-11-15 - Updating CapeProject to get uart communication from cape -> bb working
    [m3_Hwi_asm.obj, m3_Hwi_asm_switch.obj, m3_IntrinsicsSupport_asm.obj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]
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2021-11-28 - Firmware updates for the cape - Cleaning firmware directory some more :P
    [af.obj, app.cfg, app_pem4f.cfg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]
2021-12-01 - Cleaning firmware folders - Updating cape projects - Updating cape tests
    [app.cfg, m3_Hwi_asm.obj, m3_Hwi_asm_switch.obj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]
2021-12-01 - Cleaning firmware folder some more - Re-adding desired projects after clean
    [af.obj, app_pem4f.cfg, app_pem4f.cfg.xml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]
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2021-12-07 Updated string sent over zigbee and fixed project
    [m3_Hwi_asm.obj, m3_Hwi_asm_switch.obj, m3_IntrinsicsSupport_asm.obj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]
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2021-12-11 - Cleaning project files - Updating beaglebone scripts - Adding LICENSE - Updating cape firmware
    [ti_devices_config.obj, ti_drivers_config.obj]
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2021-12-11 - Updating webhost project - Moving project files to correct places - Cleaning more files
    [main.c]
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
